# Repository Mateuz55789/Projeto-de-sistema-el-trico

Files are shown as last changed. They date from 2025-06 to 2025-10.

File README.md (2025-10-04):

# ⚡ Projeto de Sistema Elétrico Industrial

Este repositório apresenta o desenvolvimento completo de um sistema elétrico industrial de média/baixa tensão, realizado como trabalho final da disciplina de Projetos de Sistemas Elétricos do curso de Engenharia Elétrica no Centro Universitário Hermínio Ometto.  
O projeto foi desenvolvido para uma planta industrial de médio porte, simulada na cidade de Gramado/RS, atendendo aos requisitos técnicos da concessionária RGE (Grupo CPFL Energia) e seguindo as normas ABNT NBR 5410, NBR 14039, NBR 5356-11, GED-2855/2856, entre outras.

---

## 📌 Objetivos do Projeto

- Desenvolver uma solução elétrica completa e normatizada para uma planta industrial;  
- Atender com segurança e eficiência à demanda energética da instalação;  
- Garantir confiabilidade operacional, eficiência energética e conformidade normativa.

---

## 🔍 Conteúdo Técnico

O projeto abrange todas as etapas de planejamento elétrico, sendo essas:

### 🔌 Dimensionamento Elétrico

- Tabela de Cargas: potências ativas, reativas e aparentes de todos os equipamentos da planta;  
- Dimensionamento de Condutores e Disjuntores: seleção criteriosa com base em ampacidade, queda de tensão e seção mínima, conforme a NBR 5410;  
- Escolha de disjuntores.

### ⚙️ Partida de Motores

- Inversores de frequência CFW500 (WEG) para todos os motores das áreas produtivas;  
- Reatores de linha para mitigação de harmônicos e proteção dos inversores;  
- Proteções e disjuntores dedicados, conforme recomendações do fabricante.

### ⚡ Correção de Fator de Potência

- Dimensionamento e instalação de bancos de capacitores trifásicos (linha BCW - WEG);  
- Utilização de reatores de dessintonia (WEG DRW) e contatores CWBC para evitar ressonâncias;  
- Correção do fator de potência de 0,81 e 0,79 para 0,95, atendendo à resolução normativa da ANEEL.

### 🔄 Transformador e Subestação

- Transformador a seco de 1000 kVA (WEG) – ligação Dyn1, proteção IP-23;  
- Projeto de subestação abrigada, com entrada subterrânea e medição em média tensão;  
- Cálculo da margem de ampliação da carga (+35%) para o crescimento futuro da planta.

### ⚠️ Curto-Circuito

- Cálculos analíticos de corrente de curto-circuito trifásica e fase-terra;  
- Determinação da corrente de curto assimétrica e simulações com PSP-UFU;  
- Avaliação dos níveis de curto em todos os pontos críticos do sistema.

### 💡 Projeto Luminotécnico

- Simulação no Dialux Evo para ambiente de escritório industrial;  
- Definição de índice de reflexão, fator de depreciação, uniformidade e iluminância mínima;  
- Distribuição de 36 luminárias, garantindo 500 lux nas áreas de trabalho e 300 lux nos arredores, em conformidade com a NBR ISO/CIE 8995-1.

---

## 🛠️ Ferramentas Utilizadas

- Dialux Evo (simulação luminotécnica);  
- PSP-UFU (simulação de faltas e curtos);  
- AutoCAD (diagrama unifilar);
- Excel (cálculos).

---

## 👥 Integrantes do Grupo

- Emerson Falcão Albertini 
- Mateus Gomes Justino
- Bruno Henrique de Oliveira   
- Isaac Zulin Memari Espelho  

---

## 🏫 Instituição

Centro Universitário Hermínio Ometto – Araras/SP  
Curso: Engenharia Elétrica  
Período de entrega: Junho de 2025

---

## ⚠️ Restrições de Uso

Este projeto destina-se unicamente para fins didáticos e não deve ser utilizado em aplicações reais sem validação técnica profissional. Qualquer uso comercial, seja direto ou indireto, é estritamente proibido sem autorização expressa do autor. Para outras finalidades ou solicitações de uso que não se enquadrem nessas condições, por favor, entre em contato com o autor.

---

## ✉️ Contato

**Professor:** Daniel Augusto Pagi Ferreira  
**Email:** danielferreira@fho.edu.br

**Autor:** Mateus Gomes Justino  
**Email:** mateusjustino91@gmail.com  
**Linkedin:** www.linkedin.com/in/mateus-justino-ax01

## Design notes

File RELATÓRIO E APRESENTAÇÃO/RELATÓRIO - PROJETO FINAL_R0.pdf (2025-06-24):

CENTRO UNIVERSITÁRIO DA FUNDAÇÃO HERMÍNIO OMETTO

NÚCLEO DE ENGENHARIA

ENGENHARIA ELÉTRICA

Projetos de Sistemas Elétricos

P2

Nome completo | RA
Bruno Henrique de Oliveira | 109784
Emerson Falcão Albertini | 109667
Isaac Zulin Mamari Espelho Mateus Gomes Justino | 110490
| 109219

Araras

Junho 2025

## SUMÁRIO

### 1. INTRODUÇÃO

Este projeto tem como finalidade apresentar a proposta de implementação de um

sistema elétrico completo para uma indústria localizada na cidade de Gramado, no estado

do Rio Grande do Sul, sob concessão da empresa RGE – Rio Grande Energia. A RGE faz

parte do Grupo CPFL Energia, e por isso, adota as mesmas normas técnicas e padrões

exigidos pelo grupo, especialmente as normas GED-2855 (Fornecimento em Tensão

Primária – 15, 25 e 34,5 kV) e GED-2856 (Instalações de Subestação do Consumidor em

Média Tensão), aplicáveis ao fornecimento de energia em média tensão e à implantação

de subestações.

O trabalho foi desenvolvido em grupo, contemplando o dimensionamento,

especificação e planejamento da infraestrutura elétrica, com foco na segurança

operacional, eficiência energética e conformidade técnica. Para garantir a aderência às

exigências técnicas, foram aplicadas também as normas NBR 5356-11 (Transformadores

a seco – requisitos gerais) e NBR 14039 (Instalações elétricas de média tensão de 1 kV a

36,2 kV), que regulamentam os critérios construtivos e de instalação de equipamentos em

sistemas de média tensão.

Reconhecendo a importância de um ambiente industrial bem iluminado, o grupo

também desenvolveu um projeto luminotécnico completo, seguindo as diretrizes da

ABNT NBR ISO/CIE 8995-1, norma que estabelece os requisitos de iluminação para

ambientes de trabalho, garantindo conforto visual, segurança e desempenho adequado nas

áreas produtivas.

A demanda por soluções elétricas confiáveis e otimizadas é crescente,

especialmente em setores industriais com alto consumo de energia. Nesse contexto, o

grupo buscou atender às necessidades operacionais da planta, garantindo o fornecimento

adequado de energia para os equipamentos e processos, com o menor índice possível de

perdas, interrupções ou riscos elétricos.

O sistema foi projetado com base na NBR 5410, que regulamenta as instalações

elétricas de baixa tensão, e em outros requisitos técnicos aplicáveis. Foram considerados

critérios como o dimensionamento correto dos condutores e disjuntores, seleção de

inversores de frequência para motores, aplicação de dispositivos de proteção contra

sobrecorrente, curto-circuito e surtos, além da correção do fator de potência, visando

evitar penalidades tarifárias e melhorar o desempenho energético da instalação.

Este documento detalha todas as etapas do projeto, desde a análise de carga até a

escolha dos materiais e equipamentos, passando pelas soluções de proteção, controle e

distribuição de energia. A proposta final assegura não apenas o atendimento pleno às

exigências da operação industrial, mas também a redução de custos operacionais,

aumento da vida útil dos sistemas elétricos e conformidade com as normas técnicas

adotadas pelo Grupo CPFL.

### 2. DESENVOLVIMENTO

### 2.1. FATOR DE CORREÇÃO DE TEMPERATURA

Para determinar o fator de correção por temperatura, utilizamos como referência

a temperatura média anual registrada em Gramado no ano de 2024, conforme indicado

no Gráfico 1 e Tabela 1 Essa correção atende às exigências da norma NBR 5410, que

estabelece a necessidade de considerar fatores de correção para garantir o

dimensionamento adequado dos cabos elétricos em função das condições reais de

temperatura ambiente. O fator de correção obtido será aplicado no cálculo de todos os

Temperatura | Mínima (°C) | Máxima (°C)
Média | 13,10 | 23,25
Média Geral | 18,15

Gráfico 1 - Temperatura no ano de 2024 em Gramado/RS

Fonte: ABNT. NBR 5410:2004. Rio de Janeiro: ABNT, 2004. Tabela 40.

Tabela 1 – Média da temperatura em Gramado/RS

Figura 1 – Fatores de correção de temperatura

Fonte: Próprio autor

### 2.2. FATOR DE CORREÇÃO DE AGRUPAMENTO

Para este projeto, foi adotado o modelo de isolação EPR (Ethylene Propylene

Rubber) nos cabos de potência e controle especificados para os circuitos em análise. A

escolha desse tipo de isolação deve-se às suas excelentes características de resistência

térmica, estabilidade elétrica e durabilidade, garantindo maior confiabilidade e vida útil

da instalação elétrica. No processo de dimensionamento dos condutores, foram

considerados os fatores de agrupamento de cabos conforme estabelecido na norma ABNT

NBR 5410:2004, que regulamenta as instalações elétricas de baixa tensão. Esses fatores

de correção foram aplicados de acordo com as condições reais de instalação de cada

circuito, levando em conta aspectos como o número de circuitos agrupados, o tipo de

condutor, o método de instalação e a possibilidade de dissipação de calor. Tendo isso em

vista, foram adotados os seguintes fatores de agrupamento.

- Motores 1 a 4: fator de agrupamento adotado igual a 0,65;
- Motores 5 a 7: fator de agrupamento adotado igual a 0,70;
- Circuitos auxiliares: fator de agrupamento adotado igual a 0,80;
- Circuitos de aquecimento 1, 2 e 3: fator de agrupamento adotado igual a 0,80.

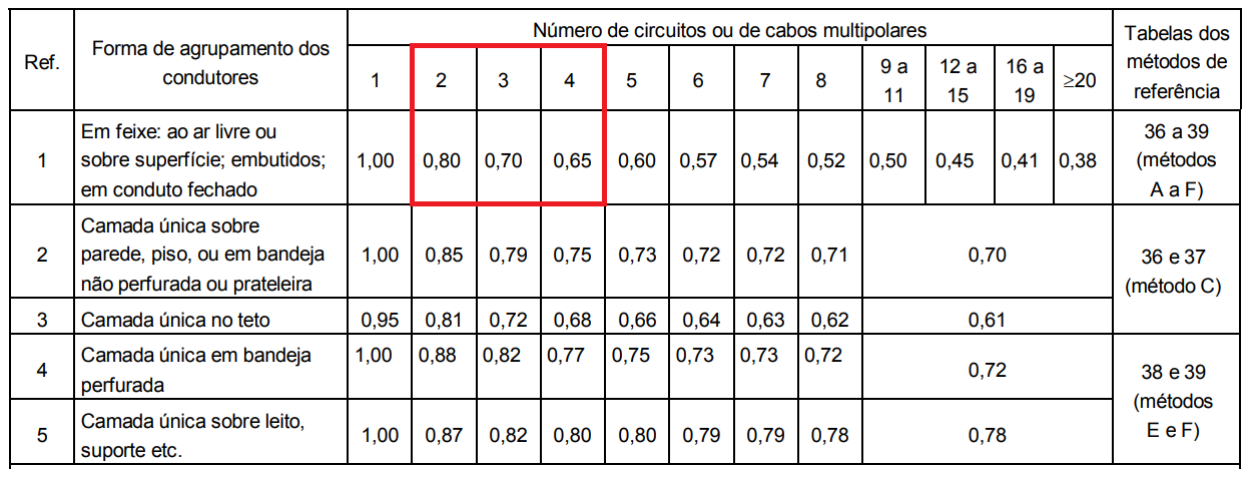
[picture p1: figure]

Foi considerado o método de instalação de referência B1, devido a

compatibilidade com as condições físicas reais referentes à infraestrutura de acomodação

dos cabos.

Figura 2 – Fatores de correção de agrupamento

Fonte: ABNT. NBR 5410:2004. Rio de Janeiro: ABNT, 2004. Tabela 42.

Fonte: ABNT. NBR 5410:2004. Rio de Janeiro: ABNT, 2004. Tabela 33.

Figura 3 – Métodos de instalação

### 2.3. MOTORES SELECIONADOS

Foram adotados motores da linha W22 iR3 Premium da WEG, uma das mais

reconhecidas fabricantes de máquinas elétricas do mundo. Essa linha de motores é

projetada para oferecer alta eficiência energética, robustez construtiva e confiabilidade

operacional, atendendo aos mais rigorosos padrões de desempenho e sustentabilidade.

Os motores W22 iR3 Premium são construídos com carcaça robusta em ferro

fundido, rolamentos de alta qualidade, pintura anticorrosiva e ventilação otimizada,

garantindo maior vida útil e redução de custos com manutenção. Além disso, apresentam

baixos níveis de ruído e vibração, contribuindo para ambientes industriais mais seguros e

confortáveis.

Esses motores são classificados como Nível de Eficiência IR3 (Premium

Efficiency), proporcionando redução de consumo de energia elétrica e alinhamento com

as normas de eficiência energética vigentes. Os modelos selecionados estão conforme a

Tabela 2 a seguir.

Motores

Potência
(HP)

Corrente Nominal
em 380V (A)

Corrente Nominal
em 440V (A)

Tensão de
| | | | Alimentação (V) | RPM
Motor 5 | 20 | 30,35 | 26,1 | 380 / 440 | 1775
Motor 3 e 7 | 30 | 44,14 | 38,1 | 380 / 440 | 1770
Motor 1 | 50 | 70,88 | 61,2 | 380 / 440 | 1775
Motor 6 | 75 | 101,9 | 88,0 | 380 / 440 | 1780
Motor 2 | 125 | 166,8 | 144,0 | 380 / 440 | 1785
Motor 4 | 150 | 202,65 | 175,0 | 380 / 440 | 1785

Conforme orientações presentes no próprio manual técnico da WEG, para

determinar a corrente nominal de operação de um motor trifásico em uma tensão diferente

da nominal de catálogo, deve-se aplicar um fator de correção. No caso de motores com

corrente nominal especificada para 440 V que operem em 380 V, a WEG recomenda

utilizar a relação In(380V) = In(440V) ∗ 1,158, garantindo assim um dimensionamento

adequado dos dispositivos de proteção, cabos e alimentação elétrica.

Para a elaboração deste trabalho, foram utilizados os valores de rendimento e

fator de potência conforme apresentados no catálogo técnico da WEG. Assim, foram

considerados os valores correspondentes a 100% de carga, conforme a tabela do

fabricante, garantindo coerência com as condições nominais de operação dos motores.

Tabela 2 – Características dos motores selecionados

Fonte: Próprio autor

### 2.4. TABELA DE CARGAS

Para dar início ao dimensionamento elétrico do projeto, foi elaborada a tabela de

cargas do sistema, reunindo todas as informações essenciais sobre cada equipamento ou

ponto de consumo. Nessa etapa, foram identificadas as cargas previstas, suas potências

nominais, tensões de alimentação, correntes calculadas, fator de potência e respectivas

localizações dentro da instalação.

A organização dessas informações em uma tabela facilita a análise técnica do

sistema como um todo, servindo de base para o cálculo dos condutores, a definição dos

disjuntores e o planejamento da distribuição elétrica. Essa etapa também contribui para

garantir que todos os elementos do sistema atendam aos critérios de segurança e

desempenho exigidos pela norma NBR 5410.

A seguir, apresenta-se a Tabela 3 de cargas completa, que norteou todas as

decisões de dimensionamento adotadas ao longo do projeto

Tabela 3 – Cargas

Áreas Carga

Potência
mecânic
a (HP)

Fator de
potência

Rendim
ento

Potênci
a ativa
(kW)

Potência
reativa
(kVAr)

Potência
aparente
(kVA)

1

Motor 1 | 50,00 | 0,84 | 0,954 | 37,00 | 20,08 | 46,17
Motor 2 | 125,00 | 0,86 | 0,954 | 92,00 | 45,93 | 112,13
Motor 3 | 30,00 | 0,81 | 0,936 | 22,00 | 12,90 | 29,02
Motor 4 | 150,00 | 0,86 | 0,958 | 110,00 | 56,13 | 133,51

2

Motor 5 | 20,00 | 0,81 | 0,930 | 15,00 | 8,80 | 19,91
Motor 6 | 75,00 | 0,86 | 0,954 | 55,00 | 28,07 | 67,04
Motor 7 | 30,00 | 0,81 | 0,936 | 22,00 | 12,90 | 29,02

3

Auxiliar | - | 0,92 | 1,000 | 75,00 | 29,39 | 81,52
Auxiliar | - | 0,92 | 1,000 | 75,00 | 29,39 | 81,52
Aquec. 1 | - | 1,00 | 1,000 | 30,00 | 0,00 | 30,00
Aquec. 2 | - | 1,00 | 1,000 | 25,00 | 0,00 | 25,00
Aquec. 3 | - | 1,00 | 1,000 | 40,00 | 0,00 | 40,00

Fonte: Próprio autor

### 2.5. CONDUTORES E O DISJUNTOR BT PARA CADA CARGA

Garantir a segurança e o bom desempenho do sistema elétrico exige um

dimensionamento adequado dos condutores e dispositivos de proteção. Nesta etapa do

projeto, adotamos como referência a norma NBR 5410, que estabelece os critérios

mínimos para instalações elétricas em baixa tensão.

Cada carga foi analisada individualmente, considerando características como a

potência, a corrente nominal, o regime de funcionamento e a distância até o painel de

distribuição. A partir desses dados, foram selecionados os cabos e disjuntores mais

apropriados, levando em conta fatores técnicos como a capacidade de condução de

corrente, a queda de tensão admissível, o método de instalação utilizado e os ajustes

necessários conforme a temperatura ambiente e o agrupamento de circuitos.

Além disso, optamos por utilizar exclusivamente disjuntores da marca WEG,

buscando padronização, facilidade de aquisição e confiabilidade nos ajustes. A escolha

se deu também pela qualidade reconhecida dos produtos da marca e pela praticidade na

instalação e regulagem.

Na Tabela 4 a seguir, apresentamos a relação completa dos condutores e

disjuntores definidos para cada carga do sistema, com base nos critérios técnicos adotados

ao longo do desenvolvimento do projeto:

Tabela 4 - Condutores Áreas

Fonte: Próprio autor

Área | Carga | Cabo mm² - Ampacidade

Cabo mm² -
queda de
tensão

Cabo mm² -
seção mínima

Cabo mm² -
escolhido

Corrente do
Disjuntor BT
(A)

Regulagem do
Disjuntor BT
(A

Modelo Disjuntores
WEG (Reguláveis)

1

Motor 1 | 25 | 2,5 | 16 | 25 | 80 | 80 | MPW80-3-U080
Motor 2 | 95 | 6 | 50 | 95 | 200 | 180 | DWB250N200-3DF
Motor 3 | 16 | 1,5 | 6 | 16 | 50 | 50 | MPW80-3-U050
Motor 4 | 120 | 10 | 70 | 120 | 250 | 210 | DWB250N-250-3DF

2

Motor 5 | 6 | 1 | 4 | 6 | 32 | 32 | MPW40-3-U032
Motor 6 | 35 | 4 | 25 | 35 | 125 | 105 | DWB160N-125-3DF
Motor 7 | 10 | 1,5 | 6 | 10 | 50 | 47 | MPW80-3-U050

3

Auxiliar | 50 | 6 | 35 | 50 | 125 | 125 | DWB160N125-3DF
Auxiliar | 50 | 6 | 35 | 50 | 125 | 125 | DWB160N125-3DF
Aquec. 1 | 10 | 2,5 | 6 | 10 | 50 | 48 | DWB160N50-3DF
Aquec. 2 | 10 | 2,5 | 6 | 10 | 40 | 40 | DWB160N40-3DF
Aquec. 3 | 16 | 4 | 10 | 16 | 63 | 63 | DWB160N63-3DF

Para a definição das bitolas dos cabos utilizados na instalação elétrica, foram

adotados três critérios distintos de dimensionamento, conforme as boas práticas da

engenharia e as normas técnicas aplicáveis:

Ampacidade: Verificou-se a corrente nominal dos circuitos com base na potência

instalada, utilizando a fórmula:

Ip =

Pn
√3 ⋅ V ⋅ cosφ ⋅ η

Onde:

- Ip = Corrente nominal do circuito (A)
- Pn = Potência ativa nominal da carga (W)
- V = Tensão entre fases (V)
- cosφ = Fator de potência (adimensional), representa a relação entre potência ativa

e aparente

- η = Rendimento da carga ou equipamento (adimensional, geralmente entre 0,8 e

1)

A bitola foi inicialmente determinada para garantir que o cabo suporte a corrente

exigida, considerando as condições de instalação e a temperatura ambiente.

Queda de Tensão: Avaliou-se a queda de tensão admissível nos circuitos,

conforme a fórmula:

S = √3 ⋅ ρ ⋅

1
e(%) ⋅ Vff²

⋅∑ (P ⋅ l)

Onde:

- S = Seção do condutor (mm²)
- ρ = Resistividade elétrica do material do condutor (Ω·mm²/m) - Cobre

## - e(%) = Queda de tensão admissível (em porcentagem, ex: 4% → 0,04)

- Vff² = Tensão entre fases (V) elevado ao quadrado
- ∑ (P ⋅ l) = Soma dos produtos entre potências de carga (W) e seus respectivos

comprimentos (m)

- P = Potência da carga (W)
- l = Comprimento do trecho do condutor até a carga (m)

Esse critério garante que a tensão na extremidade da carga esteja dentro dos limites

permitidos, evitando perdas excessivas e mau funcionamento dos equipamentos.

Seção Mínima Permitida: Considerou-se também a seção mínima exigida pelas

normas para fins de proteção mecânica e segurança da instalação.

Após a análise individual por cada método, foi adotada como definitiva a bitola

mais viável e segura, escolhida com base no valor mais restritivo entre os três,

assegurando a conformidade técnica, o desempenho eficiente e a segurança da instalação

elétrica.

De acordo com a NBR 5410, em sua seção 6.2.7.2.2, recomenda-se que a queda

de tensão entre o ponto de entrega e qualquer ponto de utilização não ultrapasse 4% da

tensão nominal em circuitos de força e iluminação. No entanto, com o objetivo de garantir

uma maior margem de segurança, minimizar perdas elétricas e possibilitar futuras

ampliações da carga, adotou-se para os cálculos uma queda de tensão máxima de 2%.

Essa decisão visa assegurar um melhor desempenho do sistema e aumentar sua

confiabilidade operacional ao longo do tempo.

### 2.6. CONDUTORES E O DISJUNTOR BT PARA CADA ÁREA

Além do dimensionamento individual por carga, também foi necessário definir os

condutores e disjuntores de baixa tensão para cada área do sistema, considerando o

agrupamento de cargas e a distribuição dos circuitos dentro da planta. Essa etapa teve

como objetivo garantir não apenas a proteção adequada, mas também a organização e

eficiência na distribuição elétrica.

A escolha dos condutores e disjuntores foi feita com base nas características

elétricas das áreas, levando em conta a potência total demandada, o tipo de instalação, a

distância em relação ao quadro de distribuição e os fatores de correção aplicáveis. Assim

como no item anterior, seguimos as diretrizes da norma NBR 5410 para assegurar

conformidade técnica e segurança.

Mantivemos a padronização dos disjuntores utilizando novamente os modelos da

marca WEG, escolhidos por sua qualidade, facilidade de regulagem e disponibilidade no

mercado. Essa uniformidade facilita a manutenção e o entendimento do sistema como um

todo.

Na sequência, apresentamos a Tabela 5 com as especificações dos cabos e

disjuntores definidos para cada área do projeto, com base nos critérios técnicos levantados

durante a etapa de dimensionamento:

Tabela 5 - Condutores Áreas QGF

Fonte: Próprio autor

Para os cálculos das bitolas dos condutores das áreas foram usados os mesmos

princípios e fórmulas do item 2.5.

### 2.7. CONDUTORES E O DISJUNTOR GERAL PARA O QGF

Além do dimensionamento individual por carga, também foi realizado o

dimensionamento do disjuntor geral do Quadro de Distribuição Final (QDF),

considerando a soma das correntes dos circuitos agrupados, de acordo com a potência

total instalada e os critérios normativos. A corrente nominal do disjuntor foi definida com

base nos cálculos de ampacidade, queda de tensão e seção mínima dos condutores,

conforme exigido pela ABNT NBR 5410:2004.

Com o objetivo de garantir segurança operacional e flexibilidade para futuras

ampliações, foi adotada uma margem de segurança adicional de 35% sobre a corrente

nominal calculada, assegurando uma capacidade extra de condução de corrente sem

necessidade de substituição imediata do disjuntor em caso de expansão da carga instalada.

Assim como nas demais partes do sistema, mantivemos a padronização da linha

de disjuntores da marca WEG, priorizando a uniformidade dos dispositivos, a facilidade

de aquisição, a confiabilidade e a praticidade de manutenção. Essa abordagem contribui

para a padronização técnica do sistema elétrico, facilitando diagnósticos e intervenções

futuras.

Na sequência, apresentamos a Tabela 6 com as especificações dos cabos e do

disjuntor definido para o QGF, com base nos critérios técnicos levantados durante a etapa

de dimensionamento:

Área | Ampacidade (mm²) | Queda de tensão (mm²) | Seção mínima (mm²) | Cabo escolhido (mm²) | Corrente Disjuntor (A) | Modelo Disjuntores
1 | 240 | 95 | 2x95.00 | 2x95.00 | 500 | DWB650S500-3DA
2 | 50 | 50 | 70 | 70 | 180 | DWB250N200-3DF
3 | 185 | 95 | 185 | 185 | 400 | DWB400N400-3DA

Tabela 6 - Condutores QGF

Fonte: Próprio autor

Para os cálculos das bitolas dos condutores das áreas foram usados os mesmos

princípios e fórmulas do item 2.5.

Área Cabo mm² - Ampacidade

Cabo mm²
- queda de
tensão

Cabo mm²
- seção
mínima

Cabo mm² -
escolhido

Corrente
do
Disjuntor
(A)

Modelo Disjuntor

QGF | 4x180 | 70 | 4x150 | 4x180 | 1600

DWA1600S-1600-
3ET

### 2.8. CHAVES DE PARTIDA

O grupo definiu que o sistema elétrico seria destinado a uma indústria alimentícia

de médio porte, o que condiz com os dados das cargas descritas no projeto base. A

instalação encontra-se dividida em três setores, compostos por motores elétricos, sistemas

de aquecimento e cargas auxiliares.

Considerando o tipo de indústria, o grupo optou por utilizar inversores de

frequência para a partida de todos os motores localizados nas áreas 1 e 2. Essa decisão foi

tomada com base nos equipamentos geralmente utilizados nesse segmento industrial

como esteiras, misturadores e bombas que exigem controle de velocidade, automação e

monitoramento contínuo.

Na área 3 estão localizados os sistemas de aquecimento e as cargas auxiliares.

Considerou-se que as cargas auxiliares correspondem a dois QDFLs (Quadros de

Distribuição de Força e Luz), responsáveis pela alimentação das lâmpadas e tomadas de

toda a fábrica. Por se tratarem de cargas de perfil resistivo, foi definido ao uso apenas de

disjuntores alimentadores para seu dimensionamento.

### 2.8.1. INVERSORES

Para o acionamento dos motores nas áreas 1 e 2, o grupo optou pela utilização da

linha de inversores de frequência CFW500 da WEG. Essa escolha se deu principalmente

por se tratar de um equipamento nacional, com boa disponibilidade no mercado. Além

disso, o modelo CFW500 apresenta bom desempenho no controle de velocidade, possui

recursos de proteção, comunicação com CLPs e compatibilidade com diversos tipos de

cargas.

Também foi definido que os inversores operariam no modo Heavy Duty (HD),

devido às características mais exigentes das aplicações, como partidas frequentes e

necessidade de torque elevado, comuns nesse tipo de indústria. No entanto, para o motor

4, optou-se pelo regime Normal Duty (ND), já que não há, na linha CFW500 da WEG,

um modelo que atenda à corrente requerida em HD para essa carga.

A Tabela 7 a seguir apresenta a relação dos inversores definidos para cada motor,

juntamente com suas respectivas correntes:

Tabela 7 - Inversores utilizados

Motor | Corrente do Motor | Modo de Operação | Corrente do Drive | Drive Escolhido
Motor 1 | 70.15 | HD | 73 | CFW500F88P0T4
Motor 2 | 170.37 | HD | 180 | CFW500G0211T4
Motor 3 | 44.09 | HD | 49 | CFW500E49P0T4
Motor 4 | 202.85 | ND | 211 | CFW500G0211T4
Motor 5 | 30.25 | HD | 31 | CFW500D31P0T4
Motor 6 | 101.85 | HD | 115 | CFW500G0142T4
Motor 7 | 44.09 | HD | 49 | CFW500E49P0T4
| | Fonte: Próprio autor

### 2.8.2. REATOR DE LINHA

Com o objetivo de proteger os inversores de frequência e melhorar a qualidade da

energia no sistema, o grupo adotou a utilização de reatores de linha (também chamados

de reatores de entrada) em todos os circuitos com inversores. Esses dispositivos são

instalados entre o disjuntor de proteção e o inversor, e têm como principais funções:

reduzir a distorção harmônica de corrente, minimizar picos de corrente de entrada e

proteger os componentes eletrônicos contra variações súbitas de tensão provenientes da

rede.

A utilização desses reatores é especialmente recomendada em instalações

industriais, onde há uma elevada concentração de cargas não lineares e motores de médio

e grande porte. Além de contribuírem para o atendimento a normas como a IEEE 519,

que estabelece limites para distorções harmônicas, os reatores ajudam a aumentar a vida

útil dos inversores e demais equipamentos sensíveis conectados ao sistema.

O grupo optou por não utilizar reatores de saída, pois as distâncias entre os

inversores e os motores são de apenas 5 metros. Esses reatores são indicados apenas em

casos de cabos longos, onde há risco de sobretensões por reflexo de onda (reflected wave).

Para o dimensionamento genérico dos reatores de linha, considera-se a corrente

nominal do inversor e a impedância desejada, conforme a equação:

XL =

100 × Inominal
Vlinℎa × 2 × %Z

Onde:

- XL é a reatância do indutor (Ω)

- Vlinha é a tensão entre fases da rede (380 V)
- %Z é a impedância desejada (neste projeto, 3%)
- Inominal é a corrente nominal do inversor

No entanto, conforme o manual do CFW500 da WEG (página 119), o fabricante

recomenda uma fórmula específica para determinar a reatância de linha com base na

queda de tensão desejada:

L =

1592 × ΔV × Ve
Is, nom × f

[µH]

Onde:

- ΔV - queda de tensão desejada (%)
- Ve - tensão de fase na entrada do inversor (V)
- Is,nom - corrente nominal de saída do inversor (A)
- f - frequência da rede (Hz)

Durante o desenvolvimento do projeto, foi constatada a ausência de informações

técnicas detalhadas sobre os reatores da linha WEG, como valores precisos de indutância

e corrente. Por esse motivo, o grupo optou por utilizar reatores do fabricante Rockwell,

que fornece todos os dados necessários para um dimensionamento seguro e adequado.

A Tabela 8. a seguir apresenta a relação dos reatores definidos para cada inversor,

contendo seus respectivos modelos e características elétricas.

Tabela 8 - Reatores utilizados

Drive | Corrente do Drive (A) | Indutância Necessária (mH) | Reator Escolhido | Dados do Reator
CFW500F88P0T4 | 73 | 0.2399 | 1321-3R80-B | 80A e 0.4mH
CFW500G0211T4 | 180 | 0.0973 | 1321-3R200-B | 200A e 0.11mH
CFW500E49P0T4 | 49 | 0.3574 | 1321-3R55-B | 55A e 0.5mH
CFW500G0211T4 | 211 | 0.0830 | 1321-3R200-B | 200A e 0.11mH
CFW500D31P0T4 | 31 | 0.5649 | 1321-3R35-B | 35A e 0.8mH
CFW500G0142T4 | 115 | 0.1523 | 1321-3R130-B | 130A e 0.2mH
CFW500E49P0T4 | 49 | 0.3574 | 1321-3R55-B | 55A e 0.5mH
| | Fonte: Próprio autor

### 2.8.3. PROTEÇÃO

Para garantir a proteção adequada dos inversores de frequência e das instalações,

foram especificados disjuntores termomagnéticos dedicados a cada uma das partidas com

inversores nas áreas 1 e 2. Esses dispositivos são responsáveis por proteger os circuitos

contra curtos-circuitos e sobrecorrentes, assegurando a segurança do sistema e a

integridade dos equipamentos.

O dimensionamento dos disjuntores deve considerar não apenas a corrente

nominal do inversor e o seu regime de operação (ND ou HD), mas também a corrente de

curto-circuito presumida no ponto de instalação. Isso garante que o disjuntor seja capaz

de interromper uma falha sem comprometer sua estrutura ou danificar a instalação. Além

disso, é essencial escolher a curva de disparo adequada (como curva C ou D),

considerando a inércia da carga e a velocidade de resposta necessária.

Uma forma genérica para estimar a corrente nominal mínima do disjuntor é:

Idisjuntor ≥ Iinversor × Fserviço

Onde:

- Iinversor é a corrente nominal do inversor;
- Fserviço o é um fator de segurança, geralmente entre 1,1 e 1,25 dependendo da

aplicação.

Além disso, a capacidade de interrupção do disjuntor deve ser superior à corrente

de curto-circuito disponível no ponto de instalação, garantindo sua atuação em situações

críticas.

Seguindo as orientações do fabricante WEG, o grupo utilizou a tabela de

Especificações de Fusíveis e Disjuntores presente no Anexo B, página 157 do Manual do

Usuário do Inversor CFW500. Essa tabela foi adotada conforme recomendado pela

própria WEG, que especifica os modelos adequados de disjuntores e fusíveis para cada

tipo de inversor, com base em testes e nas correntes reais de pico suportadas pelo

equipamento.

A Tabela 9 com os disjuntores especificados para cada inversor de frequência,

incluindo suas respectivas correntes nominais e características.

Tabela 9 - Disjuntores selecionados

Drive | Corrente do drive (A) | Disjuntor Recomendado | Corrente do Disjuntor | Cap. de Interr. de CC
CFW500F88P0T4 | 73 | MPW80-3-U080 | 65-80 A (ajustável) | 65kA
CFW500G0211T4 | 180 | DWB250N200-3DF | 200 A (ajustável) | 36kA
CFW500E49P0T4 | 49 | MPW80-3-U050 | 40-50 A (ajustável) | 65kA
CFW500G0211T4 | 211 | DWB250N-250-3DF | 250 A (ajustável) | 36kA
CFW500D31P0T4 | 31 | MPW40-3-U032 | 25-32 A (ajustável) | 50kA
CFW500G0142T4 | 115 | DWB160N-125-3DF | 125 A (ajustável) | 36kA
CFW500E49P0T4 | 49 | MPW80-3-U050 | 40-50 A (ajustável) | 65kA
| | Fonte: Próprio autor

### 2.8.4. DIAGRAMA DE LIGAÇÃO

A Figura 4 abaixo está apresentado o diagrama de ligação genérico de um sistema

de partida utilizando inversor de frequência, responsável pelas partidas dos motores

listados neste projeto.

Figura 4 - Esquema de ligação inversor de frequência

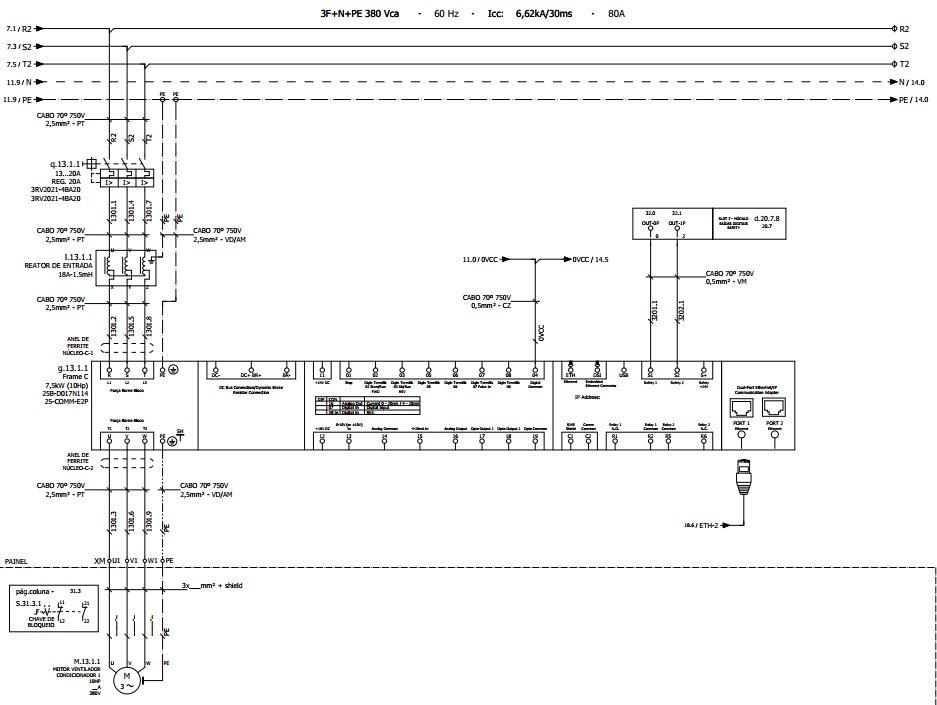
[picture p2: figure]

Fonte: Próprio autor

### 2.9. CORREÇÃO DE FATOR DE POTÊNCIA

A correção do fator de potência (FP) é essencial em instalações industriais para

reduzir o consumo de potência reativa, minimizar perdas elétricas, evitar penalidades

aplicadas pela concessionária. Essa correção é realizada por meio da instalação de bancos

de capacitores devidamente dimensionados de acordo com a demanda reativa do sistema.

### 2.9.1. METODOLOGIA DE CÁLCULO

A correção do fator de potência foi implementada nas Áreas 1 e 2 da planta

industrial em função dos baixos níveis de fator de potência medidos, os quais se

encontravam inferiores ao limite mínimo de 0,92, conforme exigido pela Resolução

Normativa nº 1000, de 07 de dezembro de 2021, da Agência Nacional de Energia Elétrica

(ANEEL).

Valores de fator de potência abaixo desse limite acarretam penalidades tarifárias,

conforme definido pela concessionária local, além de resultar em um sistema elétrico

menos eficiente, com maior circulação de corrente reativa, sobrecarga em

transformadores e cabos, e redução da vida útil de equipamentos elétricos.

A potência reativa necessária para os bancos de capacitores foi calculada com base

nas seguintes expressões:

- Cálculo dos fatores de potência e seus respectivos ângulos

Os cálculos de fator de potência e seus respectivos ângulos se deu pelos valores

da Tabela 10 e pelas seguintes formulas:

FP =

Potência Ativa
Potência Aparente

& Cos(θ) = FP

Tabela 10 - Potências de cada área

Área | Poência ativa total (kW) | Poência reativa total (kVAr) | Poência aparente total (KVA)
1 | 261,00 | 135,04 | 320,84
2 | 92,00 | 49,76 | 115,97
3 | 245,00 | 58,79 | 258,04
| | Fonte: Próprio autor

Através dos resultados da Tabela 11 notamos que somente as áreas 1 e 2 necessitam

de correção em seus fatores de potência.

Tabela 11 – Fator de potência de cada área calculado

Área | FP. total por área | Ângulo
1 | 0,813 | 35,56
2 | 0,793 | 37,50
3 | 0,949 | 18,30
| Fonte: Próprio autor
- Potência reativa total antes da correção e capacidade mínima do banco:

A potência reativa total de cada área se deu pela somatória das potencias reativas

de cada motor, conforme a Tabela 12 e Tabela 13 a seguir.

Tabela 12 - Potência reativa total área 1

Componente | Potência reativa (kVAr)
| | Potência necessária proveniente do banco de capacitores (kVAr)
Motor 1 | 20,08
Motor 2 | 45,93
Motor 3 | 12,90
Motor 4 | 56,13
Total | 135,04 | 49,25
| Fonte: Próprio autor

Tabela 13 - Potência reativa total área 2

Componente | Potência reativa (kVAr) | Potência necessária
| | proveniente do banco de capacitores (kVAr)
Motor 1 | 19,91
Motor 2 | 67,04
Motor 3 | 29,02
Total | 49,76 | 19,53
| Fonte: Próprio autor
- Potência reativa desejada após a correção: Qárea1 = Q − P ⋅ tan(arccos(FPnovo))

Qárea2 = Q − P ⋅ tan(arccos(FPnovo))

- Potência reativa necessária para o banco de capacitores:
Qc = Q − P ⋅ tan(arccos(FPantigo))

Com o valor de Qc, foi possível determinar a quantidade de potência reativa que

deve ser inserida no sistema por meio dos capacitores, a fim de elevar o fator de potência

ao valor desejado de FPnovo = 0,95 para ambas as áreas, atendendo aos requisitos da

concessionária e melhorando o desempenho elétrico da instalação.

### 2.9.2. BANCO DE CAPACITORES

Foram especificados bancos de capacitores da linha BCW da WEG, fixos de

correção do fator de potência. Esses capacitores trifásicos são dimensionados para

operação em redes com tensão nominal de até 380 V e frequência de 60 Hz, sendo ambos

os bancos compostos por uma unidade capacitiva UCWT HD, possuindo construção

robusta com filme de polipropileno metalizado e grau de proteção IP-32 o que assegura

uma proteção contra quedas verticais de gotas d’água com inclinação de 15 graus e

objetos sólidos com diâmetro maior que 2,5mm, o que garante:

- Elevada confiabilidade operacional,
- Alta resistência a sobrecargas,
- Autoproteção contra falhas dielétricas,

Na Tabela 14 temos os modelos adotados para cada área e na Figura 5 temos

um exemplo de banco de capacitores WEG BCW.

Tabela 14 - Modelos dos bancos de capacitores utilizados

Área | Banco de Capacitores | Potência Reativa do Banco (kVAr) | Unidade Capacitiva do Banco | Qtd.
1 | BCW50V40 T | 50 | UCWT50V40 U28 HD | 1
2 | BCW20V40 T | 20 | UCWT20V40 Q26 HD | 1
| | Fonte: Próprio autor

Figura 5 - Banco de capacitores WEG BCW

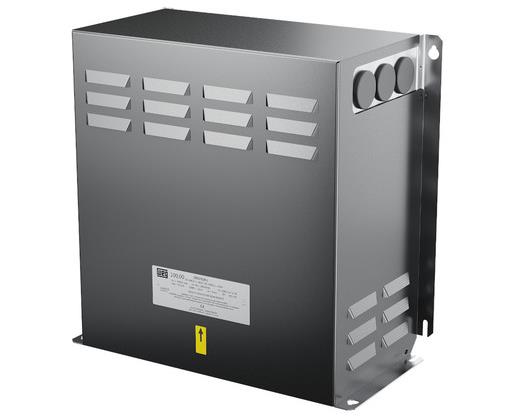
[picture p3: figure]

Fonte: WEG-capacitores-para-correção-do-fator-de-potencia

### 2.9.3. REATORES DE DESSINTONIA

Em ambientes com cargas não lineares, como inversores de frequência, utilizam-

se reatores de dessintonia conectados com os capacitores para evitar ressonâncias

harmônicas, proteger os equipamentos e garantir estabilidade no sistema.

Para proteger os capacitores contra harmônicos, foram adotados reatores de

dessintonia com frequência de dessintonia em 160,4 Hz, correspondendo a 14% de

dessintonia, conforme mostra a Tabela 15 e na Figura 6 temos um exemplo de um reator

de dessintonia.

Essa solução proporciona:

- Mitigação de distorções harmônicas no sistema,
- Aumento da vida útil dos capacitores,
- Manutenção da qualidade da energia elétrica,
- Melhoria do desempenho global do sistema de compensação reativa.

Tabela 15 - Modelos dos reatores de dessintonia utilizados

Área | Modelo | Tensão (V) | Potência Reativa
| | | (kVAr) | Corrente (A) | Indutância
| | | | | (mH)
1 | DRW14-1,22V40 | 380 | 51 | 77,7 A | 1,222
2 | DRW14-2,85V40 | 380 | 21,9 | 33,2 A | 2,852
| | | Fonte: Próprio autor

Figura 6 - Reator de dessintonia WEG DRW

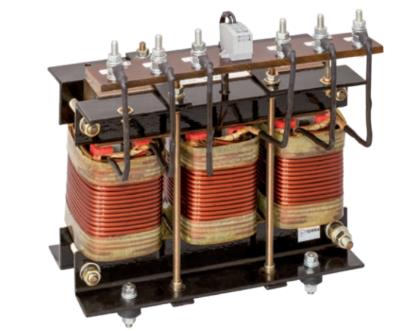
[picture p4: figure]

Fonte: WEG-capacitores-para-correção-do-fator-de-potencia

### 2.9.4. CONTATORES

O acionamento dos bancos de capacitores é feito por contatores da linha CWBC

da WEG, que incluem resistores de limitação de corrente (pré-carga) de inserção para

proteger os capacitores contra picos de corrente durante a manobra do contator, sendo a

Tabela 16 e Figura 7 os modelos selecionados.

Tabela 16 - Modelo dos contatores utilizados

Área | Modelo do Contator | Tensão Nominal de Isolação (V) | Corrente Nominal (A)
1 | CWBC65-21-30D23 | 690 | 65
2 | CWBC25-21-30C15 | 690 | 25
| | Fonte: Próprio autor

Esses contatores atendem à norma IEC 60947-4-1, garantindo operação segura

e confiável em ambientes industriais.

Figura 7 – Contator CWBC

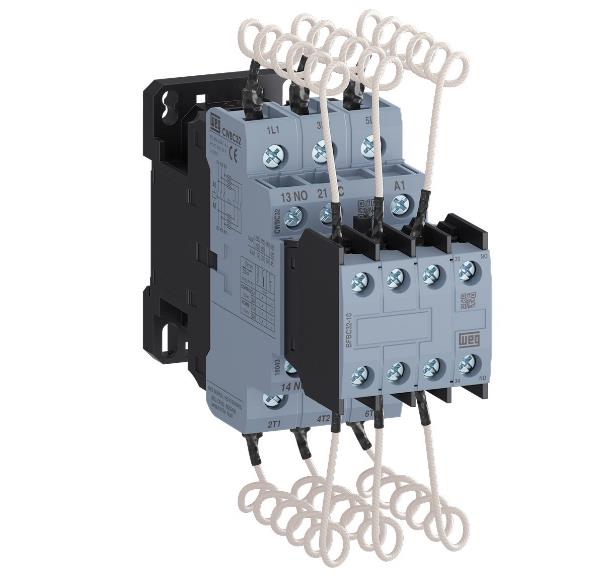
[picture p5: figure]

Fonte: Contatores-CWBC-WEG

### 2.9.5. DISJUNTORES

A proteção do sistema foi realizada com disjuntores termomagnéticos da linha

DWB da WEG, dimensionados com base nas correntes corrigidas após inserção dos

reatores e na seção dos cabos utilizados, na Tabela 17 e Figura 8 vemos os modelos

selecionados.

Tabela 17 - Modelos dos disjuntores de proteção

Área | Modelo do Disjuntor | Corrente Nominal (A) | Corrente de interrupção (KA) | Polos
1 | DWB160B125-3DX | 125 | 16 | 3
2 | DWB160B50-3DX | 50 | 16 | 3
| | Fonte: Próprio autor

Esses disjuntores protegem contra sobrecargas e curtos-circuitos, assegurando a

integridade do sistema e dos equipamentos.

Figura 8 – Disjuntor DWB

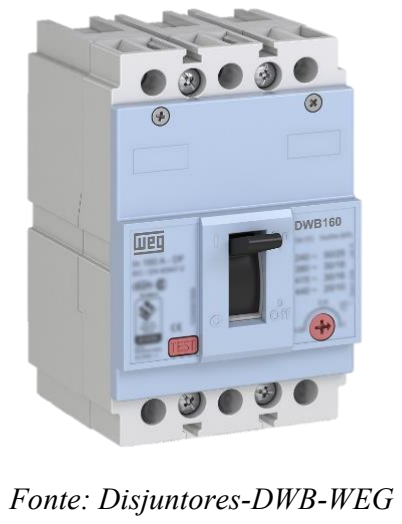
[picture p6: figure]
Fonte: Disjuntores-DWB-WEG

### 2.9.6. RESUMO DE COMPONENTES PARA A CORREÇÃO DO FP

A Tabela 18 apresenta um resumo dos componentes necessários em cada área

para a correção do fator de potência. Todos os componentes listados são da fabricante

WEG e integram o conjunto recomendado para essa finalidade, sendo indicada a

utilização conjunta dos modelos especificados.

Tabela 18 - Resumo de componentes por área

Item | Área 1 | Área 2
Capacitor | WEG BCW50V40 T | WEG BCW20V40 T
Reator de Dessintonia | WEG DRW14-1,22V40 | WEG DRW14-2,85V40
Contator | WEG CWBC65-21-30D23 | WEG CWBC25-21-30C15
Disjuntor | WEG DWB160B125-3DX | WEG DWB160B50-3DX
Fator de Potência Inicial (FP₁) | 0,81 | 0,79
Fator de Potência Corrigido (FP₂) | 0,95 | 0,95
| Fonte: Próprio autor

### 2.10. TRANSFORMADOR DE POTÊNCIA

Para especificarmos adequadamente o transformador de potência da instalação,

é necessário, primeiramente, calcular a potência aparente (kVA) de cada setor da planta

industrial. Esse valor é obtido a partir do levantamento individual das cargas de cada

máquina ou equipamento. Em seguida, realiza-se a somatória das potências aparentes de

todos os setores, resultando na potência aparente total da instalação, que servirá de base

para a escolha do transformador.
É importante destacar que, ao especificar o transformador, foi considerado um

acréscimo de 35% sobre a potência aparente total da instalação, com o objetivo de

acomodar futuras expansões da planta industrial, como a adição de novas máquinas ou

aumento da demanda nos setores existentes. Essa margem garante maior flexibilidade

operacional, evitando a necessidade de substituição do transformador em curto ou médio

prazo. A Tabela 19 apresenta a distribuição das potências aparentes por máquina e por

setor, enquanto a Tabela 20 consolida esses dados e demonstra a potência total que deverá

ser suprida pelo transformador.

Tabela 19 - Potências de cada setor

Área | Carga | Potência ativa (kW)

Potência
reativa (kVAr)

Potência aparente
(kVA)

1

Motor 1 | 37,00 | 20,08 | 46,17
Motor 2 | 92,00 | 45,93 | 112,13
Motor 3 | 22,00 | 12,90 | 29,02
Motor 4 | 110,00 | 56,13 | 133,51

2

Motor 5 | 15,00 | 8,80 | 19,91
Motor 6 | 55,00 | 28,07 | 67,04
Motor 7 | 22,00 | 12,90 | 29,02

3

| Auxiliar | 75,00 | 29,39 | 81,52
| Auxiliar | 75,00 | 29,39 | 81,52
| Aquecimento 1 | 30,00 | 0,00 | 30,00
| Aquecimento 2 | 25,00 | 0,00 | 25,00
| Aquecimento 3 | 40,00 | 0,00 | 40,00
| | Fonte: Próprio autor

Tabela 20 - Cálculo da potência mínima para o Trafo

Pot. Ativa Total (KW) | Pot. Aparente Total (kVA) | Pot. Reativa Total (KVAr) | Aumento De Carga (%) | Potência do trafo (KVA)
598,00 | 694,85 | 243,59 | 35,00 | 938,05
| | Fonte: Próprio autor

Com base no levantamento das cargas da planta industrial, foi especificado o

transformador de potência que será responsável por alimentar integralmente a fábrica.

Optou-se pelo modelo 14543301 da WEG, um transformador trifásico seco do tipo

abaixador, com potência nominal de 1000 kVA, conforme a norma NBR 5356-11. O

equipamento será instalado na subestação da unidade, em ambiente abrigado, adequado

às suas características construtivas, na Figura 9 temos o transformador selecionado.

O transformador possui enrolamento primário em triângulo (ligação Dyn1),

operando em 13,8 kV com comutação a vazio de -4x0,6 kV, e secundário em estrela, com

tensão de saída de 380 V. Seu grupo de ligação Dyn1 garante o isolamento adequado

entre os circuitos de alta e baixa tensão, atendendo aos requisitos de segurança e

confiabilidade.

Entre suas características técnicas, destaca-se a classe térmica F (155 °C), com

elevação de temperatura média nos enrolamentos de 100 °C e máxima no ponto mais

quente de 115 °C. O transformador apresenta rendimento elevado, atingindo até 98,56%

em plena carga com fator de potência unitário. Sua impedância base é de 6% e as perdas

totais são de 14,6 kW a 120 °C.

Trata-se de um equipamento com grau de proteção IP-23, condutores de

alumínio (tanto para alta quanto para baixa tensão) e refrigeração natural (AN). Conta

ainda com acessórios essenciais para monitoramento e operação segura, como sensor e

indicador de temperatura, sistema de comutação a vazio, olhais para movimentação,

rodas, base de apoio e conector de aterramento.

Figura 9 - Transformador 14543301 da WEG

Fonte: WEG-transformadores-a-seco

### 2.11. NÍVEIS DE CURTO-CIRCUITOS

O curto-circuito é uma falha elétrica caracterizada pela passagem de corrente

excessiva devido à ligação acidental entre condutores com diferença de potencial, como

fase-fase ou fase-terra. Essa condição pode gerar sérios danos ao sistema elétrico, como

superaquecimento de condutores, queima de equipamentos e até riscos à segurança dos

operadores. Por isso, a análise de curto-circuito é uma etapa fundamental no

desenvolvimento de qualquer projeto elétrico industrial, especialmente em instalações

com equipamentos sensíveis, como inversores de frequência.

Além de impactar diretamente na escolha dos cabos, o valor da corrente de curto-circuito influencia o dimensionamento e seletividade das proteções. É importante destacar

que, conforme a norma ABNT NBR IEC 60947-2, a capacidade de interrupção (Icc) dos

disjuntores deve ser superior à corrente de curto-circuito presumida no ponto de

instalação. Isso assegura que, em caso de falha, o dispositivo seja capaz de interromper a

corrente de forma segura e eficiente, sem comprometer a integridade da instalação.

Dessa forma, foram adotadas as seguintes expressões para o cálculo das correntes

de curto-circuito trifásica e fase-terra:

Ics =

Vbase
√3 × Zeq

Onde:

- Ics: Corrente de curto-circuito trifásica (A)
- Vbase: Tensão de linha no ponto de curto-circuito (V)
- Zeq: Impedância equivalente do sistema até o ponto de falta (Ω)

Icft =

Vfase
Z1 + Z2 + Z0 + 3Zf

Onde:

- Icft: Corrente de curto-circuito fase-terra (A)
- Vfase: Tensão fase-terra no ponto de curto (V)
- Z1, Z2, Z0: Impedâncias de sequência positiva, negativa e zero (Ω)
- Zf: Impedância de falta à terra (Ω) - considerada nula (falta franca)

### 2.11.1. DADOS BASE

Para o estudo de curto-circuito do projeto em questão, foram utilizados os

seguintes dados base:

- Tensão base MT: 13,8 kV
- Tensão base BT: 380 V
- Potência base: 100 MVA

Para impedâncias de suprimento, foram considerado os seguintes valores:

- Sequência positiva e negativa (Z₁ e Z₂):
- Rpu = 0,02
- Xpu = 0,5
- Sequência zero (Z0):
- Rpu = 0,04
- Xpu = 0,8

### 2.11.2. IMPEDÂNCIA DO TRANSFORMADOR

Para o cálculo de curto-circuito no secundário do transformador, foram utilizados

os dados do datasheet do equipamento, considerando a potência nominal, as perdas no

cobre e a impedância percentual informada pelo fabricante. Esses parâmetros serviram de

base para a determinação das impedâncias de sequência positiva, negativa e zero.

Segue abaixo os dados extraídos do datasheet:

- Potência nominal: 1000 kVA
- Tensões nominais: 13,8 kV / 0,38 kV
- Impedância percentual (Z%): 6,0%
- Perdas no cobre em carga: 11,7 Kw

### 2.11.3. IMPEDÃNCIA DOS CONDUTORES

Devido à ausência de informações específicas sobre as impedâncias dos

condutores no datasheet dos cabos utilizados, os valores adotados neste projeto foram

extraídos da Figura 10 que mostra uma tabela disponibilizada na atividade “Ma1 - Curto-

Circuito”, apresentada em aula. Essa tabela está em conformidade com as normas técnicas aplicáveis, garantindo que os parâmetros elétricos considerados reflitam adequadamente

as condições reais de operação do sistema.

Figura 10 - Tabela de valores médios de impedância dos condutores

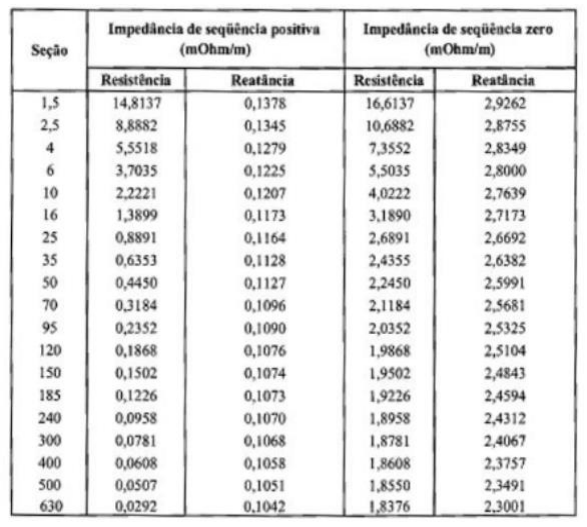
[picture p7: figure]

Fonte: Ma1: curto-circuito em instalação elétrica industrial

### 2.11.4. CORRENTE DE CURTO-CIRCUITO ASSIMÉTRICA

Para o cálculo da corrente de curto-circuito assimétrica (Ica), foram utilizadas as

seguintes fórmulas:
Ica = Fassimetria × Ics

Ica = Ics ×

√1 + 2e
−2τ
t

t = 4,16ms (1/4 ciclo)

τ =

X
2πfR

Essas equações permitem calcular com precisão a corrente de curto-circuito

assimétrica nas barras do sistema, considerando os efeitos da componente contínua (DC)

e o tempo de decaimento exponencial dessa componente ao longo do tempo.

Os fatores de assimetria utilizados neste projeto foram obtidos conforme a Figura

11 a partir da tabela apresentada na "Ma1 - Curto-Circuito" conforme imagem abaixo:

Figura 11 - Tabela de fatores de assimetria para t = 1/4 ciclo

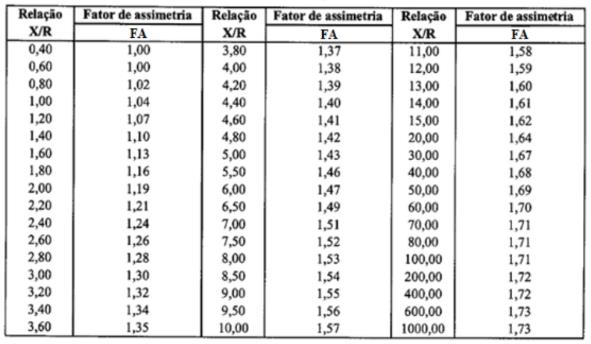
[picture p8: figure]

Fonte: Ma1: curto-circuito em instalação elétrica industrial

### 2.11.5. TABELA DE RESULTADOS

A seguir, na Tabela 21 são apresentados os resultados obtidos para as correntes

de curto-circuito nas barras do sistema, determinados por meio de cálculos analíticos:

Tabela 21 - Resumo dos resultados dos cálculos de curto-circuito

| Ics (A) | Icft (A) | Fator de
| | | assimetria | Ica (A)

Fornecimento de
Energia | 8360.7093 | 6965.9528 | 1.6626 | 13900.3611

Transformador -
lado BT | 23393.3324 | 23040.2170 | 1.4540 | 34014.3752
QGF | 22614.1373 | 22532.8650 | 1.4231 | 32181.1683
CCM1 | 18386.3684 | 8708.2246 | 1.2155 | 22348.3320
CCM2 | 11711.2390 | 4366.3327 | 1.0441 | 12227.8560
CCM3 | 15751.9670 | 5132.0955 | 1.2201 | 19218.2686

Fonte: Próprio autor

### 2.11.6. SIMULAÇÃO PSP-UFU

Para a comprovação dos cálculos de corrente de curto-circuito, foi realizada uma

simulação no software PSP-UFU. Abaixo, da Figura 12 até a Figura 24 apresentam-se

os prints da simulação juntamente com uma Tabela 22 contendo os resultados obtidos:

Figura 12 - Simulação via PSP-UFU

Fonte: Próprio autor

Figura 13 – Falta trifásica geração | Figura 14 – Falta monofásica geração
Figura 15 – Falta trifásica sec. do Trafo | Figura 16 – Falta monofásica sec. do Trafo

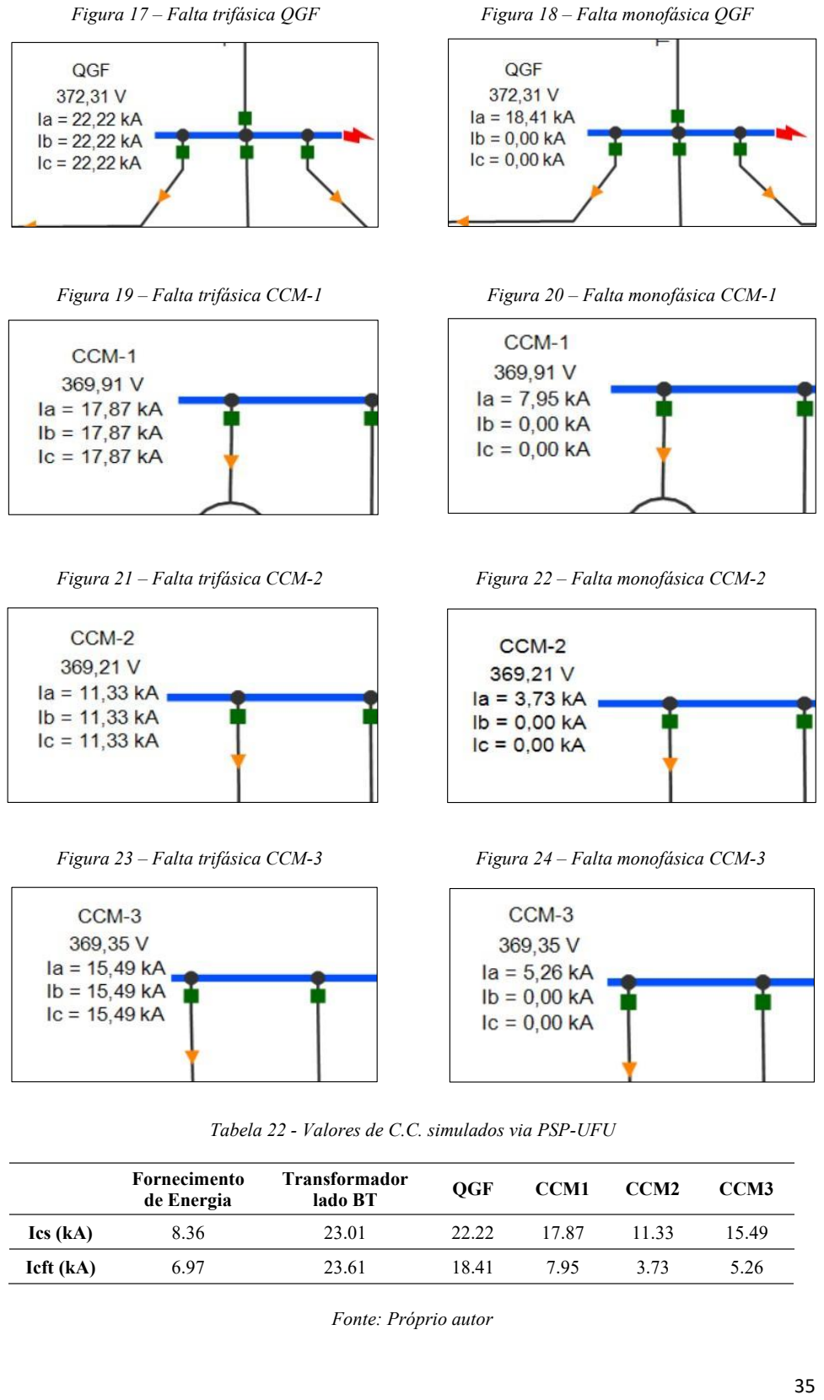
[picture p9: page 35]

Figura 17 – Falta trifásica QGF | Figura 18 – Falta monofásica QGF
Figura 19 – Falta trifásica CCM-1 | Figura 20 – Falta monofásica CCM-1
Figura 21 – Falta trifásica CCM-2 | Figura 22 – Falta monofásica CCM-2
Figura 23 – Falta trifásica CCM-3 | Figura 24 – Falta monofásica CCM-3

Tabela 22 - Valores de C.C. simulados via PSP-UFU

Fornecimento
de Energia

Transformador
| | lado BT | QGF | CCM1 | CCM2 | CCM3
Ics (kA) | 8.36 | 23.01 | 22.22 | 17.87 | 11.33 | 15.49
Icft (kA) | 6.97 | 23.61 | 18.41 | 7.95 | 3.73 | 5.26

Fonte: Próprio autor

### 2.12. DIAGRAMA UNIFILAR

Figura 25 – Diagrama Unifilar

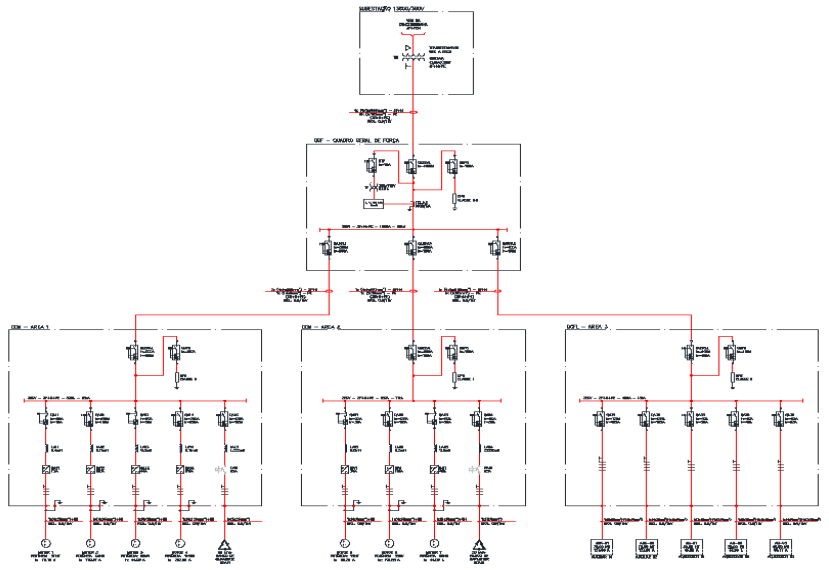
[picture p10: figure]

Fonte: Próprio autor

### 2.13. SUBESTAÇÃO ABRIGADA

O transformador adotado no projeto da subestação da empresa é do tipo seco,

trifásico, com potência nominal de 1000 kVA, tensão primária de 13,8 kV e secundária

de 380 V, fornecido pela WEG, sob o código 14543301. Suas características elétricas e

construtivas, bem como a concepção geral da instalação, foram analisadas sobre a tutela

da NBR 5356-11 (ABNT, 2015), que estabelece requisitos gerais para transformadores

de potência secos; da NBR 14039 (ABNT, 2021), que trata de instalações elétricas de

média tensão; e das normas CPFL GED-2855 (Volume 1) e GED-2856 (Volume 2), que

regulamentam o fornecimento de energia em tensão primária de 15 kV, 25 kV e 34,5 kV

nas áreas de concessão da CPFL Energia.

O equipamento opera com frequência de 60 Hz, possui grupo de ligação Dyn1 e

classe térmica F, com elevação de temperatura de até 115 °C no ponto mais quente. Seu

grau de proteção é IP-23, e apresenta impedância de 6%, rendimento superior a 98% em

plena carga e nível de ruído de 64 dB, atendendo aos requisitos de eficiência e segurança

operacional. Para garantir uma refrigeração eficaz do transformador, foi previsto um

sistema de ventilação forçada, composto por um ventilador instalado na parte inferior da

sala do transformador, para insuflação de ar frio, e um exaustor na parte superior,

responsável pela extração do ar quente acumulado.

A subestação foi projetada como cabine abrigada em alvenaria conforme a

Figura 26 e Figura 27 em conformidade com o item 3.13.1 da norma GED-2855,

proporcionando segurança, durabilidade, controle de acesso e ventilação adequada

aspectos fundamentais especialmente em ambientes industriais do setor alimentício. O

transformador a seco foi escolhido devido à sua compatibilidade com ambientes de alta

exigência sanitária, já que elimina riscos ambientais como vazamentos de óleo e reduz a

necessidade de manutenção.

A entrada de energia foi especificada como subterrânea, conforme a Figura 28,

e está em conformidade itens 6.3.6.2 e 3.10 (b) da GED-2855. Foram seguidas as

exigências da Tabela 4 da GED-2856 para uso de cabos isolados em XLPE ou EPR, classe

15 kV, lançados em dutos rígidos de PVC ou aço galvanizado com profundidade mínima

de 0,60 m. Também foram previstas caixas de passagem com dimensões mínimas de 800

x 800 x 1000 mm e condutor de aterramento dimensionado conforme seção dos cabos de

fase. A blindagem dos cabos nas muflas e terminações foi conectada ao sistema de

aterramento do consumidor, conforme indicado na norma.

A medição de energia foi posicionada em média tensão, em conformidade com

a Tabela 2 da GED-2856 e item 6.8 da GED-2855. Esta solução é obrigatória para

transformadores com potência superior a 308 kVA, como é o caso da presente instalação,

oferecendo maior precisão na medição, redução de perdas elétricas e melhor

compatibilidade com o sistema da concessionária.

A subestação foi dimensionada para atender uma planta industrial de alimentos

de médio a grande porte, localizada em zona industrial, com carga superior a 900 kVA.

A configuração adotada transformador a seco de 1000 kVA em cabine de alvenaria, com

entrada subterrânea e medição em média tensão é totalmente compatível com as

exigências técnicas, operacionais e normativas da CPFL, assegurando segurança,

confiabilidade e conformidade legal.

Figura 26 - Subestação cabine em alvenaria com medição em média tensão

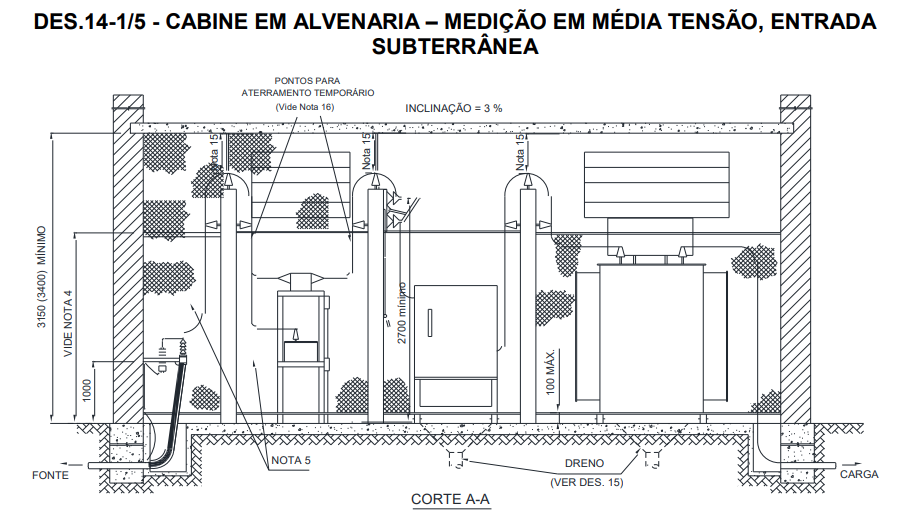
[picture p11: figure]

Fonte: GED-2855

Figura 27 - Subestação cabine em alvenaria com medição em média tensão - Corte A-A

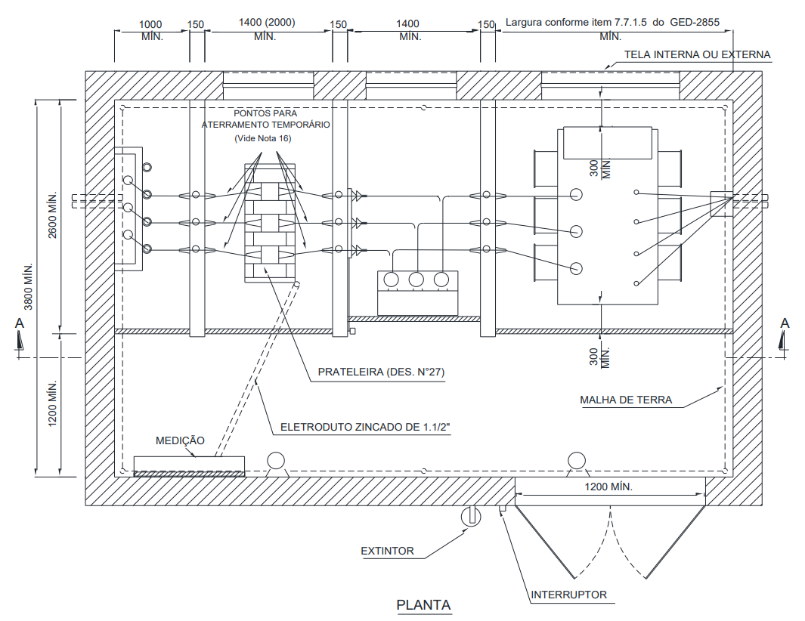
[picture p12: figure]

Fonte: GED-2855

Figura 28 - Ponto de conexão subterrâneo

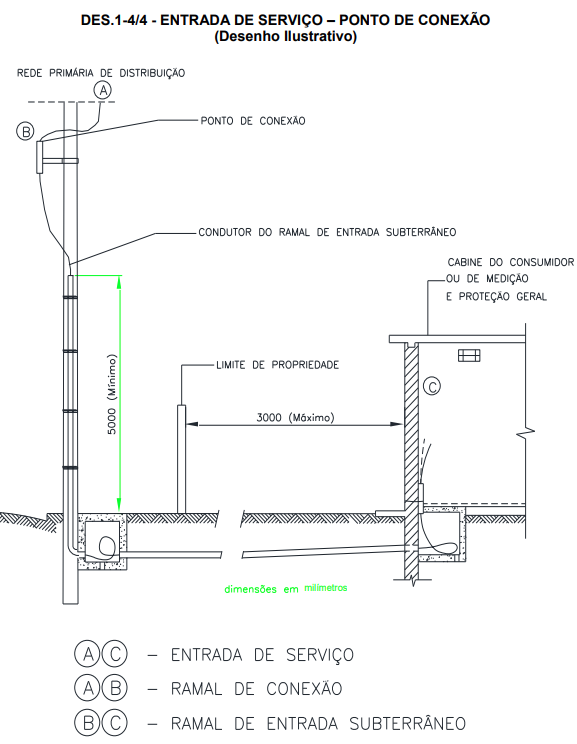
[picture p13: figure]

Fonte: GED-2855

### 2.14. LUMINOTÉCNICO

Neste projeto, foi realizada uma simulação detalhada no software Dialux,

incluindo o layout completo do ambiente, mobiliário, texturas, cores e taxas de reflexão

das superfícies. Essa abordagem oferece uma previsão mais precisa do comportamento

da luz no espaço real, permitindo identificar sombreamentos, variações de iluminância e

garantir conformidade com os requisitos normativos de conforto visual.

Foi considerado os seguintes dados para o dimensionamento:

- Local: escritório comum
- Dimensões: 20 x 15 metros
- Pé direito (PD): 3,5 metros
- Altura de Trabalho (H1): 0,8 metros
- Altura Lâmpada Teto (H2): 0,9 metros
- Teto: superfície branca
- Paredes: Brancas
- Pisos: escuros

Com base nos dados passados e a informação que a área se tratava de um

escritório comum, adotamos a pior situação possível que é 500 Lux de iluminância local,

segundo a Figura 29 a seguir:

Figura 29 – Nível de iluminância mantida

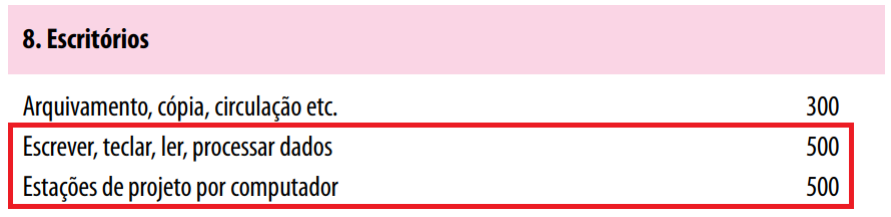
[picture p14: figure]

Fonte: (CREDER, Hélio. Instalações elétricas. 16. ed, TABELA 13.4)

Para determinar o índice de reflexão que é a capacidade de uma superfície refletir

a luz incidente, sendo expresso em forma percentual (%), esse índice é fundamental para

o projeto luminotécnico, pois influencia diretamente na quantidade de luz refletida pelas

superfícies internas de um ambiente como teto, paredes e piso consequentemente

influenciado na eficiência da iluminação.

Seguindo a parametrização estipulada pela norma, conforme a Figura 30, o índice

escolhido foi 751, onde foi adotado 7 para paredes brancas, 5 para teto de superfície clara

e 1 para pisos escuros

Figura 30 - Índice de reflexão típica

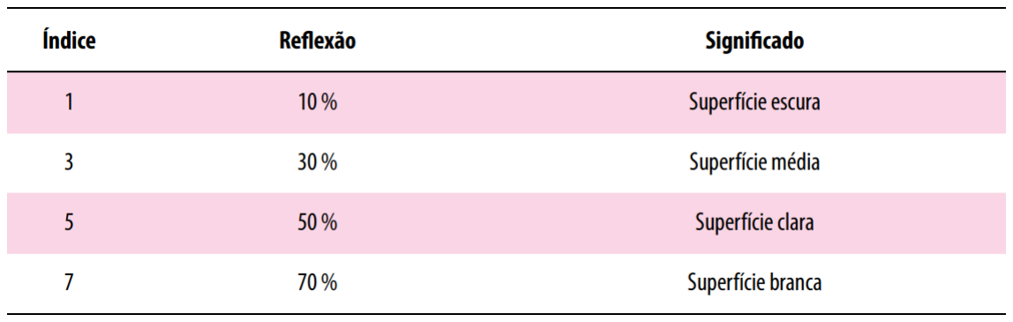
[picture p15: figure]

Fonte: (CREDER, Hélio. Instalações elétricas. 16. ed, TABELA 13.7)

O fator de depreciação é aplicado no cálculo luminotécnico para garantir que,

mesmo com a degradação ao longo do tempo, o nível de iluminância continue adequado para a atividade exercida no ambiente. É uma forma de planejar uma iluminação

duradoura e eficiente.

Adotamos o fator de 0,67 conforme demonstra a Figura 31, levando em

consideração que o ambiente se trata de um escritório.

Figura 31 - Fator de Depreciação

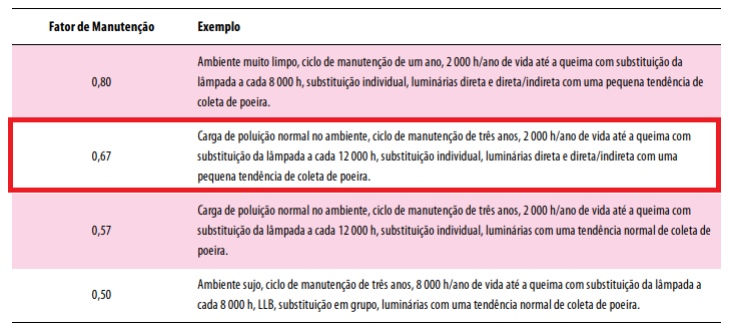
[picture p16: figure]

Fonte: (CREDER, Hélio. Instalações elétricas. 16. ed, TABELA 13.9)

Foi utilizado o modelo de luminária descrita na Figura 32, que apresentou

desempenho satisfatório nos cálculos luminotécnicos realizados pelo grupo, atendendo

aos níveis de iluminância estabelecidos. Trata-se de um equipamento de marca

reconhecida internacionalmente.

A luminária possui uma curva fotométrica favorável conforme a Figura 33, com

distribuição de luz adequada para ambientes industriais e comerciais, permitindo uma boa

uniformidade na iluminação. Embora seja originalmente projetada para instalação linear

ao teto, o modelo também permite instalação por meio de suportes do tipo pêndulo,

ampliando sua flexibilidade de aplicação conforme as características arquitetônicas do

ambiente.

Figura 32 - Lâmpada 3F Filippi 6937 | Figura 33 - Curva fotométrica da luminária 3F Filippi

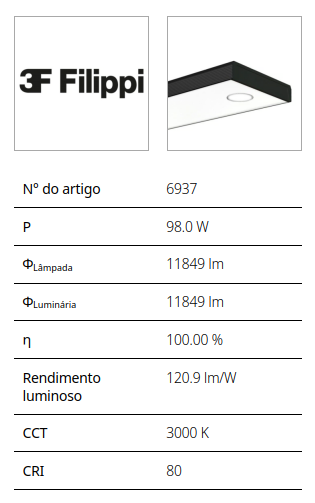
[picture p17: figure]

Fonte: DIAlux evo, 2025.

Fonte: DIAlux evo, 2025

O grupo propôs um layout arquitetônico de móveis conforme a Figura 34 para um

dimensionamento luminotécnico mais profissional e para melhor compreensão dos

aspectos de incidência e reflexão de luz no ambiente.

A partir do layout arquitetônico proposto, foi possível definir com precisão as

superfícies de trabalho e as áreas destinadas às tarefas visuais. Conforme ilustrado nas

Figura 35 e Figura 36, essas áreas foram estrategicamente posicionadas sobre as mesas,

que representam os principais pontos de execução das atividades laborais. Por se tratar de

um ambiente de escritório, as tarefas previstas envolvem, predominantemente, atividades

como leitura, escrita, digitação e processamento de dados. Dessa forma, a delimitação das

áreas de tarefa visual considerou a real utilização do espaço, garantindo que a iluminação

projetada atenda adequadamente às exigências visuais dessas funções específicas.

Embora o layout apresentado inclua uma área de sofás, armários e bancadas

integrada ao ambiente do escritório, essas regiões não foram consideradas no cálculo de

iluminância. Isso porque o grupo optou por focar exclusivamente nas reais áreas de

trabalho, ou seja, nas superfícies onde efetivamente ocorrem atividades visuais

específicas, como leitura, escrita e uso de computador. Dessa forma, as áreas adjacentes,

foram deliberadamente desconsideradas na definição das superfícies de cálculo, uma vez

que não representam zonas de execução direta de tarefas visuais conforme os critérios

adotados para o projeto.

Figura 34 - Layout arquitetônico proposto

Fonte: DIAlux evo, 2025.

Os planos de trabalho foram definidos considerando a disposição das mesas

presentes no escritório, de forma a representar com fidelidade as condições reais de uso

do ambiente. Para a análise luminotécnica, adotaram-se dois parâmetros principais: a

superfície de cálculo e a área de tarefa visual. Ambos foram aplicados em todos os tipos

de mesas existentes no projeto, garantindo que a avaliação da iluminância ocorresse tanto

em termos gerais quanto específicos, assegurando o conforto visual e a eficiência da

iluminação em cada estação de trabalho.

Figura 36 - Plano de trabalho e áreas de tarefa visual para mesas coletivas

Figura 35 - Plano de trabalho e áreas de tarefa visual para mesas individuais

Fonte: DIAlux evo, 2025.

Fonte: DIAlux evo, 2025.

Considerando que foi adotado um nível de iluminância de 500 lux sobre o plano

de trabalho, conforme recomendado para ambientes de escritório, a norma vigente

estabelece que as áreas adjacentes a esse plano, ou seja, os arredores imediatos devem

apresentar, no mínimo, 300 lux de iluminância conforme a Figura 37 a seguir.

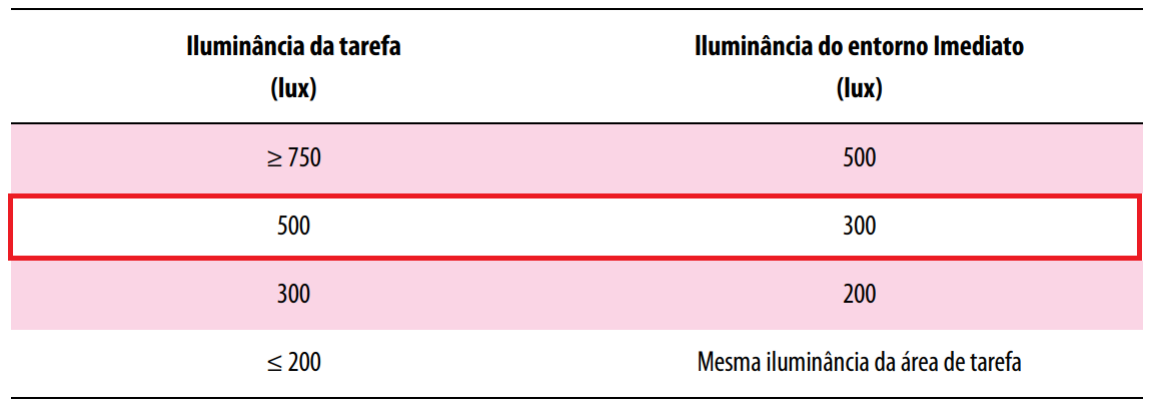
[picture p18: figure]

Os arredores da área de tarefa visual correspondem à zona que circunda

diretamente a superfície onde se realiza a atividade principal, sendo demarcada em 0,5m

no entorno, conforme demonstrado nas Figura 38 e Figura 39 a seguir.

Figura 37 - Iluminâncias por tarefas

Fonte: (CREDER, Hélio. Instalações elétricas. 16. ed, TABELA 13.5)

Figura 39 - Arredores de mesas de trabalho coletivas

Figura 38 - Arredores mesas de trabalho individuais

Fonte: DIAlux evo. 2025.

Fonte: DIAlux evo. 2025.

O software DIAlux nos permite realizar vários parâmetros de cálculos diferentes,

mas o grupo optou pelo área de tarefa visual sendo um cálculo mais completo, agora

iremos explicar suas diferenças e as características que veremos nos cálculos de saída do

DIAlux.

- Superfície de Cálculo: é uma área definida virtualmente no ambiente para

realizar medições de iluminância (em lux). Ela pode abranger mesas, bancadas,

pisos ou qualquer plano horizontal relevante ao uso do espaço.
- Área de Tarefa Visual: é a região específica dentro da superfície de cálculo onde

se realiza a atividade visual principal, como leitura, escrita, operação de máquinas

ou uso de computador. Essa área exige maior precisão nos parâmetros de

iluminação, como iluminância média, uniformidade e controle de ofuscamento,

pois influencia diretamente o conforto e o desempenho do usuário.

A seguir, serão explicados o tipo de potência luminosa utilizado na

parametrização dos cálculos luminotécnicos, com foco na forma como o fluxo luminoso

foi distribuído para atender aos critérios normativos de iluminância e conforto visual

- Potência luminosa perpendicular: refere-se à componente do fluxo luminoso

emitido pelas luminárias que incide diretamente de cima para baixo sobre a

superfície de trabalho, formando um ângulo de 90° com o plano da tarefa visual.

A seguir será apresentada a explicação de cada uma das colunas exibidas na

Figura 40, extraída do relatório gerado pelo software DIALux, com o objetivo de

esclarecer o significado técnico de cada parâmetro apresentado.

Figura 40 - Cálculos de saída do Dialux

- Enominal (Iluminância Nominal): é o valor de iluminância médio calculado para a

superfície ou área de tarefa visual, de acordo com a norma adotada ABNT NBR

ISO/CIE 8995-1. Representa o ponto de referência que o projeto deve atingir ou

superar.

- Emin (Iluminância Mínima): é o menor valor de iluminância registrado na

superfície de cálculo durante a simulação

- Emax (Iluminância Máxima): é o maior valor de iluminância registrado na

superfície de cálculo.

- U0 (Uniformidade): é um parâmetro que indica a quão homogênea é a distribuição

da luz sobre uma determinada superfície. Ela é calculada como a razão entre a

iluminância mínima e a iluminância média no plano de trabalho:

U =

Emin
Emed

Lembrando que a norma ABNT NBR ISO/CIE 8995-1 estabelece que a

uniformidade para áreas de tarefa visual seja U0 ≥ 0.7 e para entornos imediatos

(arredores) ele estabelece que U0 ≥ 0.6, conforme a Figura 41 ilustra.

Fonte: DIAlux evo, 2025.

Figura 41 - Entorno imediato

Fonte: ABNT NBR ISO/CIE 8995-1:2013, FIGURA 1A.

Seguindo a parametrização de distâncias estipulada por norma, onde a distância

entre a luminária e a parede deve ser metade da distância entre as luminárias, conforme a

Figura 42 a seguir.

A Figura 43 demonstra a distribuição proposta pelo grupo, sendo um sistema de

6 colunas e 6 linhas, totalizando 36 luminárias

Figura 42 - Distribuição típica de luminárias

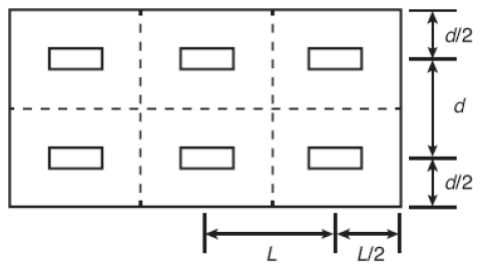
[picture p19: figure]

Figura 43 - Distribuição proposta pelo grupo

Fonte: (CREDER, Hélio. Instalações elétricas. 16. ed, FIGURA 13.22)

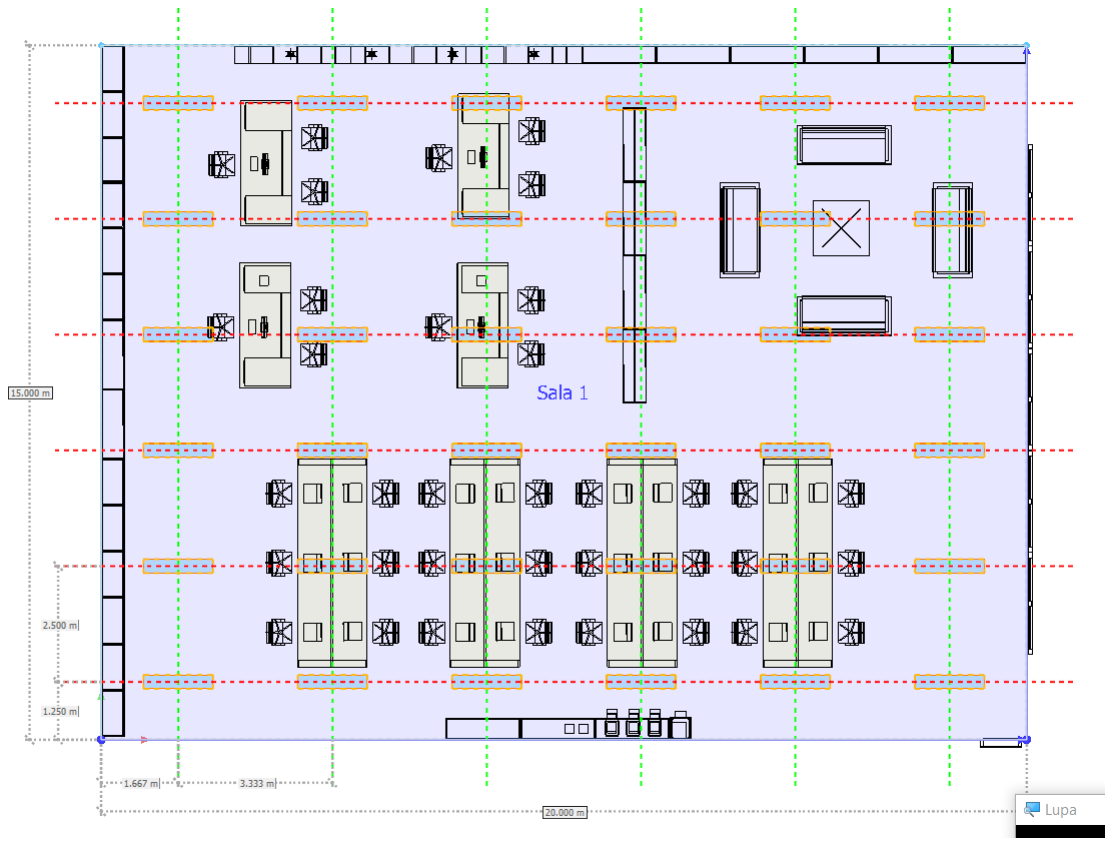
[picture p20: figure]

Fonte: DIAlux evo. 2025.

Nas Figura 44 e Figura 45 a seguir mostraremos os resultados obtidos através

da simulação no DIAlux.

Figura 44 - Resultados simulação - Áreas de Tarefa Visual – Parte 1

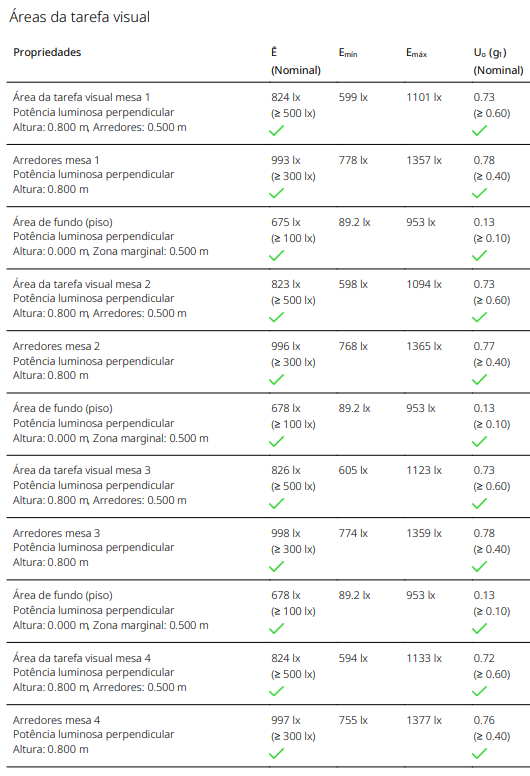
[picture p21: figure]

Fonte: DIAlux evo. 2025.

Figura 45 - Resultados simulação - Áreas de Tarefa Visual – Parte 2

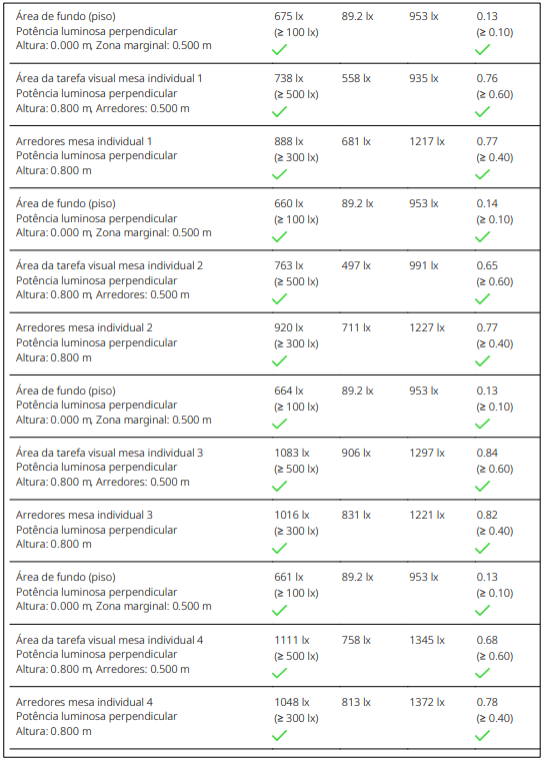
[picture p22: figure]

Fonte: DIAlux evo. 2025.

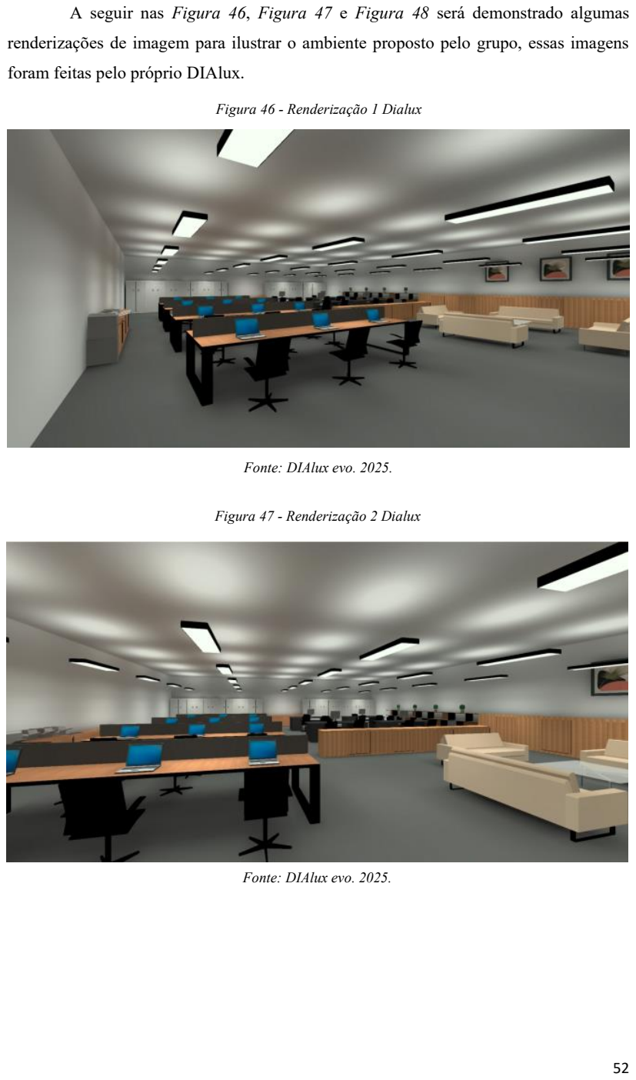
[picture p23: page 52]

A seguir nas Figura 46, Figura 47 e Figura 48 será demonstrado algumas

renderizações de imagem para ilustrar o ambiente proposto pelo grupo, essas imagens

foram feitas pelo próprio DIAlux.

Figura 46 - Renderização 1 Dialux

Fonte: DIAlux evo. 2025.

Figura 47 - Renderização 2 Dialux

Fonte: DIAlux evo. 2025.

Figura 48 - Renderização 3 Dialux

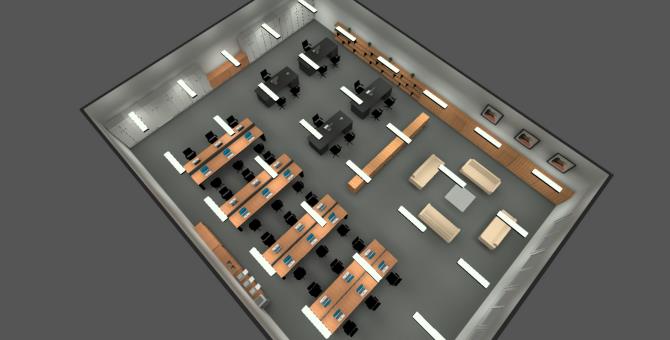
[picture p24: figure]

Fonte: DIAlux evo. 2025.

### 3. RESULTADOS E DISCUSSÕES

A execução deste projeto resultou em uma proposta técnica completa,

contemplando todas as etapas necessárias para garantir o funcionamento seguro e

eficiente da instalação industrial. Os principais resultados obtidos podem ser destacados

nos tópicos a seguir.

### 3.1. SELEÇÃO DE COMPONENTES

O grupo realizou a seleção de todos os componentes utilizados no projeto de

forma criteriosa e fundamentada, garantindo que os motores, disjuntores, contatores,

reatores e transformadores fossem especificados de acordo com as recomendações

técnicas presentes nos catálogos oficiais de cada fabricante. Para assegurar maior

padronização, qualidade e confiabilidade do sistema, optou-se, na maioria dos casos, pela

marca WEG, reconhecida por sua robustez e ampla aceitação no mercado nacional. Essa

decisão visa facilitar a manutenção, reposição de peças e garantir o desempenho adequado

dos equipamentos, atendendo às exigências de segurança e eficiência estabelecidas para

o projeto.

### 3.2. DIMENSIONAMENTO DE CARGA TOTAL

Com base no levantamento dos equipamentos e processos industriais, a carga

instalada foi devidamente quantificada, considerando os fatores de demanda e

simultaneidade específicos para o perfil da indústria alimentícia. O cálculo de demanda

permitiu dimensionar corretamente o ponto de alimentação principal e a seção dos

condutores, resultando em uma instalação capaz de atender às exigências de consumo

sem sobrecarregar o sistema.

### 3.3. SELEÇÃO DE DISJUNTORES E PROTEÇÕES

Foram especificados disjuntores termomagnéticos e dispositivos de proteção

adequados aos níveis de corrente nominal e de curto-circuito estimados. A seleção foi

feita conforme as curvas características de atuação, garantindo proteção eficaz contra

sobrecargas e curtos-circuitos, com tempo de resposta adequado à segurança dos

equipamentos e dos operadores.

### 3.4. INVERSORES DE FREQUÊNCIA E PARTIDA DE MOTORES

Para todos os motores, foram especificados o método de partida via inversores de

frequência, visando a aplicação do tipo de indústria escolhido, controle de velocidade e

redução de picos de corrente. Essa escolha contribui para o aumento da vida útil dos

motores e para o controle mais eficiente dos processos produtivos.

### 3.5. CORREÇÃO DE FATOR DE POTÊNCIA

A análise inicial indicou fator de potência abaixo do mínimo exigido pelas

concessionárias (0,92). Com a instalação de bancos de capacitores devidamente

dimensionados, foi possível corrigir o fator de potência das áreas 1 e 2 para valores

próximos a 0,95, reduzindo perdas reativas e evitando penalidades tarifárias.

### 3.6. TRANSFORMADOR DE POTÊNCIA

A escolha do transformador seco trifásico de 1000 kVA, IP-23, 13,8/0,38 kV foi

fundamentada em sua eficiência, segurança operacional e compatibilidade com o

ambiente industrial alimentício. O modelo selecionado oferece alto rendimento (98,4%

em plena carga), baixo nível de ruído (64 dB) e não utiliza óleo isolante, o que elimina

riscos de contaminação.

Além disso, o grau de proteção IP-23 e a instalação em cabine abrigada garantem

robustez e confiabilidade ao sistema. A refrigeração natural (AN) e os acessórios

integrados, como sensor de temperatura e comutador de tensão, tornam este equipamento

adequado tanto do ponto de vista técnico quanto normativo, em conformidade com as

exigências da CPFL e da NBR 5356-11.

### 3.7. CALCULOS DE CURTO-CIRCUITO

Com base nas características elétricas dos componentes da instalação, foram

realizados os cálculos das correntes de curto-circuito trifásico e fase-terra em todos os

barramentos do sistema. Os resultados obtidos permitiram verificar a capacidade de

interrupção dos dispositivos de proteção especificados, assegurando que os disjuntores e

barramentos selecionados suportam as correntes de falta previstas sem risco de danos

térmicos ou dinâmicos. Esse estudo foi essencial para garantir a segurança das instalações

e a integridade dos equipamentos em condições de falha, além de ser uma exigência das

normas técnicas.

### 3.8. SUBESTAÇÃO ABRIGADA E CONEXÃO SUBTERRÂNEA

A análise técnica da carga instalada, do perfil da empresa e das normas da

concessionária CPFL confirmou a viabilidade e a adequação da implantação de uma

subestação do tipo cabine abrigada em alvenaria, a escolha da cabine em alvenaria

proporciona maior proteção física aos equipamentos, segurança operacional e

atendimento às exigências sanitárias da indústria alimentícia.

A conexão subterrânea foi selecionada com base nas diretrizes da CPFL (GED-

2855 e GED-2856), que recomendam esse tipo de ramal para unidades consumidoras de

grande porte em áreas industriais, garantindo maior segurança, confiabilidade no

fornecimento e compatibilidade com a infraestrutura local.

### 3.9. PROJETO LUMINOTÉCNICO

O projeto luminotécnico foi desenvolvido com base na ABNT NBR ISO/CIE

8995-1, que estabelece os critérios para níveis adequados de iluminância em ambientes

de trabalho. As soluções adotadas asseguram conforto visual, segurança operacional e

eficiência energética nas áreas internas e externas da planta industrial. A distribuição

adequada dos pontos de luz, aliada à escolha de luminárias eficientes, garante a

conformidade com os parâmetros normativos e contribui para a produtividade e bem-estar

no ambiente de trabalho.

### 3.10. EFICIÊNCIA ENERGÉTICA E CONFORMIDADE COM

NORMAS

Todas as soluções propostas neste projeto foram desenvolvidas com base em um

conjunto robusto de normas técnicas, destacando-se a ABNT NBR 5410, NBR 14039,

NBR 5356-11, ABNT NBR ISO/CIE 8995-1, bem como as normas específicas da

concessionária, representada pelas diretrizes do Grupo CPFL, como a GED-2855 e GED-

2856. A aplicação rigorosa dessas normas garantiu que cada etapa do projeto atendesse

aos requisitos de segurança, desempenho e legalidade vigentes.

Os materiais e dispositivos utilizados apresentam certificações técnicas e alta

eficiência energética, evidenciando o compromisso do grupo com soluções sustentáveis

e de qualidade. A análise dos resultados comprova que o sistema projetado é capaz de

suprir, de forma confiável, as demandas operacionais da planta industrial, ao mesmo tempo em que mitiga riscos como sobrecargas, quedas de tensão e consumo excessivo de

energia reativa.

A postura técnica adotada demonstra o papel estratégico do engenheiro

eletricista na antecipação de falhas e na elaboração de soluções que equilibram eficiência,

custo e segurança. O investimento em tecnologias como inversores de frequência,

correção do fator de potência e um sistema luminotécnico eficiente proporciona ganhos

operacionais significativos, reduzindo o consumo de energia, prolongando a vida útil dos

equipamentos e gerando retorno econômico a médio prazo.

### 4. CONCLUSÃO

Com o desenvolvimento deste projeto de sistemas elétricos para uma indústria

alimentícia de médio porte, localizada na cidade de Gramado, o grupo teve a oportunidade

de aplicar de forma prática os conhecimentos adquiridos ao longo do curso de Engenharia

Elétrica. Foi uma experiência que nos permitiu entender conteúdos essenciais, com foco

na eficiência energética, segurança operacional e conformidade com as normas técnicas

vigentes.

Ao realizar o dimensionamento cuidadoso de condutores, disjuntores,

dispositivos de proteção, inversores de frequência e propor a correção do fator de

potência, conseguimos elaborar uma solução robusta e tecnicamente adequada, em

conformidade com todas as normas aplicáveis.

O trabalho também evidenciou a importância do planejamento detalhado das

instalações, não apenas para garantir o funcionamento contínuo dos sistemas, mas para

minimizar perdas, evitar falhas e otimizar custos operacionais com energia. Isso reforça

a responsabilidade técnica e estratégica do engenheiro eletricista em ambientes

industriais.

O grupo reconhece o valor deste tipo de trabalho acadêmico em nossas

trajetórias. Entendemos que experiências como essa são fundamentais para nossa

formação como futuros engenheiros eletricistas, pois estimulam a análise crítica, a

tomada de decisões técnicas, o trabalho em equipe e o compromisso com a excelência

profissional e acadêmica. Com base nos resultados obtidos concluímos que os objetivos

propostos foram plenamente atingidos, resultando em um sistema elétrico eficiente,

seguro e adequado às necessidades da planta industrial em questão.

### 5. REFERÊNCIAS BIBLIOGRÁFICAS

ASSOCIAÇÃO BRASILEIRA DE NORMAS TÉCNICAS. NBR 6023:2018 –

Informação e documentação – Referências – Elaboração. Rio de Janeiro: ABNT, 2018.

ASSOCIAÇÃO BRASILEIRA DE NORMAS TÉCNICAS. NBR 6027:2012 –

Sumário – Apresentação. Rio de Janeiro: ABNT, 2012.

ASSOCIAÇÃO BRASILEIRA DE NORMAS TÉCNICAS. NBR 14724:2023 –

Informação e documentação – Trabalhos acadêmicos – Apresentação. Rio de Janeiro:

ABNT, 2023.

ABNT – Associação Brasileira De Normas Técnicas. NBR 5410: Instalações Elétricas

de Baixa Tensão. Rio de Janeiro: ABNT, 2004. 209 p.

ANEEL – Agência Nacional de Energia Elétrica. Resolução Normativa ANEEL nº

1000. Brasília, ANEEL, 2021. Disponível em: https://www.in.gov.br/en/web/dou/-

/resolucao-normativa-aneel-n-1.000-de-7-de-dezembro-de-2021-368359651. Acesso

em: maio 2025.

ASSOCIAÇÃO BRASILEIRA DE NORMAS TÉCNICAS. NBR 14039:2021 –

Instalações elétricas de média tensão de 1,0 kV a 36,2 kV. Rio de Janeiro, 2021.

ASSOCIAÇÃO BRASILEIRA DE NORMAS TÉCNICAS. NBR 5356-11 –

Transformadores de potência secos – Parte 11: Requisitos gerais. Rio de Janeiro, 2015.

CPFL ENERGIA. GED-2855 – Fornecimento em Tensão Primária – 15, 25 e 34,5

kV – Volume 1. Campinas: CPFL Energia, 2020.

CPFL ENERGIA. GED-2856 – Requisitos para Instalações de Subestação do

Consumidor em Média Tensão – Volume 2. Campinas: CPFL Energia, 2020.

CREDER, Hélio. Instalações elétricas. 15. ed. Rio de Janeiro, RJ: Livros Técnicos e

Científicos, 2015

INSTITUTE OF ELECTRICAL AND ELECTRONICS ENGINEERS. IEEE Std

519-2014: IEEE recommended practice and requirements for harmonic control in electric

power systems. New York: IEEE, 2014

INTERNATIONAL ELECTROTECHNICAL COMMISSION. IEC 60947-4-1: low-

voltage switchgear and controlgear – part 4-1: contactors and motor-starters –

electromechanical contactors and motor-starters. Geneva: IEC, 2020.

MINISTÉRIO DO TRABALHO E EMPREGO. NR 10: Segurança em Instalações e

Serviços em Eletricidade. Brasília: Ministério do Trabalho e Emprego, 2019.

MINISTÉRIO DO TRABALHO E EMPREGO. NR 12: Segurança no Trabalho em

Máquinas e Equipamentos. Brasília: Ministério do Trabalho e Emprego, 2019.

WEG. Manual do Usuário – Inversor de Frequência CFW500. Versão 4.0x. Jaraguá do

Sul: WEG Automação, 2022. Disponível em: https://www.weg.net. Acesso em: maio

2025. Página 119.

WEG. Manual do Usuário – Inversor de Frequência CFW500. Versão 4.0x. Jaraguá do

Sul: WEG Automação, 2022. Disponível em: https://www.weg.net. Acesso em: maio

2025. Anexo B – Tabela de Especificações de Fusíveis e Disjuntores, página 157.

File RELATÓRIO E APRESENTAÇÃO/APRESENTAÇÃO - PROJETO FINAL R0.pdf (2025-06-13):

# PROJETO DE


# INSTALAÇÕES ELÉTRICAS

PROF. DR. DANIEL AUGUSTO PAGI FERREIRA

GRUPO:

BRUNO H. DE OLIVEIRA - R.A:109784

EMERSON F. ALBERTINI - R.A:109667

ISAAC Z. M. ESPELHO - R.A: 110490

MATEUS G. JUSTINO - R.A: 109219

# ÍNDICE

1. INTRODUÇÃO
2. TABELA DE CARGAS
3. DISJUNTORES E CONDUTORES PARA CADA CARGA
4. DISJUNTORES E CONDUTORES PARA CADA ÁREA
5. DISJUNTOR GERAL
6. MÉTODO DE PARTIDA
7. CORREÇÃO DE FATOR DE POTÊNCIA
8. TRANSFORMADOR DE POTÊNCIA
9. NÍVEIS DE CURTO CIRCUITO
10. DIAGRAMA UNIFILAR
11. SUBESTAÇÃO ABRIGADA
12. LUMINOTÉCNICO
13. CONCLUSÃO
14. AGRADECIMENTOS

2

# INTRODUÇÃO

Este projeto tem como finalidade apresentar a proposta de implementação de um sistema elétrico completo para uma indústria localizada na cidade de Gramado, no estado do Rio Grande do Sul, sob concessão da empresa RGE – Rio Grande Energia. A RGE faz parte do Grupo CPFL Energia.

3


NOTA: Todas as imagens, tabelas e gráficos não referenciadas suas devidas fontes são de autoria e confecção do grupo.

NOTA: Como a concessionária RGE pertence ao grupo CPFL Energia, adota as mesmas normas técnicas da CPFL. Portanto, todas as normas aplicáveis a este trabalho são as da CPFL Energia.

Fonte: site https://www.rge-rs.com.br/ | Fonte: site https://gramado.atende.net/

# INTRODUÇÃO

Minima (°C); Máxima (°C)

Como este projeto situa-se na cidade de Gramado/RS foi adotado um fator de correção de temperatura conforme a
temperatura média registrada no ano de 2024.

Temperatura em Gramado/RS - 2024

Fonte: ABNT. NBR 5410:2004. Rio de Janeiro: ABNT, 2004.
Tabela 40.

NOTA: Dados retirados do site climatempo
https://www.climatempo.com.br/climatologia/7
80/gramado-rs

Temperatura | Mínima (°C) | Máxima (°C)
Média | 13,10 | 23,25
Média Geral | 18,15

# TABELA DE CARGAS

5

Carga | Potência Mecânica (CV) | Potência Fator de | Ângulo | Rendimento | Potência Ativa (kw) | Potência Reativa (kVAr) | Potência Aparente (kVA)
Motor 1 | 50,00 | 0,84 | 32,86 | 0,954 | 37,00 | 20,08 | 46,17
Motor 2 | 125,00 | 0,86 | 30,68 | 0,954 | 92,00 | 45,93 | 112,13
Motor 3 | 30,00 | 0,81 | 35,90 | 0,936 | 22,00 | 12,90 | 29,02
Motor 4 | 150,00 | 0,86 | 30,68 | 0,958 | 110,00 | 56,13 | 133,51
Motor 5 | 20,00 | 0,81 | 35,90 | 0,930 | 15,00 | 8,80 | 19,91
Motor 6 | 75,00 | 0,86 | 30,68 | 0,954 | 55,00 | 28,07 | 67,04
Motor 7 | 30,00 | 0,81 | 35,90 | 0,936 | 22,00 | 12,90 | 29,02
Auxiliar | - | 0,92 | 23,07 | 1,000 | 75,00 | 29,39 | 81,52
Auxiliar | - | 0,92 | 23,07 | 1,000 | 75,00 | 29,39 | 81,52
Aquecimento 1 | - | 1,00 | 0,00 | 1,000 | 30,00 | 0,00 | 30,00
Aquecimento 2 | - | 1,00 | 0,00 | 1,000 | 25,00 | 0,00 | 25,00
Aquecimento 3 | - | 1,00 | 0,00 | 1,000 | 40,00 | 0,00 | 40,00

Nessa etapa, foram identificadas as cargas previstas, suas potências nominais, tensões de alimentação, correntes estimadas, fator de potência e respectivas localizações dentro da instalação.

# DISJUNTORES E CONDUTORES PARA CADA CARGA

6

Para o dimensionamento dos condutores e dispositivos de proteção, adotamos como referência a norma NBR 5410, que estabelece os critérios mínimos para instalações elétricas em baixa tensão.

Para a definição das bitolas dos cabos utilizados na instalação elétrica, foram adotados três critérios distintos de dimensionamento, conforme as boas práticas da engenharia e as normas técnicas aplicáveis:

- Ampacidade;
- Queda de Tensão;
- Seção Mínima;

NOTA: Todos os cálculos foram feitos considerando método de instalação B1 e cabos EPR/XLPE -ABNT NBR 5410:2004;

# DISJUNTORES E CONDUTORES PARA CADA CARGA

7

## AMPACIDADE

Verificou-se a corrente nominal dos circuitos com base na potência instalada, utilizando a fórmula: Ip=Pn√3⋅V⋅cosφ⋅n

Onde:

- Ip = Corrente nominal do circuito (A)
- Pn = Potência ativa nominal da carga (W)
- V = Tensão entre fases (V)
- cosφ = Fator de potência (adimensional), representa a relação entre potência ativa e aparente
- n = Rendimento da carga ou equipamento (adimensional, geralmente entre 0,8 e

# AMPACIDADE - RESULTADOS OBTIDOS

8

Carga | FCT 20° | FCA 4 circuitos (pior caso) | I Projeto (in 380) (A) < | IZC- Capac. I cabo corrigida (a) > | IZ - Cap. I cabo (a) | Bitola - mm²
Motor 1 | 1,08 | 0,65 | 70,15 | 82,13 | 117,00 | 25,00
Motor 2 | 1,08 | 0,65 | 170,37 | 188,84 | 269,00 | 95,00
Motor 3 | 1,08 | 0,65 | 44,09 | 61,78 | 88,00 | 16,00
Motor 4 | 1,08 | 0,65 | 202,85 | 219,02 | 312,00 | 120,00
Motor 5 | 1,08 | 0,70 | 30,25 | 36,29 | 48,00 | 6,00
Motor 6 | 1,08 | 0,70 | 101,85 | 108,86 | 144,00 | 35,00
Motor 7 | 1,08 | 0,70 | 44,09 | 49,90 | 66,00 | 10,00
Auxiliar | 1,08 | 0,80 | 123,86 | 151,20 | 175,00 | 50,00
Auxiliar | 1,08 | 0,80 | 123,86 | 151,20 | 175,00 | 50,00
Aquecimento 1 | 1,08 | 0,70 | 45,58 | 49,90 | 66,00 | 10,00
Aquecimento 2 | 1,08 | 0,70 | 37,98 | 49,90 | 66,00 | 10,00
Aquecimento 3 | 1,08 | 0,70 | 60,77 | 66,53 | 88,00 | 16,00

# DISJUNTORES E CONDUTORES PARA CADA CARGA

9

## QUEDA DE TENSÃO

Avaliou-se a queda de tensão admissível nos circuitos, conforme a fórmula:

Onde:

- S = Seção do condutor (mm²)
- p = Resistividade elétrica do material do condutor (Ω·mm²/m) - Cobre
- e% = Queda de tensão admissível (em porcentagem, ex: 4% → 0,04)
- Vff² = Tensão entre fases (V) elevado ao quadrado
- ∑(P ⋅l)= Soma dos produtos entre potências de carga (W) e seus respectivos comprimentos (m)
- P = Potência da carga (W)
- l = Comprimento do trecho do condutor até a carga (m)

# QUEDA DE TENSÃO - RESULTADOS OBTIDOS

1
0
Carga | Raiz 3 | p | e(%) | Tensão Fase-Fase 380v | comprimento circ. (L) | Fórmula seção queda tensão | Bitola - mm²
Motor 1 | 1,73 | 0,02 | 0,02 | 144400,00 | 5,00 | 2,28 | 2,50
Motor 2 | 1,73 | 0,02 | 0,02 | 144400,00 | 5,00 | 5,53 | 6,00
Motor 3 | 1,73 | 0,02 | 0,02 | 144400,00 | 5,00 | 1,40 | 1,50
Motor 4 | 1,73 | 0,02 | 0,02 | 144400,00 | 5,00 | 6,61 | 10,00
Motor 5 | 1,73 | 0,02 | 0,02 | 144400,00 | 5,00 | 0,96 | 1,00
Motor 6 | 1,73 | 0,02 | 0,02 | 144400,00 | 5,00 | 3,31 | 4,00
Motor 7 | 1,73 | 0,02 | 0,02 | 144400,00 | 5,00 | 1,40 | 1,50
Auxiliar | 1,73 | 0,02 | 0,02 | 144400,00 | 5,00 | 4,21 | 6,00
Auxiliar | 1,73 | 0,02 | 0,02 | 144400,00 | 5,00 | 4,21 | 6,00
Aquecimento 1 | 1,73 | 0,02 | 0,02 | 144400,00 | 5,00 | 1,55 | 2,50
Aquecimento 2 | 1,73 | 0,02 | 0,02 | 144400,00 | 5,00 | 1,29 | 2,50
Aquecimento 3 | 1,73 | 0,02 | 0,02 | 144400,00 | 5,00 | 2,07 | 4,00

# DISJUNTORES E CONDUTORES PARA CADA CARGA

1
1

## SEÇÃO MÍNIMA

Considerou-se também a seção mínima exigida pelas normas para fins de proteção mecânica e segurança da

instalação, baseando-se nas correntes nominais dos motores, tomando como referência a norma ABNT NBR

5410:2004 - Tabela 37; para escolha dos condutores.

# SEÇÃO MÍNIMA- RESULTADOS OBTIDOS

1
2
Carga | I Projeto (A) (In 380) | Bitola - mm²
Motor 1 | 70,15 | 16,00
Motor 2 | 170,37 | 50,00
Motor 3 | 44,09 | 6,00
Motor 4 | 202,85 | 70,00
Motor 5 | 30,25 | 4,00
Motor 6 | 101,85 | 25,00
Motor 7 | 44,09 | 6,00
Auxiliar | 123,86 | 35,00
Auxiliar | 123,86 | 35,00
Aquecimento 1 | 45,58 | 6,00
Aquecimento 2 | 37,98 | 6,00
Aquecimento 3 | 60,77 | 10,00

# DISJUNTORES E CONDUTORES PARA CADA CARGA

1
3

## RESULTADOS OBTIDOS

Área | Carga | Cabo mm² -Ampacidade | Cabo mm² - queda de tensão | Cabo mm² - seção mínima | Cabo mm² -escolhido | Corrente do Disjuntor BT (A) | Regulagem do Disjuntor BT (A | Modelo Disjuntores WEG (Reguláveis)
1 | Motor 1 | 25 | 2,5 | 16 | 25 | 80 | 80 | MPW80-3-U080
| Motor 2 | 95 | 6 | 50 | 95 | 200 | 180 | DWB250N200-3DF
| Motor 3 | 16 | 1,5 | 6 | 16 | 50 | 50 | MPW80-3-U050
| Motor 4 | 120 | 10 | 70 | 120 | 250 | 210 | DWB250N-250-3DF
2 | Motor 5 | 6 | 1 | 4 | 6 | 32 | 32 | MPW40-3-U032
| Motor 6 | 35 | 4 | 25 | 35 | 125 | 105 | DWB160N-125-3DF
| Motor 7 | 10 | 1,5 | 6 | 10 | 50 | 47 | MPW80-3-U050
3 | Iluminação 1 | 50 | 6 | 35 | 50 | 125 | 125 | DWB160N125-3DF
| Iluminação 2 | 50 | 6 | 35 | 50 | 125 | 125 | DWB160N125-3DF
| Aquec. 1 | 10 | 2,5 | 6 | 10 | 50 | 48 | DWB160N50-3DF
| Aquec. 2 | 10 | 2,5 | 6 | 10 | 40 | 40 | DWB160N40-3DF
| Aquec. 3 | 16 | 4 | 10 | 16 | 63 | 63 | DWB160N63-3DF

# DISJUNTORES E CONDUTORES PARA CADA ÁREA

1
4

Além do dimensionamento individual por carga, também foi necessário definir os condutores e disjuntores de baixa tensão para cada área do sistema, considerando o agrupamento de cargas e a distribuição dos circuitos dentro da planta.

Assim como no item anterior, seguimos as diretrizes da norma NBR 5410 para assegurar conformidade técnica e segurança.

Para a definição das bitolas dos cabos utilizados na instalação elétrica, foram adotados três critérios distintos de dimensionamento, conforme as boas práticas da engenharia e as normas técnicas aplicáveis:

- Ampacidade;
- Queda de Tensão;
- Seção Mínima;

NOTA: Todos os cálculos foram feitos considerando método de instalação B1 e cabos EPR/XLPE -ABNT NBR 5410:2004;

# DISJUNTORES E CONDUTORES PARA CADA ÁREA

1
5

## AMPACIDADE

Verificou-se a corrente nominal dos circuitos com base na potência instalada, utilizando a fórmula: Ip=Pn√3⋅V⋅cosφ⋅n

Onde:

- | Ip | = Corrente nominal do circuito (A)
- Pn = Potência ativa nominal da carga (W)
- V = Tensão entre fases (V)
- cosφ = Fator de potência (adimensional), representa a relação entre potência ativa e aparente
- n = Rendimento da carga ou equipamento (adimensional, geralmente entre 0,8 e

NOTA: Foi realizada a soma das correntes de cada carga individual, a fim de se calcular a carga total de cada área.

# AMPACIDADE - RESULTADOS OBTIDOS

1
6
Área | Carga | FCA (1 circuito) | IP - i projeto (a) < | IZC- capac. I cabo corrigida (a) > | IZ - Cap. I cabo (a) | Bitola (mm²) | Fator de Demanda
1 | Motor 1 | 1,00 | 487,46 | 519,48 | 481,00 | 240,00 | 1,00

Motor 2

Motor 3

Motor 4

2

Motor 5

Motor 6 | 1,00 | 176,19 | 189,00 | 175,00 | 50,00 | 1,00

Motor 7

3

Auxiliar

1,00 | 392,06 | 440,64 | 408,00 | 185,00 | 1,00

Auxiliar

Aquecimento 1

Aquecimento 2

Aquecimento 3

# DISJUNTORES E CONDUTORES PARA CADA ÁREA

1
7

## QUEDA DE TENSÃO

Avaliou-se a queda de tensão admissível nos circuitos, conforme a fórmula:

Onde:

- S = Seção do condutor (mm²)
- p = Resistividade elétrica do material do condutor (Ω·mm²/m) - Cobre
- e% = Queda de tensão admissível (em porcentagem, ex: 4% → 0,04)
- Vff² = Tensão entre fases (V) elevado ao quadrado
- ∑(P ⋅l)= Soma dos produtos entre potências de carga (W) e seus respectivos comprimentos (m)
- P = Potência da carga (W)
- l = Comprimento do trecho do condutor até a carga (m)

# QUEDA DE TENSÃO - RESULTADOS OBTIDOS

1
8
Área | Carga | Raiz de 3 | p | e(%) | Tensão Fase-Fase 380V | Comprimento Circ. (L) | Fórmula Seção Queda Tensão | Bitola – (mm²)
1 | Motor 1 | 1,73 | 0,02 | 0,02 | 144400 | 25 | 80,32 | 95

Motor 2

Motor 3

Motor 4

2

Motor 5

Motor 6 | 1,73 | 0,02 | 0,02 | 144400 | 35 | 41,11 | 50

Motor 7

3

Auxiliar

1,73 | 0,02 | 0,02 | 144400 | 30 | 82,61 | 95

Auxiliar

Aquecimento 1

Aquecimento 2

Aquecimento 3

# DISJUNTORES E CONDUTORES PARA CADA ÁREA

1
9

## SEÇÃO MÍNIMA

Considerou-se também a seção mínima exigida pelas normas para fins de proteção mecânica e segurança da

instalação, baseando-se nas correntes nominais dos motores, tomando como referência a norma ABNT NBR

5410:2004 - Tabela 37; para escolha dos condutores.

# SEÇÃO MÍNIMA - RESULTADOS OBTIDOS

2
0
ÁREA | CARGA | IP - I PROJETO (A) < | SEÇÃO MÍNIMA
1 | Motor 1 | 487,46 | 2x95.00

Motor 2

Motor 3

Motor 4

2

Motor 5

Motor 6 | 176,19 | 70,00

Motor 7

3

Auxiliar

392,06 | 185,00

Auxiliar

Aquecimento 1

Aquecimento 2

Aquecimento 3

# DISJUNTORES E CONDUTORES PARA CADA ÁREA

2
1

## RESULTADOS OBTIDOS

Área | Cabo mm² -Ampacidade | Cabo mm² -queda de tensão | Cabo mm² -seção mínima | Cabo mm² -escolhido | Corrente do Disjuntor (A) | Modelo Disjuntores
1 | 240 | 95 | 2x95.00 | 2x95.00 | 500 | DWB650S500-3DA
2 | 50 | 50 | 70 | 70 | 180 | DWB250N200-3DF
3 | 185 | 95 | 185 | 185 | 400 | DWB400N400-3DA

# CONDUTORES E DISJUNTOR GERAL - QGF

2
2

## RESULTADOS OBTIDOS

Setor | Cabo mm² -Ampacidade | Cabo mm² -queda de tensão | Cabo mm² -seção mínima | Cabo mm² -escolhido | Corrente do Disjuntor (A) | Modelo Disjuntor
QGF | 4x180 | 70 | 4x150 | 4x180 | 1600 | DWA1600S-1600-3ET

NOTA: Todos os cálculos foram feitos considerando método de instalação B1 e cabos EPR/XLPE -ABNT NBR 5410:2004;

2
3

Para o desenvolvimento do projeto, considerou-se que a instalação elétrica seria destinada a uma indústria alimentícia de médio porte, cenário coerente com o perfil das cargas definidas no projeto base.

Divisão da instalação:

- Área 1 e 2: Motores trifásicos destinados a esteiras, bombas e misturadores, que exigem controle de velocidade, robustez e integração com sistemas de automação;
- Área 3: Sistemas de aquecimento e cargas auxiliares, como iluminação e tomadas gerais da fábrica.

Critério de escolha das chaves de partida:

- Inversores de frequência (Setores 1 e 2):

Aplicados em motores com necessidade de controle de velocidade, automação e partidas suaves.

- Disjuntores alimentadores (Setor 3):

Utilizados nos aquecedores e cargas resistivas (iluminação e tomadas), que não requerem controle dinâmico

de partida.

# MÉTODO DE PARTIDA

2
4

Inversores de Frequência:
- Modelo escolhido: Linha CFW500 da WEG, devido à sua ampla aplicação industrial, fácil integração com CLPs e boa disponibilidade no mercado nacional.


Fonte: site WEG

Modo de operação:

- Heavy Duty (HD): Usado na maioria dos motores, adequado para partidas frequentes e alto torque;
- Normal Duty (ND): Utilizado no Motor 4, por limitação de corrente no modo HD para esse modelo específico.
Motor | Corrente do Motor | Modo de Operação | Corrente do Inversor | Inversor Escolhido
Motor 1 | 70.15 | HD | 73 | CFW500F88P0T4
Motor 2 | 170.37 | HD | 180 | CFW500G0211T4
Motor 3 | 44.09 | HD | 49 | CFW500E49P0T4
Motor 4 | 202.85 | ND | 211 | CFW500G0211T4
Motor 5 | 30.25 | HD | 31 | CFW500D31P0T4
Motor 6 | 101.85 | HD | 115 | CFW500G0142T4
Motor 7 | 44.09 | HD | 49 | CFW500E49P0T4

# MÉTODO DE PARTIDA

# MÉTODO DE PARTIDA

2
5

Fonte: site rockwell
automation

Reatores de linha

Finalidade:

- Proteger os inversores contra surtos e picos de corrente;
- Reduzir distorções harmônicas e melhorar a qualidade da

energia;

- Prolongar a vida útil dos equipamentos.

Aplicação:

- Utilizados em todos os circuitos com inversores;
- Instalados entre o disjuntor e o inversor.

2
6

Fonte: site rockwell
automation
Inversor | Corrente do Drive (A) | Indutância Necessária (mH) | Reator Escolhido | Dados do Reator
CFW500F88P0T4 | 73 | 0.2399 | 1321-3R80-B | 80A e 0.4mH
CFW500G0211T4 | 180 | 0.0973 | 1321-3R200-B | 200A e 0.11mH
CFW500E49P0T4 | 49 | 0.3574 | 1321-3R55-B | 55A e 0.5mH
CFW500G0211T4 | 211 | 0.0830 | 1321-3R200-B | 200A e 0.11mH
CFW500D31P0T4 | 31 | 0.5649 | 1321-3R35-B | 35A e 0.8mH
CFW500G0142T4 | 115 | 0.1523 | 1321-3R130-B | 130A e 0.2mH
CFW500E49P0T4 | 49 | 0.3574 | 1321-3R55-B | 55A e 0.5mH

# MÉTODO DE PARTIDA

Dimensionamento:
Utilizou-se a fórmula recomendada no Manual do CFW500 da WEG (pág. 119):

L =

1592 × ΔV × Ve
Is. nom × f

Onde:
- ΔV: queda de tensão (%);
- Ve: tensão de entrada por fase (V);
- Is,nom: corrente nominal do inversor (A);
- f: frequência da rede (Hz).

Nota: Os valores de indutância foram comparados com modelos comerciais. Os reatores da Rockwell foram escolhidos por fornecerem especificações técnicas completas.

# MÉTODO DE PARTIDA

2
7


Fonte: site WEG

Fonte: site WEG

Proteção com Disjuntores

Objetivo:

Proteger os inversores e cabos contra curtos-circuitos e sobrecorrentes.

Critérios de Seleção:
- Corrente nominal do inversor (modo HD ou ND);
- Corrente de curto-circuito no ponto de instalação;
- Recomendações do fabricante.

Dimensionamento:
Idisjuntor = Iinversor × F. deserviço

Referência Técnica:

Modelos selecionados com base no Manual do CFW500 – Anexo B, pág. 157

(WEG), que recomenda disjuntores específicos por inversor.

# MÉTODO DE PARTIDA

2
8

Disjuntores escolhidos:

Fonte: site WEG

Fonte: site WEG

Inversor | Corrente do inversor (A) | Disjuntor escolhido | Corrente do Disjuntor | Cap. de Interr. de CC
CFW500F88P0T4 | 73 | MPW80-3-U080 | 65-80 A (ajustável) | 65kA
CFW500G0211T4 | 180 | DWB250N200-3DF | 200 A (ajustável) | 36kA
CFW500E49P0T4 | 49 | MPW80-3-U050 | 40-50 A (ajustável) | 65kA
CFW500G0211T4 | 211 | DWB250N-250-3DF | 250 A (ajustável) | 36kA
CFW500D31P0T4 | 31 | MPW40-3-U032 | 25-32 A (ajustável) | 50kA
CFW500G0142T4 | 115 | DWB160N-125-3DF | 125 A (ajustável) | 36kA
CFW500E49P0T4 | 49 | MPW80-3-U050 | 40-50 A (ajustável) | 65kA

# MÉTODO DE PARTIDA

2
9

Diagrama de ligação inversor de frequência

Fonte: site WEG

# CORREÇÃO DE FATOR DE POTÊNCIA

A correção do fator de potência foi implementada nas Áreas 1 e 2 da planta industrial em função dos baixos níveis de fator de potência medidos, os quais se encontravam inferiores ao limite mínimo de 0,92, conforme exigido pela Resolução Normativa nº 1000, de 07 de dezembro de 2021, da Agência Nacional de Energia Elétrica (ANEEL).

3
0
Área | FP Total Por Área | Ângulo
1 | 0,813 | 35,56
2 | 0,793 | 37,50
3 | 0,949 | 18,30
Área | Potência Ativa Total (Kw) | Potência Reativa Total (KVAr)
1 | 261,00 | 135,04
2 | 92,00 | 49,76
3 | 245,00 | 58,79

# CORREÇÃO DE FATOR DE POTÊNCIA

3
1

Com o valor de Qc, foi possível determinar a quantidade de potência reativa que deve ser inserida no sistema por meio dos capacitores, a fim de elevar o fator de potência ao valor desejado de FPnovo = 0,95 para ambas as áreas, atendendo aos requisitos da concessionária e melhorando o desempenho elétrico da instalação.

Área | FP Antigo | Ângulo Antigo | FP Novo (desejado) | Ângulo Novo (desejado) | Potência Ativa Total (kW) | Potência Reativa Total (kVAr) | Potência Necessária do Banco (kVAr)
1 | 0,81 | 35,56 | 0,95 | 18,19 | 261 | 135,036 | 49,25
2 | 0,79 | 37,5 | 0,95 | 18,19 | 92 | 49,764 | 19,53

Qc = Q - ( P*(Tan(arcos(FPnovo)))

# CORREÇÃO DE FATOR DE POTÊNCIA

3
2

Foram especificados bancos de capacitores da linha BCW da WEG, fixos de correção do fator de potência. Esses capacitores trifásicos são dimensionados para operação em redes com tensão nominal de até 440 V e frequência de 60 Hz, possuindo construção robusta com filme de polipropileno metalizado, o que assegura:
- Elevada confiabilidade operacional,
- Alta resistência a sobrecargas,
- Autoproteção contra falhas dielétricas,
- Conformidade com as normas IEC 60831-1 e IEC 60831-2.
Área | Banco de capacitores | Potência reativa do banco (kvar) | Unidade capacitiva do banco | Qtd.
1 | BCW50V40 T | 50 | UCWT50V40 U28 HD | 1
2 | BCW20V40 T | 20 | UCWT20V40 Q26 HD | 1

## BANCO DE CAPACITORES

Fonte: site WEG

# CORREÇÃO DE FATOR DE POTÊNCIA

3
3

Em ambientes com cargas não lineares, como inversores de frequência, utilizam-se reatores de dessintonia conectados com os bancos de capacitores para evitar ressonâncias harmônicas, proteger os equipamentos e garantir estabilidade no sistema.
Para proteger os capacitores contra harmônicos, foram adotados reatores de dessintonia com frequência de dessintonia em 160,4 Hz, correspondendo a 14% de dessintonia.
Essa solução proporciona:
- Mitigação de distorções harmônicas no sistema,
- Aumento da vida útil dos capacitores,
- Manutenção da qualidade da energia elétrica,


- Melhoria do desempenho global do sistema de compensação reativa.
Área | Modelo | Tensão (V) | Potência Reativa (kVAr) | Corrente (A)
1 | DRW14-1,22V40 | 380 | 51 | 77,7 A
2 | DRW14-2,85V40 | 380 | 21,9 | 33,2 A

## REATOR DE DESSINTONIA

Fonte: site WEG

# CORREÇÃO DE FATOR DE POTÊNCIA

3
4

O acionamento dos bancos de capacitores é feito por contatores da linha CWBC da WEG, que incluem resistores de limitação de corrente de inserção para proteger os capacitores contra picos de corrente durante a energização.

Área | Modelo do Contator | Tensão Nominal de Isolação (V) | Corrente Nominal (A)
1 | CWBC65-21-30D23 | 690 | 65
2 | CWBC25-21-30C15 | 690 | 25

## CONTATORES

Fonte: site WEG

NOTA: Este componente faz parte do conjunto e é recomendado no próprio catálogo da WEG para uso com o banco de capacitores. Ao selecionar um banco de capacitores no catálogo, a WEG já indica os disjuntores e contatores compatíveis, e o grupo optou por seguir essas recomendações.

# CORREÇÃO DE FATOR DE POTÊNCIA

3
5

A proteção do sistema foi realizada com disjuntores termomagnéticos da linha DWB da WEG, dimensionados com base nas correntes corrigidas após inserção dos reatores e na seção dos cabos utilizados.

Área | Modelo do Disjuntor | Corrente Nominal (A) | Corrente de interrupção (KA) | Polos
1 | DWB160B125-3DX | 125 | 16 | 3
2 | DWB160B50-3DX | 50 | 16 | 3

## DISJUNTORES

NOTA: Este componente faz parte do conjunto e é recomendado no próprio

catálogo da WEG para uso com o banco de capacitores. Ao selecionar um banco de capacitores no catálogo, a WEG já indica os disjuntores e contatores compatíveis, e o grupo optou por seguir essas recomendações.

# TRANSFORMADOR DE POTÊNCIA

- Para especificarmos adequadamente o transformador de potência da instalação, é necessário, primeiramente, calcular a potência aparente (kVA) de cada setor da planta industrial.
- É importante destacar que, ao especificar o transformador, foi considerado um acréscimo de 35% sobre a potência aparente total da instalação, com o objetivo de acomodar futuras expansões da planta industrial.
- Na tabela a seguir podemos ver a distribuição das potências aparentes por máquina e por setor:

3
6

# TRANSFORMADOR DE POTÊNCIA

3
7
Área | Carga | Potência ativa (kW) | Potência reativa (kVAr) | Potência aparente (kVA)
1 | Motor 1 | 37,00 | 20,08 | 46,17
| Motor 2 | 92,00 | 45,93 | 112,13
| Motor 3 | 22,00 | 12,90 | 29,02
| Motor 4 | 110,00 | 56,13 | 133,51
2 | Motor 5 | 15,00 | 8,80 | 19,91
| Motor 6 | 55,00 | 28,07 | 67,04
| Motor 7 | 22,00 | 12,90 | 29,02
3 | Auxiliar | 75,00 | 29,39 | 81,52
| Auxiliar | 75,00 | 29,39 | 81,52
| Aquecimento 1 | 30,00 | 0,00 | 30,00
| Aquecimento 2 | 25,00 | 0,00 | 25,00
| Aquecimento 3 | 40,00 | 0,00 | 40,00

# TRANSFORMADOR DE POTÊNCIA

3
8

Já a tabela abaixo demonstra a potência total que deverá ser suprida pelo transformador:

Pot. Ativa Total (KW) | Pot. Aparente Total (kVA) | Pot. Reativa Total (KVAr) | Aumento de Carga (%) | Potência Necessária do trafo (KVA)
598,00 | 694,85 | 243,59 | 35,00 | 938,05

Equipamento escolhido: Transformador Trifásico Seco 14543301 da fabricante WEG, do tipo abaixador, com potência nominal de 1000kVA - conforme a norma NBR 5356-11;

Especificações:
- Primário: 13,8kV , enrolamento em Triângulo;
- Secundário: 380V , enrolamento em Estrela;
- Rendimento com FP Unitário: aprox. 98%
- Impedância Base: 6%;
- Perdas Totais: 14,6 kW a 120ºC;
- Grau de Proteção: IP-23;
- Monitor de temperatura dos enrolamentos (PT100)

# TRANSFORMADOR DE POTÊNCIA


FOTOS:

3
9

Fonte: Manual de instalação de transformadores a seco WEG

# NÍVEIS DE CURTO-CIRCUITO

- O Curto-Circuito ocorre quando há uma ligação acidental entre condutores com diferença de potencial, gerando uma corrente excessiva.
- Consequências do curto-circuito:
- Superaquecimento;
- Queima de equipamentos;
- Riscos de incêndio e à segurança dos operadores.
- Essa análise também influencia:
- Escolha e coordenação das proteções;
- Dimensionamento de barramentos e condutores.
- A norma ABNT NBR IEC 60947-2 exige que a capacidade de interrupção dos disjuntores (Icc) seja superior à corrente de curto-circuito presumida no ponto de instalação, garantindo o desligamento seguro do circuito.
4
0

# NÍVEIS DE CURTO -CIRCUITO

41

Foram consideradas os seguintes tipos de faltas • Curto-circuito trifásico; • Curto-circuito fase-terra.

Fórmulas utilizadas
Curto

-Circuito Trifásico:

Ics

=

Vbase 3 × Zeq

- Ics
: Corrente trifásica de curto

-circuito (A);
- Vbase
: Tensão de linha (V);
- Zeq
: Impedância equivalente até o ponto de falta (Ω).

Curto

-Circuito Fase
-Terra:
Icft

=

Vfase
Z1

+ Z2

+ Z0

+ 3Zf

- Icft
: Corrente de curto fase

-terra (A);
- Z1, Z2, Z0: Impedâncias de sequência positiva, negativa e zero (Ω); • Zf: Impedância de falta à terra (considerada nula).

# NÍVEIS DE CURTO-CIRCUITO


Dados base:

- Tensão base (MT): 13,8 Kv;
- Tensão base (BT): 380 V;
- Potência base: 100 MVA.

Impedâncias de suprimento (pu):

- Sequência positiva (Z₁):
R = 0,02 | X = 0,50
- Sequência negativa (Z₂):
R = 0,02 | X = 0,50
- Sequência zero (Z₀):
R = 0,04 | X = 0,80

4
2

# NÍVEIS DE CURTO-CIRCUITO

4
3

Impedância dos condutores
- Os dados de impedância dos condutores não estavam acessíveis no catálogo do fabricante. Para garantir consistência técnica, foram utilizados valores médios extraídos da tabela da atividade “Ma1 – Curto-Circuito”, conforme mostrado na imagem abaixo.


Fonte: Ma1: curto-circuito em instalação elétrica industrial


# NÍVEIS DE CURTO-CIRCUITO

4
4

Corrente de Curto-Circuito Assimétrica
- Em um curto-circuito, além da componente alternada (AC), existe uma componente contínua (DC) transitória que causa a assimetria da corrente nos primeiros ciclos;
- Essa condição é mais severa nos instantes iniciais da falta e deve ser considerada no dimensionamento das proteções.

Método 1 (tabela):
Ica = Fassimetria × Ics

Método 2 (Cálculo do fator de assimetria):

Ica = Ics × 1 + 2e

−2τ/t

Onde:
- Ica: Corrente de curto-circuito assimétrica (A);
- Ics: Corrente de curto-circuito simétrica (A);
- τ: Constante de tempo = X
2πfR;
- t: Tempo considerado (1/4 ciclo = 4,16 ms).

# NÍVEIS DE CURTO-CIRCUITO


4
5

Fatores de assimetria

Os fatores de assimetria foram obtidos da tabela da atividade “Ma1 – Curto-Circuito”, para t = 1/4 ciclo.

Fonte: Ma1: curto-circuito em instalação elétrica industrial

# NÍVEIS DE CURTO-CIRCUITO

4
6

Resultados obtidos:

A seguir, são apresentados os resultados obtidos para as correntes de curto-circuito nas barras do sistema, determinados por meio

de cálculos analíticos:

Local | Ics (A) | Icft (A) | Fator de assimetria | Ica (A)
Fornecimento de Energia | 8360.7093 | 6965.9528 | 1.6626 | 13900.3611
Transformador - lado BT | 23393.3324 | 23040.2170 | 1.4540 | 34014.3752
QGF | 22614.1373 | 22532.8650 | 1.4231 | 32181.1683
CCM1 | 18386.3684 | 8708.2246 | 1.2155 | 22348.3320
CCM2 | 11711.2390 | 4366.3327 | 1.0441 | 12227.8560
CCM3 | 15751.9670 | 5132.0955 | 1.2201 | 19218.2686


Planilha de cálculo de curto-circuito

# NÍVEIS DE CURTO-CIRCUITO


4
7

Simulação PSP-UFU:

Para a comprovação dos cálculos, foi realizada uma simulação no software PSP-UFU:

Simulação no PSP-UFU

# NÍVEIS DE CURTO-CIRCUITO

4
8

Simulação PSP-UFU:

Simulação no PSP-UFU

Falta trifásica geração | Falta trifásica sec. do trafo | Falta monofásica sec. do trafo

Falta trifásica QGF

Falta monofásica geração

Falta monofásica QGF | Falta trifásica CCM-1 | Falta monofásica CCM-1

# NÍVEIS DE CURTO-CIRCUITO

4
9

Simulação PSP-UFU:

Simulação no PSP-UFU

Falta trifásica CCM-2 | Falta monofásica CCM-2 | Falta trifásica CCM-3 | Falta monofásica CCM-3

Resultados obtidos:


| Fornecimento de Energia | Transformador lado BT | QGF | CCM-1 | CCM-2 | CCM-3
Ics (kA) | 8.36 | 23.01 | 22.22 | 17.87 | 11.33 | 15.49
Icft (kA) | 6.97 | 23.61 | 18.41 | 7.95 | 3.73 | 5.26

# UNIFILAR

## UNIFILAR.PDF (https://drive.google.com/drive/folders/16CMfxbv489ctTwxZcgn8KCuGW3tdL9AT)

5
0

# SUBESTAÇÃO ABRIGADA

5
1

A subestação será executada em cabine abrigada de alvenaria, conforme requisitos das normas GED-2855 e GED-2856, garantindo segurança, durabilidade e ventilação adequada, especialmente para ambientes industriais do setor alimentício.O transformador seco IP-23, com rendimento superior a 98%, requer ventilação forçada. Por isso, estão previstos um ventilador para insuflação de ar frio na parte inferior da sala e um exaustor na parte superior para remoção do ar quente.

Fonte: Norma GED 2856

# SUBESTAÇÃO ABRIGADA


5
2

Fonte: Norma GED 2856
Fonte: Norma GED 2856

# LUMINOTÉCNICO

- Local: escritório comum
- Dimensões: 20 x 15 metros
- Pé direito (PD): 3,5 metros
- Altura de Trabalho (H1): 0,8 metros
- Altura Lâmpada Teto (H2): 0,9 metros

5
3
- Teto: superfície branca
- Paredes: Brancas
- Pisos: escuros

O projeto luminotécnico a seguir se deu pela utilização dos seguintes parâmetros, é o cálculo feito através do software DIAlux EVO.

Fonte: DIAlux EVO

# LUMINOTÉCNICO

5
4

Com base nos dos passados e a informação que a área se tratava de um escritório comum, adotamos a pior situação possível que é 500 Lux de iluminância local, segundo a figura a seguir:


Fonte: CREDER, Hélio. Instalações elétricas. 16. ed. Rio de Janeiro: LTC, 2016. Tabela 13.4.

# LUMINOTÉCNICO

5
5

Agora iremos determinar o índice de reflexão que é a capacidade de uma superfície refletir a luz incidente, sendo expresso em forma percentual (%), Seguindo a parametrização estipulada pela norma, conforme a seguir, o índice escolhido foi 751, onde foi adotado 7 para paredes brancas, 5 para teto de superfície clara e 1 para pisos escuros

Fonte: CREDER, Hélio. Instalações elétricas. 16. ed. Rio de Janeiro: LTC, 2016. Tabela 13.7.

# LUMINOTÉCNICO

5
6

Agora iremos selecionar o fator de depreciação que é aplicado no cálculo luminotécnico para garantir que, mesmo com a degradação ao longo do tempo, o nível de iluminância continue adequado para a atividade exercida no ambiente. É uma forma de planejar uma iluminação duradoura e eficiente.

Fonte: CREDER, Hélio. Instalações elétricas. 16. ed. Rio de Janeiro: LTC, 2016. Tabela 13.9.

# LUMINOTÉCNICO


5
7

Foram utilizados o modelo da lâmpada a seguir, o modelo em questão demonstrou um bom desempenho nos cálculos feitos pelo grupo e a marca em questão possui renome internacional.

Fonte: DIAlux EVO

# LUMINOTÉCNICO

5
8

O grupo propôs um layout arquitetônico de móveis conforme a figura a seguir, para um dimensionamento luminotécnico mais profissional e para melhor compreensão.

NOTA: A área dos sofás, armários e bancadas foram desconsideradas dos cálculos, servindo apenas para teor ilustrativo.

# LUMINOTÉCNICO

5
9

A partir do layout arquitetônico proposto, foi possível definir as áreas destinadas às tarefas visuais. Conforme ilustrado nas imagens a seguir, essas áreas foram estrategicamente posicionadas sobre as mesas, que representam os principais pontos de execução das atividades laborais

# LUMINOTÉCNICO

6
0

Considerando que foi adotado um nível de iluminância de 500 lux sobre o plano de trabalho, conforme recomendado para ambientes de escritório que exigem tarefas visuais de complexidade média, a norma vigente estabelece que as áreas adjacentes a esse plano ou seja, os arredores imediatos devem apresentar, no mínimo, 300 lux de iluminância.


Fonte: CREDER, Hélio. Instalações elétricas. 16. ed. Rio de Janeiro: LTC, 2016. Tabela 13.5.

# LUMINOTÉCNICO

6
1

Os arredores da área de tarefa visual correspondem à zona que circunda diretamente a superfície onde se realiza a atividade principal, pela norma ABNT NBR ISO/CIE 8995-1 é estipulada em 0,5 metros.
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

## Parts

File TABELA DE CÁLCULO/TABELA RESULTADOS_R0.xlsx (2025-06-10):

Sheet: 1 - Dados iniciais de cargas
 |  |  |  |  |  |  |  |  |  | CARGAS (MOTORES E ILUMINAÇÃO) |  |  |  |  |  |  |  |  |  |  |  |  |  |  | ÁREAS |  |  |  |  |  |  |  |  |  |  |  |  |  |  |  |  | DISJUNTOR GERAL QDF
Setor | Carga | Potência mecânica (cv) | Fator de potência (cos fi) | Ângulo | Sen FI | Rendimento | Potência ativa (kW) | Potência reativa (kVAr) | Potência aparente (kVA) | FCT 20° | FCA 4 Circuitos (Pior Caso) | I PROJETO (In 380) (A) < | IZC- CAPAC. I CABO CORRIGIDA (A) | IZ - CAPC. I CABO (A) < | Bitola - mm² | MOTORES | RAIZ DE 3 | p | e(%) | Tensão Fase-Fase 380v | comprimento circ. (L) | Fórmula SEÇÃO QUEDA TENSÃO | BITOLA - mm² | SEÇÃO MÍNIMA | FCT 20° | FCA (1 circuito) | IP - I PROJETO (A) < | IN - DISJ (A) | IZC- CAPAC. I CABO CORRIGIDA (A) < | IZ - CAPC. I CABO (A) | Bitola - mm² | Fator de Demanda | ÁREA | RAIZ DE 3 | p | e(%) | Tensão Fase-Fase 380v | comprimento circ. (L) | Fórmula SEÇÃO QUEDA TENSÃO | BITOLA mm² | SEÇÃO MÍNIMA | FCT 20° | FCA (1 circuito) | IP - I PROJETO (A) < | IP - I PROJETO COM 35% DE PREVISÃO PARA CARGAS FUTURAS | IN - DISJ (A) | IZC- CAPAC. I CABO CORRIGIDA (A) < | IZ - CAPC. I CABO (A) | Bitola - mm² | Fator de Demanda | RAIZ DE 3 | p | e(%) | Tensão Fase-Fase 380v | comprimento circ. (L) | Fórmula SEÇÃO QUEDA TENSÃO
1 | Motor 1 | 50.00 | 0.84 | 32.86 | 0.54 | 0.954 | 37.00 | 20.08 | 46.17 | 1.08 | 0.65 | 70.15 | 82.13 | 117.00 | 25.00 | MOTOR 1 | 1.73 | 0.02 | 0.02 | 144400.00 | 5.00 | 2.28 | 2.50 | 16.00 | 1.08 | 1.00 | 487.46 | reg 500 | 519.48 | 481.00 | 240.00 | 1.00 | 1.00 | 1.73 | 0.02 | 0.02 | 144400.00 | 25.00 | 80.32 | 95.00 | 2x95.00 | 1.08 | 1.00 | 1055.71 | 1425.21 | DWA1600S-1600-3ET REG 1100 | 1762.56 | 1632.00 | 4X180mm² | 1.00 | 1.73 | 0.02 | 0.02 | 144400.00 | 10.00 | 65.09
 | Motor 2 | 125.00 | 0.86 | 30.68 | 0.51 | 0.954 | 92.00 | 45.93 | 112.13 | 1.08 | 0.65 | 170.37 | 188.84 | 269.00 | 95.00 | MOTOR 2 | 1.73 | 0.02 | 0.02 | 144400.00 | 5.00 | 5.53 | 6.00 | 50.00
 | Motor 3 | 30.00 | 0.81 | 35.90 | 0.59 | 0.936 | 22.00 | 12.90 | 29.02 | 1.08 | 0.65 | 44.09 | 61.78 | 88.00 | 16.00 | MOTOR 3 | 1.73 | 0.02 | 0.02 | 144400.00 | 5.00 | 1.40 | 1.50 | 6.00
 | Motor 4 | 150.00 | 0.86 | 30.68 | 0.51 | 0.958 | 110.00 | 56.13 | 133.51 | 1.08 | 0.65 | 202.85 | 219.02 | 312.00 | 120.00 | MOTOR 4 | 1.73 | 0.02 | 0.02 | 144400.00 | 5.00 | 6.61 | 10.00 | 70.00
2 | Motor 5 | 20.00 | 0.81 | 35.90 | 0.59 | 0.930 | 15.00 | 8.80 | 19.91 | 1.08 | 0.70 | 30.25 | 36.29 | 48.00 | 6.00 | MOTOR 5 | 1.73 | 0.02 | 0.02 | 144400.00 | 5.00 | 0.96 | 1.00 | 4.00 | 1.08 | 1.00 | 176.19 | reg 180 | 189.00 | 175.00 | 50.00 | 1.00 | 2.00 | 1.73 | 0.02 | 0.02 | 144400.00 | 35.00 | 41.11 | 50.00 | 70.00
 | Motor 6 | 75.00 | 0.86 | 30.68 | 0.51 | 0.954 | 55.00 | 28.07 | 67.04 | 1.08 | 0.70 | 101.85 | 108.86 | 144.00 | 35.00 | MOTOR 6 | 1.73 | 0.02 | 0.02 | 144400.00 | 5.00 | 3.31 | 4.00 | 25.00
 | Motor 7 | 30.00 | 0.81 | 35.90 | 0.59 | 0.936 | 22.00 | 12.90 | 29.02 | 1.08 | 0.70 | 44.09 | 49.90 | 66.00 | 10.00 | MOTOR 7 | 1.73 | 0.02 | 0.02 | 144400.00 | 5.00 | 1.40 | 1.50 | 6.00
3 | Auxiliar | - | 0.92 | 23.07 | 0.39 | 1.000 | 75.00 | 29.39 | 81.52 | 1.08 | 0.80 | 123.86 | 151.20 | 175.00 | 50.00 | Auxiliar | 1.73 | 0.02 | 0.02 | 144400.00 | 5.00 | 4.21 | 6.00 | 35.00 | 1.08 | 1.00 | 392.06 | reg 400 | 440.64 | 408.00 | 185.00 | 1.00 | 3.00 | 1.73 | 0.02 | 0.02 | 144400.00 | 30.00 | 82.61 | 95.00 | 185.00
 | Auxiliar | - | 0.92 | 23.07 | 0.39 | 1.000 | 75.00 | 29.39 | 81.52 | 1.08 | 0.80 | 123.86 | 151.20 | 175.00 | 50.00 | Auxiliar | 1.73 | 0.02 | 0.02 | 144400.00 | 5.00 | 4.21 | 6.00 | 35.00
 | Aquecimento 1 | - | 1.00 | 0.00 | 0.00 | 1.000 | 30.00 | 0.00 | 30.00 | 1.08 | 0.70 | 45.58 | 49.90 | 66.00 | 10.00 | Aquecimento 1 | 1.73 | 0.02 | 0.02 | 144400.00 | 5.00 | 1.55 | 2.50 | 6.00
 | Aquecimento 2 | - | 1.00 | 0.00 | 0.00 | 1.000 | 25.00 | 0.00 | 25.00 | 1.08 | 0.70 | 37.98 | 49.90 | 66.00 | 10.00 | Aquecimento 2 | 1.73 | 0.02 | 0.02 | 144400.00 | 5.00 | 1.29 | 2.50 | 6.00
 | Aquecimento 3 | - | 1.00 | 0.00 | 0.00 | 1.000 | 40.00 | 0.00 | 40.00 | 1.08 | 0.70 | 60.77 | 66.53 | 88.00 | 16.00 | Aquecimento 3 | 1.73 | 0.02 | 0.02 | 144400.00 | 5.00 | 2.07 | 4.00 | 10.00
SETOR | POTÊNCIA ATIVA TOTAL (Kw) | POTÊNCIA REATIVA TOTAL (KVAr) | POTÊNCIA APARENTE TOTAL (KVA) | CORRENTE 440V TOTAL (A) | CORRENTE 380V TOTAL (A) | FP TOTAL POR SETOR | ÂNGULO
1 | 261.00 | 135.04 | 320.84 | #REF! | 487.46 | 0.813 | 35.56
2 | 92.00 | 49.76 | 115.97 | #REF! | 176.19 | 0.793 | 37.50
3 | 245.00 | 58.79 | 258.04 |  |  | 0.949 | 18.30
CAPACITORES
SETOR | FP ANTIGO FP1 | ÂNGULO ANTIGO | FP NOVO (DESEJADO) FP2 | ÂNGULO NOVO (DESEJADO) | POTÊNCIA ATIVA TOTAL (Kw) | POTÊNCIA REATIVA TOTAL (KVAr) | MÉTODO 1 |  | MODELO DE REFERÊNCIA | CABOS CAPACITOR
 |  |  |  |  |  |  | POTÊNCIA NECESSÁRIA DO BANCO (KVAr) |  | WEG BCWP OU BCW AMBOS FIXOS | VER LISTA DE MATERIAIS | REATOR DE DISSINTONIA | POTÊNCIA REATIVA (KVAr) | CORRENTE (A) | CORRENTE CORRIGIDA (A) | CABO ESCOLHIDO
1 | 0.81 | 35.56 | 0.95 | 18.19 | 261.00 | 135.036 | 49.25 |  | BCWP50V40D-V25 T = 50KVAr | BCW50V40 T | DRW14-1,22V40 | 50.00 | 75.97 | 102.56 | 25mm²
2 | 0.79 | 37.50 | 0.95 | 18.19 | 92.00 | 49.764 | 19.53 |  | BCWP20V40D-V25 T = 20KVAr | BCW20V40 T | DRW14-2,85V40 | 20.00 | 30.39 | 41.02 | 6mm²
 |  |  |  |  |  |  | Qc = Q - ( P*(Tan(arcos(𝐹𝑃1)))
TRANSFORMADOR
POTÊNCIA ATIVA TOTAL (KW) | POTÊNCIA APARENTE TOTAL (kVA) | POTÊNCIA REATIVA TOTAL (KVAr) | PREVISÃO DE AUMENTO DE CARGA (%) | POTÊNCIA NECESSÁRIA DO TRAFO (KVA) | REFERÊNCIA
598.00 | 694.85 | 243.59 | 35.00 | 938.05 | TRAFO WEG 1000 KVA (14543301) A SECO - 13,8/0,38 KV - 60HZ - IP-23 - ABRIGADO | não pode ficar fora

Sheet: 2 - Dados condutores áreas
Setor | Carga | Potência mecânica (cv) | Potência aparente (kVA) | Cabo mm² - Ampacidade | Cabo mm² - queda de tensão | Cabo mm² - seção mínima | Cabo mm² - escolhido | Disjuntor BT (A) | Modelo Disjuntores WEG (Reguláveis)
1 | Motor 1 | 50 | 46.17 | 25 | 2.5 | 16 | 25 | 80 | DISJUNTOR-MOTOR AZ 65-80 A
 | Motor 2 | 125 | 112.13 | 95 | 6.0 | 50 | 95 | 180 | DISJUNTOR CAIXA MOLDADA 200A 3 polos 30kA -Térmico ajustável e magnético fixo
 | Motor 3 | 30 | 29.02 | 16 | 1.5 | 6 | 16 | 50 | DISJUNTOR MOTOR AZ 40-50 A
 | Motor 4 | 150 | 133.51 | 120 | 10.0 | 70 | 120 | 210 | DISJUNTOR CAIXA MOLDADA 250A 3 polos 30kA -Térmico ajustável e magnético fixo
2 | Motor 5 | 20 | 19.91 | 6 | 1.0 | 4 | 6 | 32 | DISJUNTOR MOTOR AZ 25-32 A
 | Motor 6 | 75 | 67.04 | 35 | 4.0 | 25 | 35 | 105 | DISJUNTOR CAIXA MOLDADA 125A 3 polos 30kA -Térmico ajustável e magnético fixo
 | Motor 7 | 30 | 29.02 | 10 | 1.5 | 6 | 10 | 47 | DISJUNTOR MOTOR AZ 40-50 A
3 | Iluminação 1 | - | 81.52 | 50 | 6.0 | 35 | 50 | 125 | DISJUNTOR CAIXA MOLDADA 125A 3 polos 30kA -Térmico ajustável e magnético fixo
 | Iluminação 2 | - | 81.52 | 50 | 6.0 | 35 | 50 | 125 | DISJUNTOR CAIXA MOLDADA 125A 3 polos 30kA -Térmico ajustável e magnético fixo
 | Aquecimento 1 | - | 30.00 | 10 | 2.5 | 6 | 10 | 48 | DISJUNTOR CAIXA MOLDADA 50A 3 polos 30kA -Térmico ajustável e magnético fixo
 | Aquecimento 2 | - | 25.00 | 10 | 2.5 | 6 | 10 | 40 | DISJUNTOR CAIXA MOLDADA 40A 3 polos 30kA -Térmico ajustável e magnético fixo
 | Aquecimento 3 | - | 40.00 | 16 | 4.0 | 10 | 16 | 63 | DISJUNTOR CAIXA MOLDADA 63A 3 polos 30kA -Térmico ajustável e magnético fixo

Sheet: 3 - Dados condutores QGF-áreas
Setor | Potência ativa (kW) | Potência reativa (kVAr) | Potência aparente (kVA) | Cabo mm² - Ampacidade | Cabo mm² - queda de tensão | Cabo mm² - seção mínima | Cabo mm² - escolhido | Disjuntor BT (A) | Modelo Disjuntores WEG (Reguláveis)
1 | 261.00 | 135.04 | 320.84 | 240 | 95 | 2x95.00 | 2x95.00 | 500 | DISJUNTOR CAIXA MOLDADA 500A 3 polos 50kA - Térmico e magnético ajustável
2 | 92.00 | 49.76 | 115.97 | 50 | 50 | 70 | 70 | 230 | DISJUNTOR CAIXA MOLDADA 200A 3 polos 36kA -Térmico ajustável e magnético fixo
3 | 245.00 | 58.79 | 258.04 | 185 | 95 | 185 | 185 | 400 | DISJUNTOR CAIXA MOLDADA 400A 3 polos 36kA - Térmico e magnético ajustável

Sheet: 4 - Dados de curto-circuito
Setor | Corrente de curto-circuito
 | trifásico (Ics) - kA | monofásico franco (Icft) - kA | Fator de assimetria | Corrente de curto assimétrica (Ica) - kA
Ponto de entrega
Secundário do transformador
QGF
Barramento área 1
Barramento área 2
Barramento área 3

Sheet: 5 - Lista de materiais
TAG | CÓDIGO | DESCRIÇÃO | FABRICANTE
SUBESTAÇÃO
T01 | 14543301 | TRANSFORMADOR A SECO 1000kVA 13,8kV/380V 3F+N+PE | WEG
QGF - QUADRO GERAL DE FORÇA
QGERAL | DWA1600S-1600-3ET | DISJUNTOR CAIXA MOLDADA TRIPOLAR 1600A 50kA disparador eletrônico LSI | WEG
QDPS | DWB160N160-3DF | DISJUNTOR CAIXA MOLDADA 160A 3 polos 36kA -Térmico ajustável e magnético fixo | WEG
QTP | DWB160N16-3DX | DISJUNTOR CAIXA MOLDADA 16A 3 polos 36kA -Térmico e magnético fixos | WEG
TP | 380/115V 100VA | TRANSFORMADOR DE POTÊNCIAL 380/115V 100VA | SIEMENS
TC | 1600/5A | TRANSFORMADOR DE CORRENTE 1600/5A | SIEMENS
MEDIÇÃO | METSEPM5560 | MULTIMEDIDOR DE GRANDEZAS ELÉTRICAS | SCHNEIDER
DPS | 941315 | DISPOSITIVO DE PROTEÇÃO CONTRA SURTOS CLASSE I+II | DEHN
QAREA1 | DWB650S500-3DA | DISJUNTOR CAIXA MOLDADA 500A 3 polos 50kA - Térmico e magnético ajustável | WEG
QAREA2 | DWB250N200-3DF | DISJUNTOR CAIXA MOLDADA 200A 3 polos 36kA -Térmico ajustável e magnético fixo | WEG
QAREA3 | DWB400N400-3DA | DISJUNTOR CAIXA MOLDADA 400A 3 polos 36kA - Térmico e magnético ajustável | WEG
CCM AREA 1 - CENTRAL DE COMANDO DE MOTORES
QGERAL | DWB650S500-3DA | DISJUNTOR CAIXA MOLDADA 500A 3 polos 50kA - Térmico e magnético ajustável | WEG
QDPS | DWB160N160-3DF | DISJUNTOR CAIXA MOLDADA 160A 3 polos 36kA -Térmico ajustável e magnético fixo | WEG
DPS | 952405 | DISPOSITIVO DE PROTEÇÃO CONTRA SURTOS CLASSE II | DEHN
QA11 | MPW80-3-U080 | DISJUNTOR-MOTOR AZ 65-80 A | WEG
QA12 | DWB250N200-3DF | DISJUNTOR CAIXA MOLDADA 200A 3 polos 36kA -Térmico ajustável e magnético fixo | WEG
QA13 | MPW80-3-U050 | DISJUNTOR MOTOR AZ 40-50 A | WEG
QA14 | DWB250N-250-3DF | DISJUNTOR CAIXA MOLDADA 250A 3 polos 36kA -Térmico ajustável e magnético fixo | WEG
GA11 | CFW500F88P0T4 | INVERSOR DE FREQUÊNCIA 380-440V TRIFÁSICO 50CV HD:73A | WEG
GA12 | CFW500G0211T4 | INVERSOR DE FREQUÊNCIA 380-440V TRIFÁSICO 150CV HD:180A | WEG
GA13 | CFW500E49P0T4 | INVERSOR DE FREQUÊNCIA 380-440V TRIFÁSICO 30CV HD:49A | WEG
GA14 | CFW500G0211T4 | INVERSOR DE FREQUÊNCIA 380-440V TRIFÁSICO 150CV HD:180A | WEG
LA11 | 1321-3R80-B | REATOR DE ENTRADA 80A 0.4mH | ROCKWELL
LA12 | 1321-3R200-B | REATOR DE ENTRADA 200A 0.11mH | ROCKWELL
LA13 | 1321-3R55-B | REATOR DE ENTRADA 55A 0.5mH | ROCKWELL
LA14 | 1321-3R200-B | REATOR DE ENTRADA 200A 0.11mH | ROCKWELL
QA15 | DWB160B125-3DX | DISJUNTOR CAIXA MOLDADA 125A 3 polos 36kA -Térmico e magnético fixo | WEG
KA11 | CWBC65-21-30D23 | CONTATOR 65A (AC-6b - T = 55°C) 77A 220V 50/60Hz | WEG
LA15 | DRW14-1,22V40 | REATOR DE DESSINTONIA 1,222mH 77,5A | WEG
BCA11 | BCW50V40 T | BANCO DE CAPACITOR TRIFÁSICO FIXO 50kVAr 380V 60Hz | WEG
CCM AREA 2 - CENTRAL DE COMANDO DE MOTORES
QGERAL | DWB250N200-3DF | DISJUNTOR CAIXA MOLDADA 200A 3 polos 36kA -Térmico ajustável e magnético fixo | WEG
QDPS | DWB160N160-3DF | DISJUNTOR CAIXA MOLDADA 160A 3 polos 36kA -Térmico ajustável e magnético fixo | WEG
DPS | 952405 | DISPOSITIVO DE PROTEÇÃO CONTRA SURTOS CLASSE II | DEHN
QA21 | MPW40-3-U032 | DISJUNTOR MOTOR AZ 25-32 A | WEG
QA22 | DWB160N-125-3DF | DISJUNTOR CAIXA MOLDADA 125A 3 polos 36kA -Térmico ajustável e magnético fixo | WEG
QA23 | MPW80-3-U050 | DISJUNTOR MOTOR AZ 40-50 A | WEG
GA21 | CFW500D31P0T4 | INVERSOR DE FREQUÊNCIA 380-440V TRIFÁSICO 20CV HD:31A | WEG
GA22 | CFW500G0142T4 | INVERSOR DE FREQUÊNCIA 380-440V TRIFÁSICO 75CV HD:115A | WEG
GA23 | CFW500E49P0T4 | INVERSOR DE FREQUÊNCIA 380-440V TRIFÁSICO 30CV HD:49A | WEG
LA21 | 1321-3R35-B | REATOR DE ENTRADA 35A 0.8mH | WEG
LA22 | 1321-3R130-B | REATOR DE ENTRADA 130A 0.2mH | WEG
LA23 | 1321-3R55-B | REATOR DE ENTRADA 55A 0.5mH | WEG
QA24 | DWB160B50-3DX | DISJUNTOR CAIXA MOLDADA 50A 3 polos 36kA -Térmico e magnético fixo | WEG
KA21 | CWBC25-21-30C15 | CONTATOR 25 A (AC-6b - T = 55°C) 28A 220V DC | WEG
LA24 | DRW14-2,85V40 | REATOR DE DESSINTONIA 2,852mH 33,2A | WEG
BCA21 | BCW20V40 T | BANCO DE CAPACITOR TRIFÁSICO FIXO 20kVAr 380V 60Hz | WEG
QGFL AREA 3 - QUADRO GERAL DE FORÇA E LUZ
QGERAL | DWB400N400-3DA | DISJUNTOR CAIXA MOLDADA 400A 3 polos 36kA - Térmico e magnético ajustável | WEG
QDPS | DWB160N160-3DF | DISJUNTOR CAIXA MOLDADA 160A 3 polos 36kA -Térmico ajustável e magnético fixo | WEG
DPS | 952405 | DISPOSITIVO DE PROTEÇÃO CONTRA SURTOS CLASSE II | DEHN
QA31 | DWB160N125-3DF | DISJUNTOR CAIXA MOLDADA 125A 3 polos 36kA -Térmico ajustável e magnético fixo | WEG
QA32 | DWB160N125-3DF | DISJUNTOR CAIXA MOLDADA 125A 3 polos 36kA -Térmico ajustável e magnético fixo | WEG
QA33 | DWB160N50-3DF | DISJUNTOR CAIXA MOLDADA 50A 3 polos 36kA -Térmico ajustável e magnético fixo | WEG
QA34 | DWB160N40-3DF | DISJUNTOR CAIXA MOLDADA 40A 3 polos 36kA -Térmico ajustável e magnético fixo | WEG
QA35 | DWB160N63-3DF | DISJUNTOR CAIXA MOLDADA 63A 3 polos 36kA -Térmico ajustável e magnético fixo | WEG
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

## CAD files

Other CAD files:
DIAGRAMAS/DIAGRAMA UNIFILAR_R0.dwg

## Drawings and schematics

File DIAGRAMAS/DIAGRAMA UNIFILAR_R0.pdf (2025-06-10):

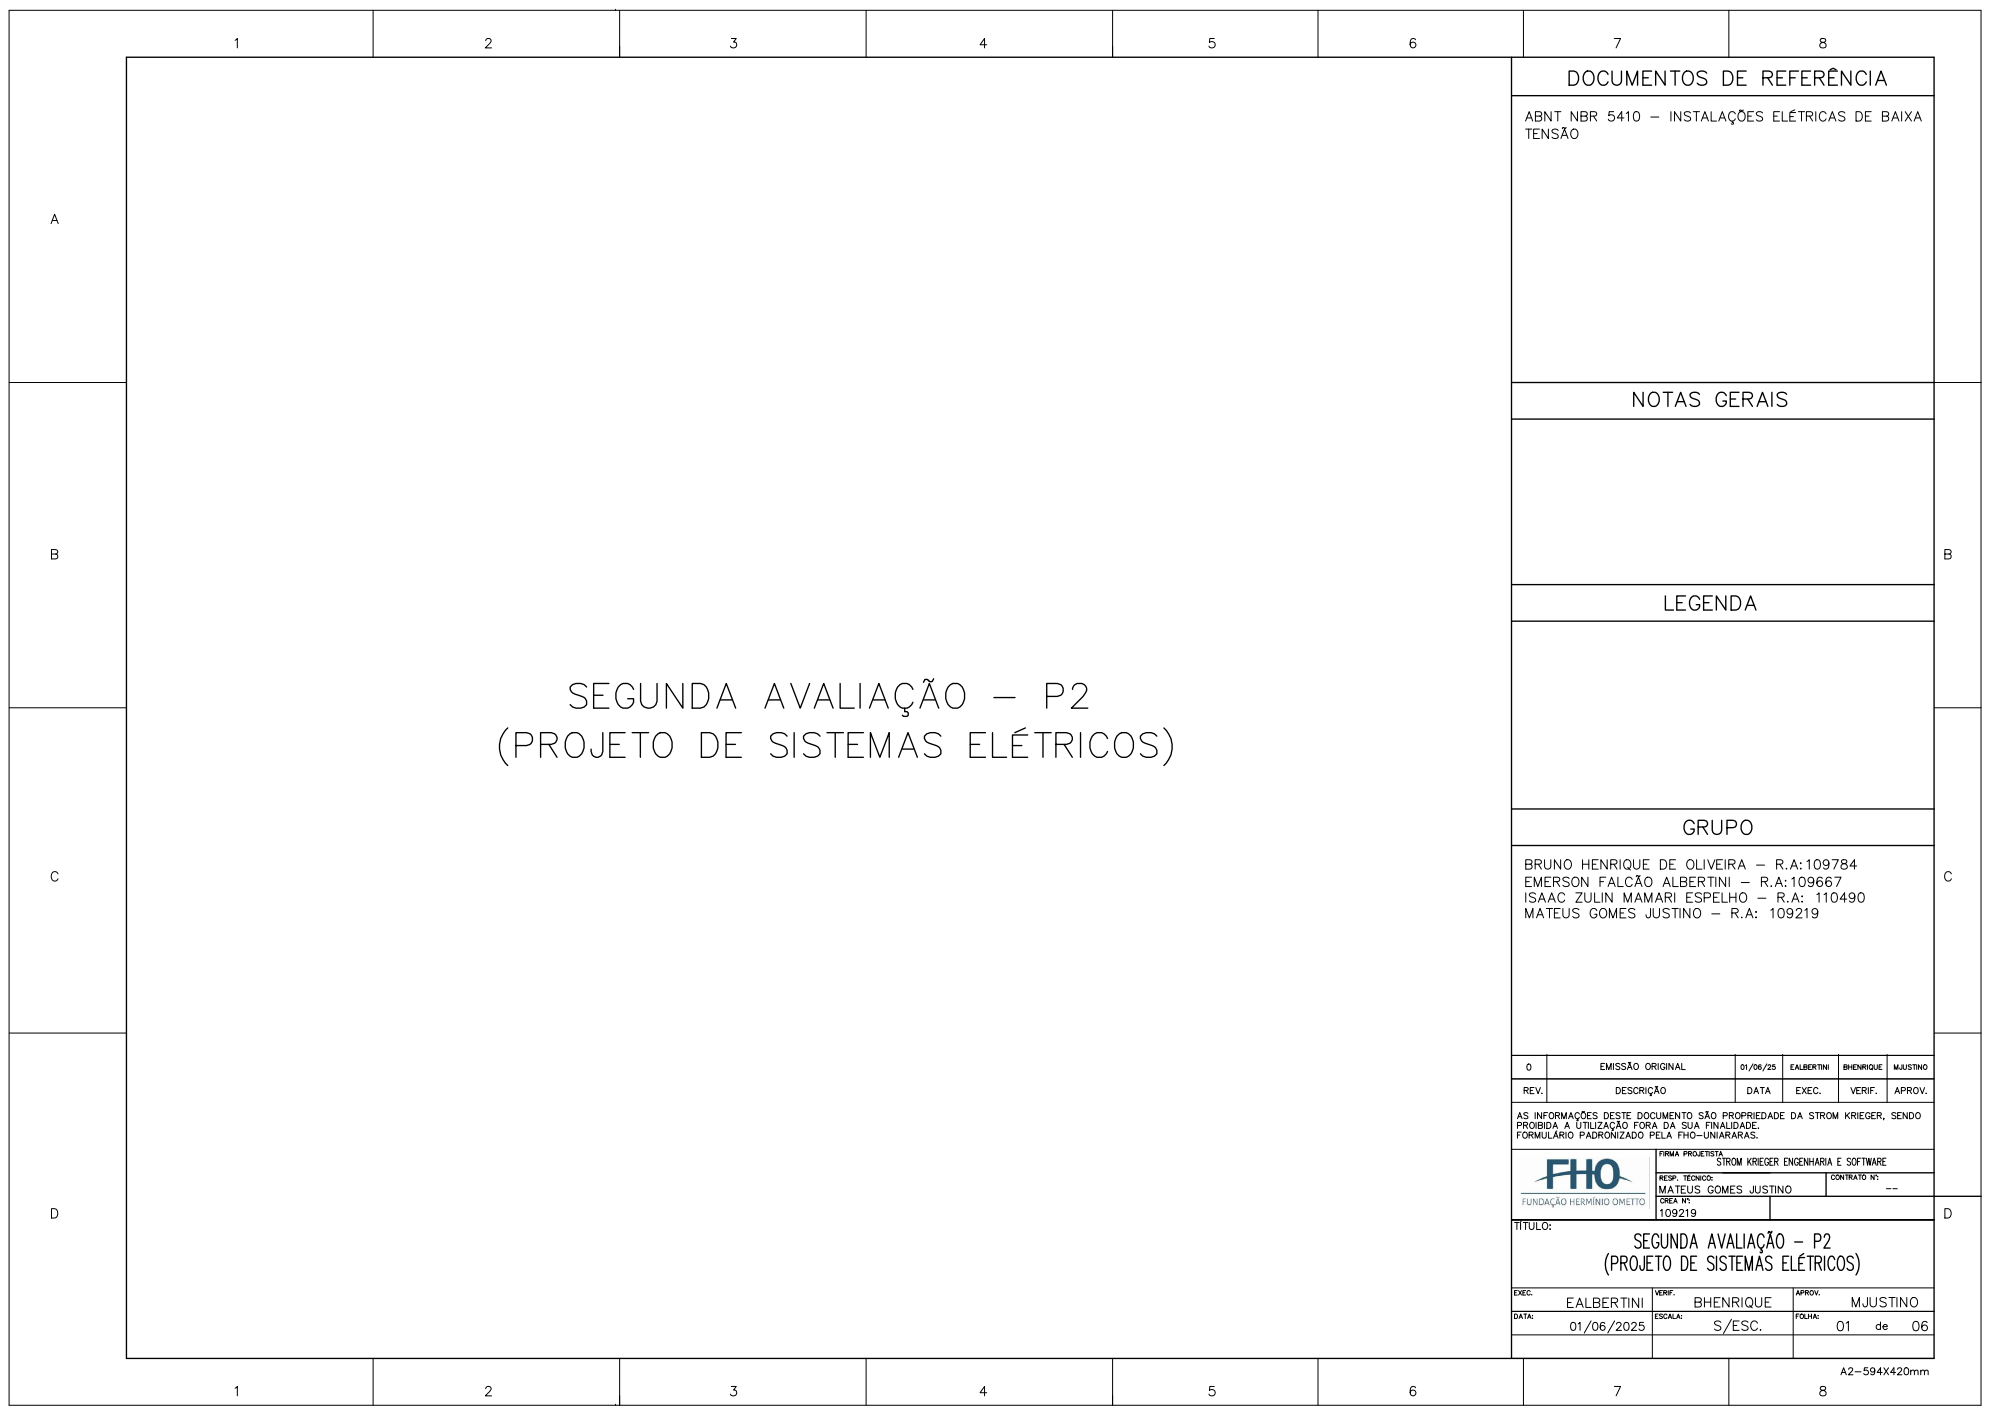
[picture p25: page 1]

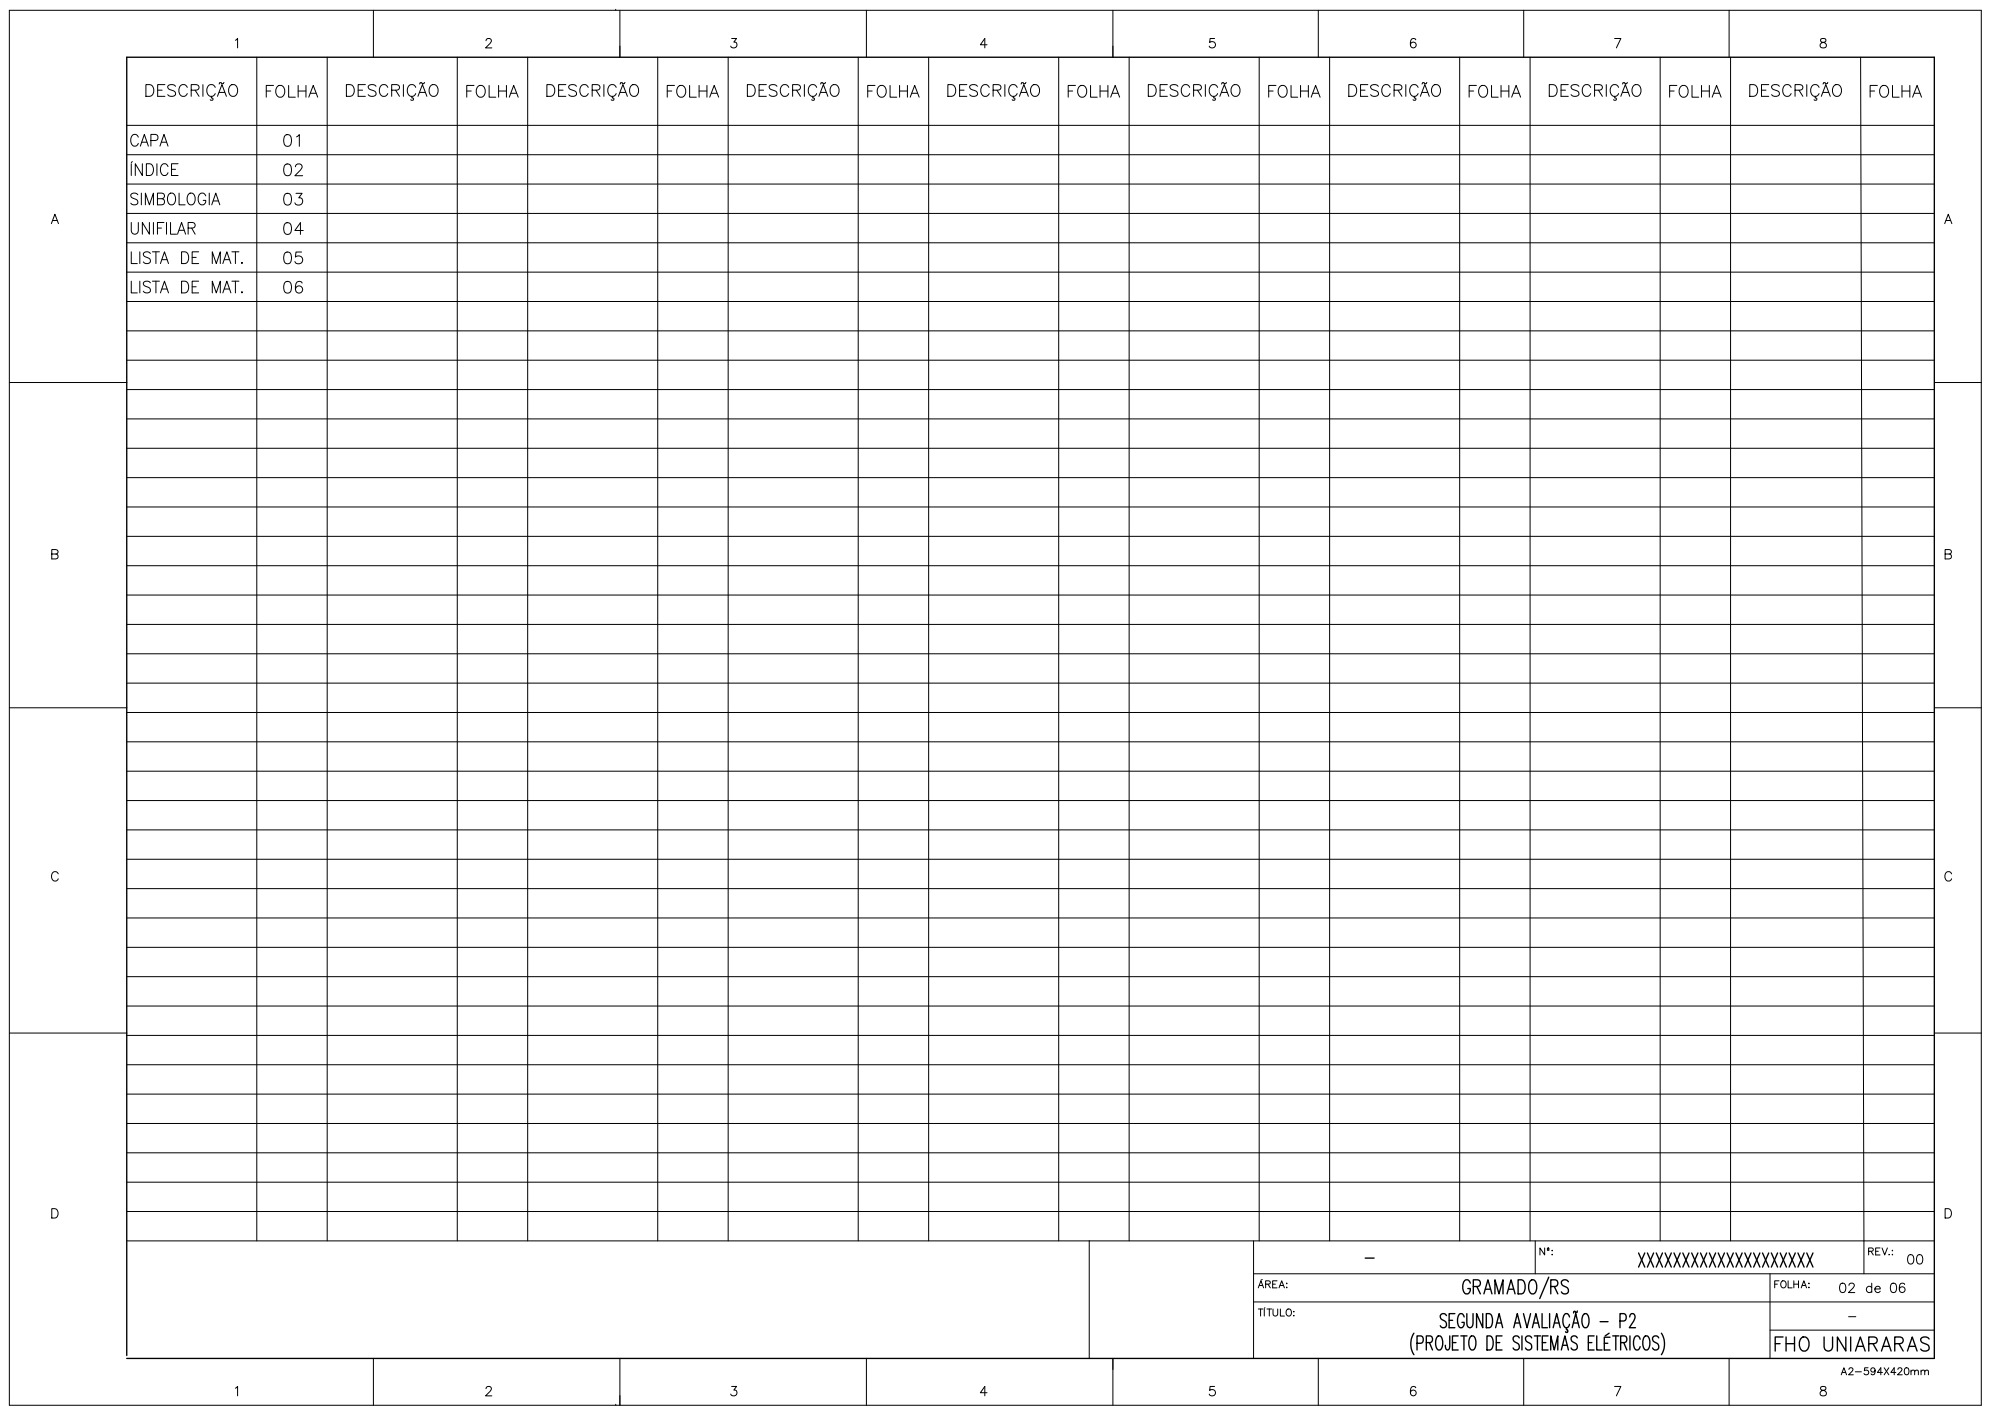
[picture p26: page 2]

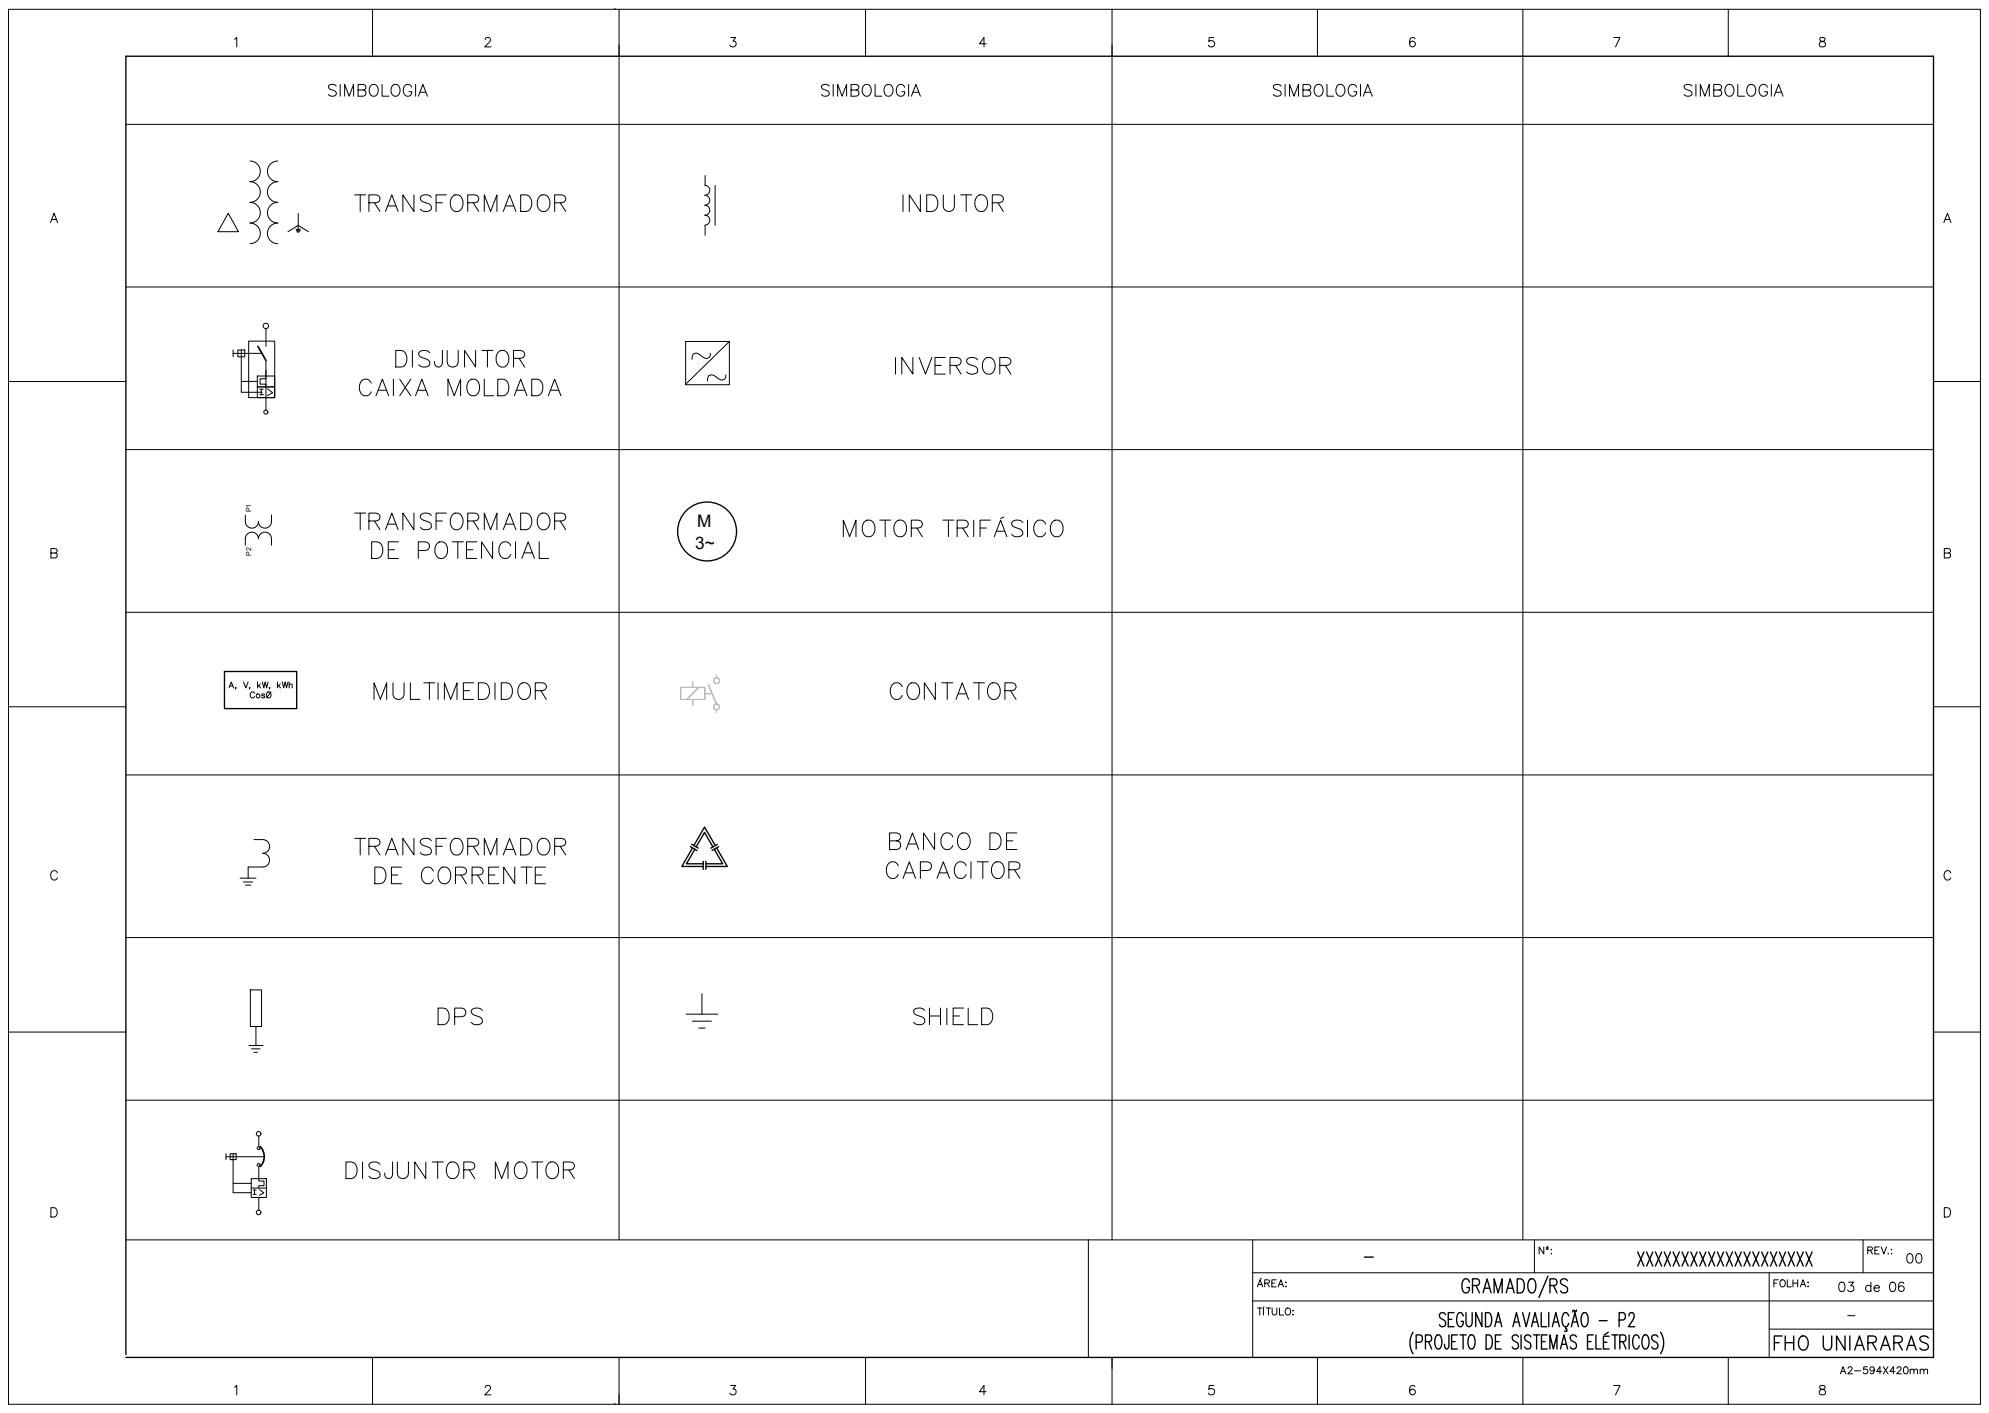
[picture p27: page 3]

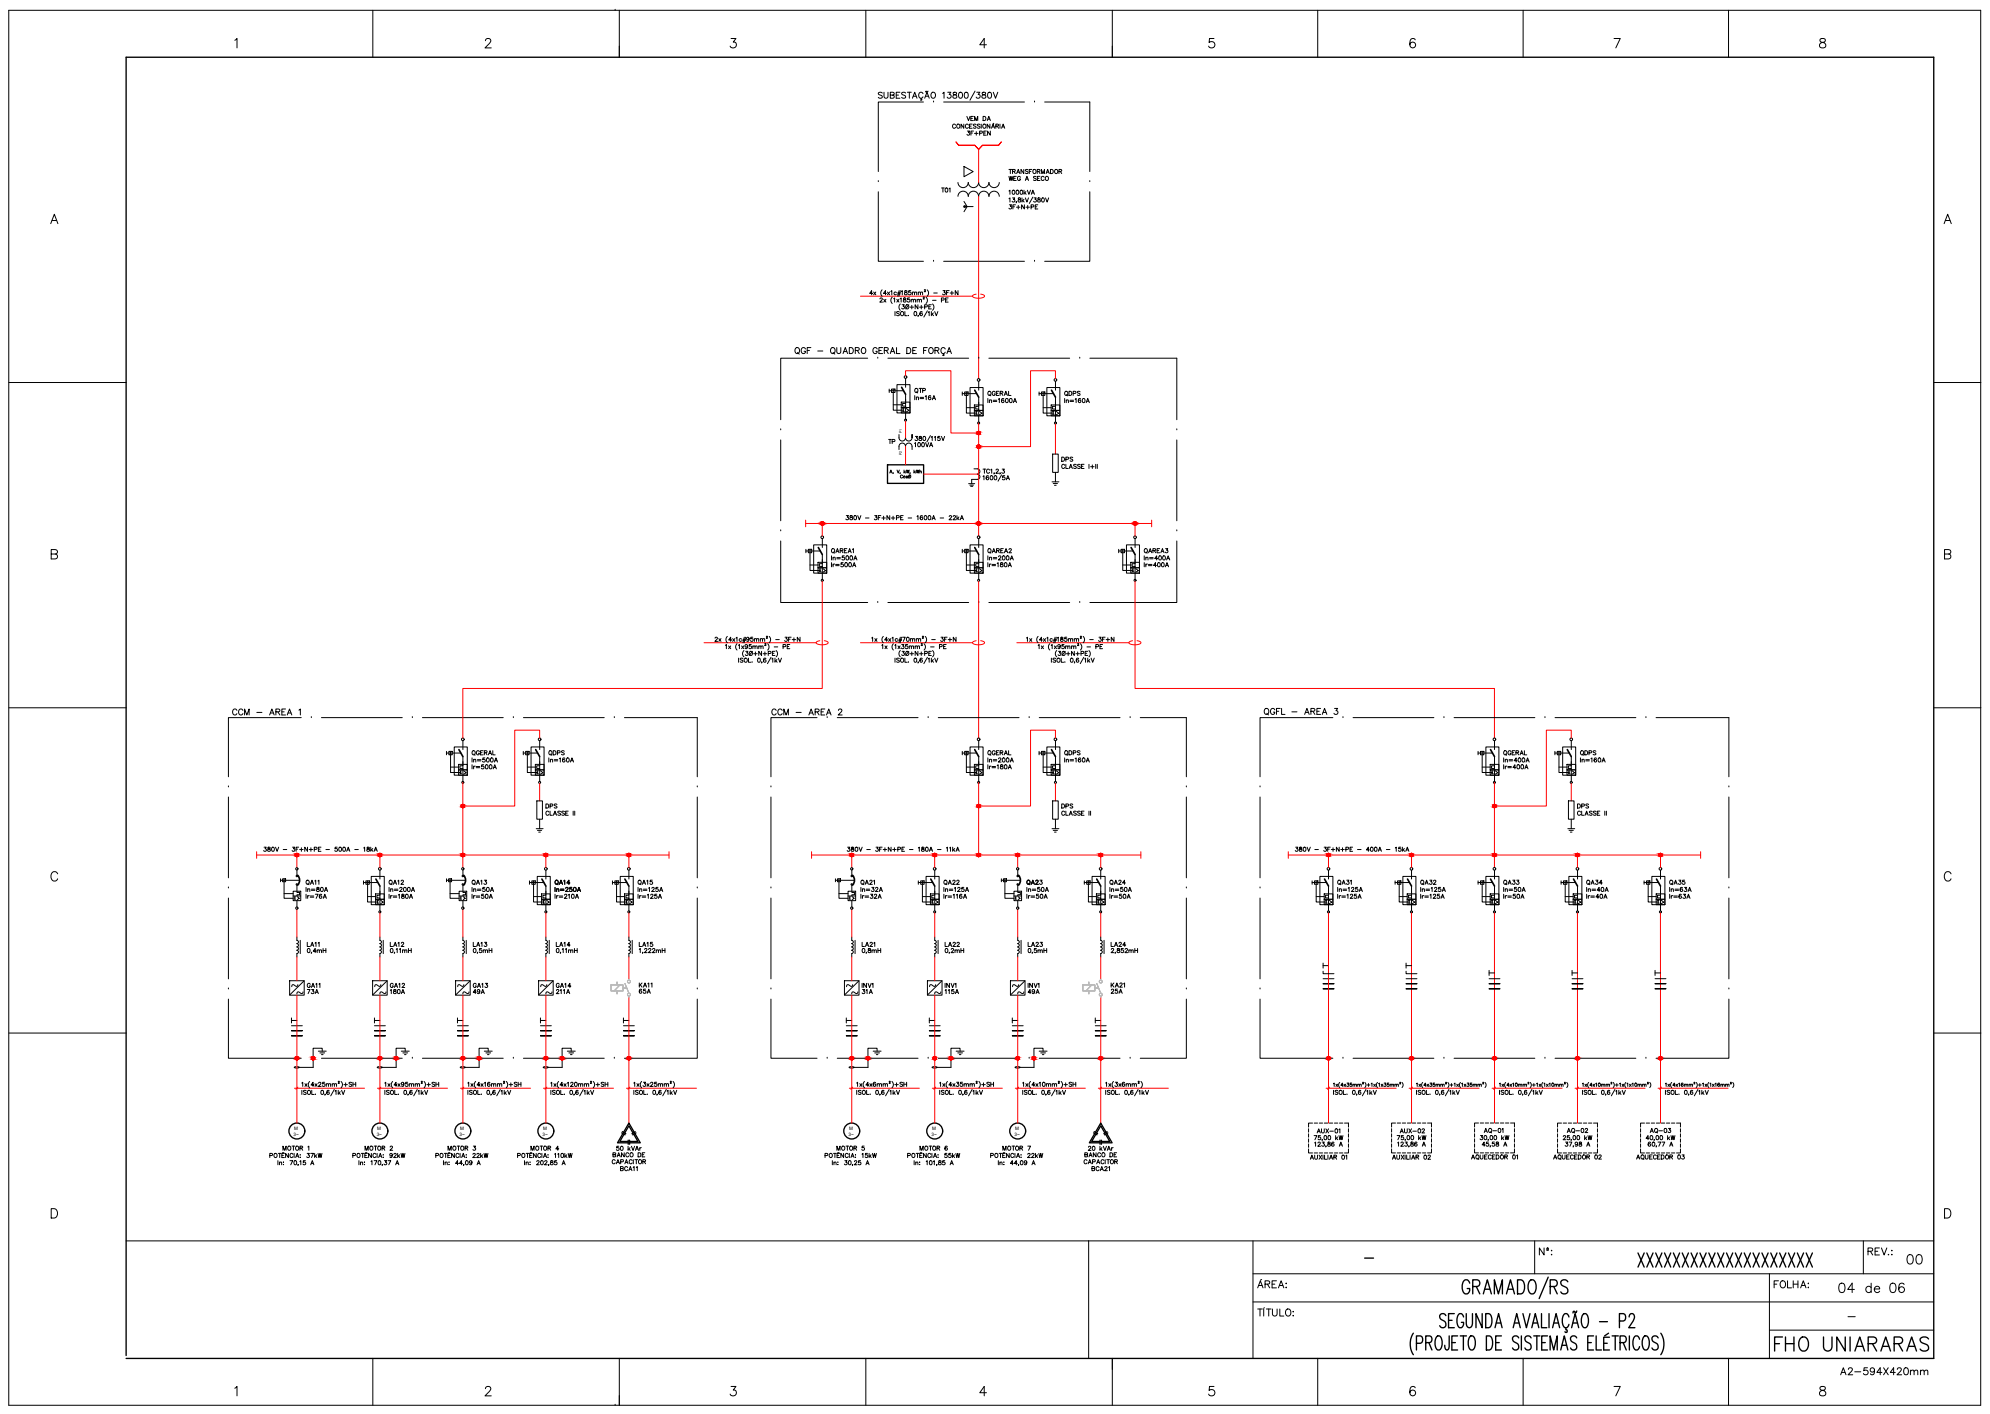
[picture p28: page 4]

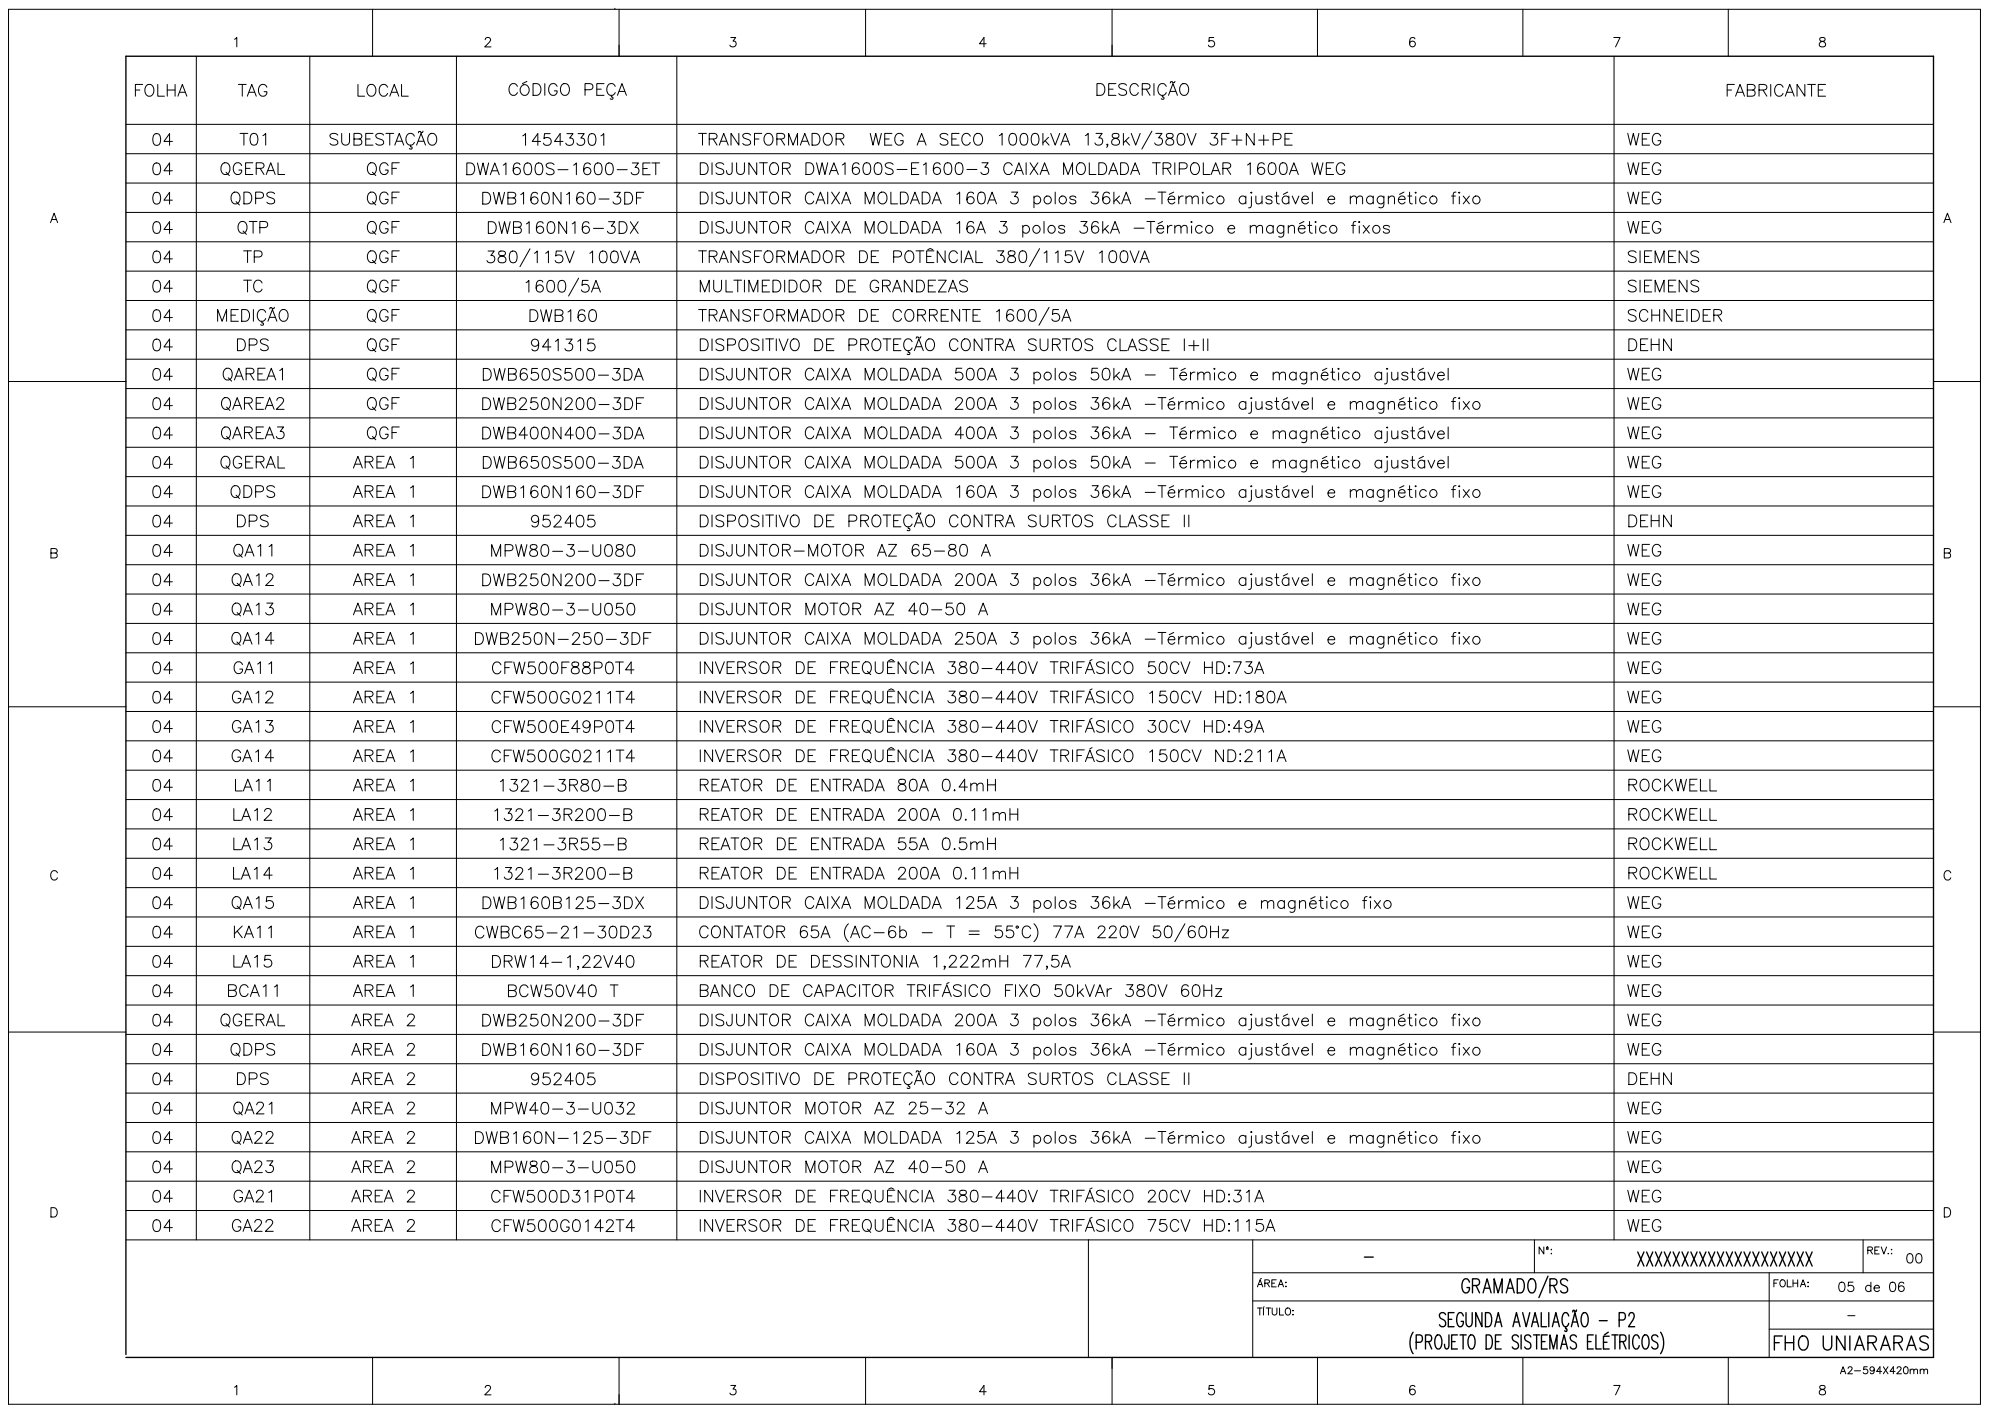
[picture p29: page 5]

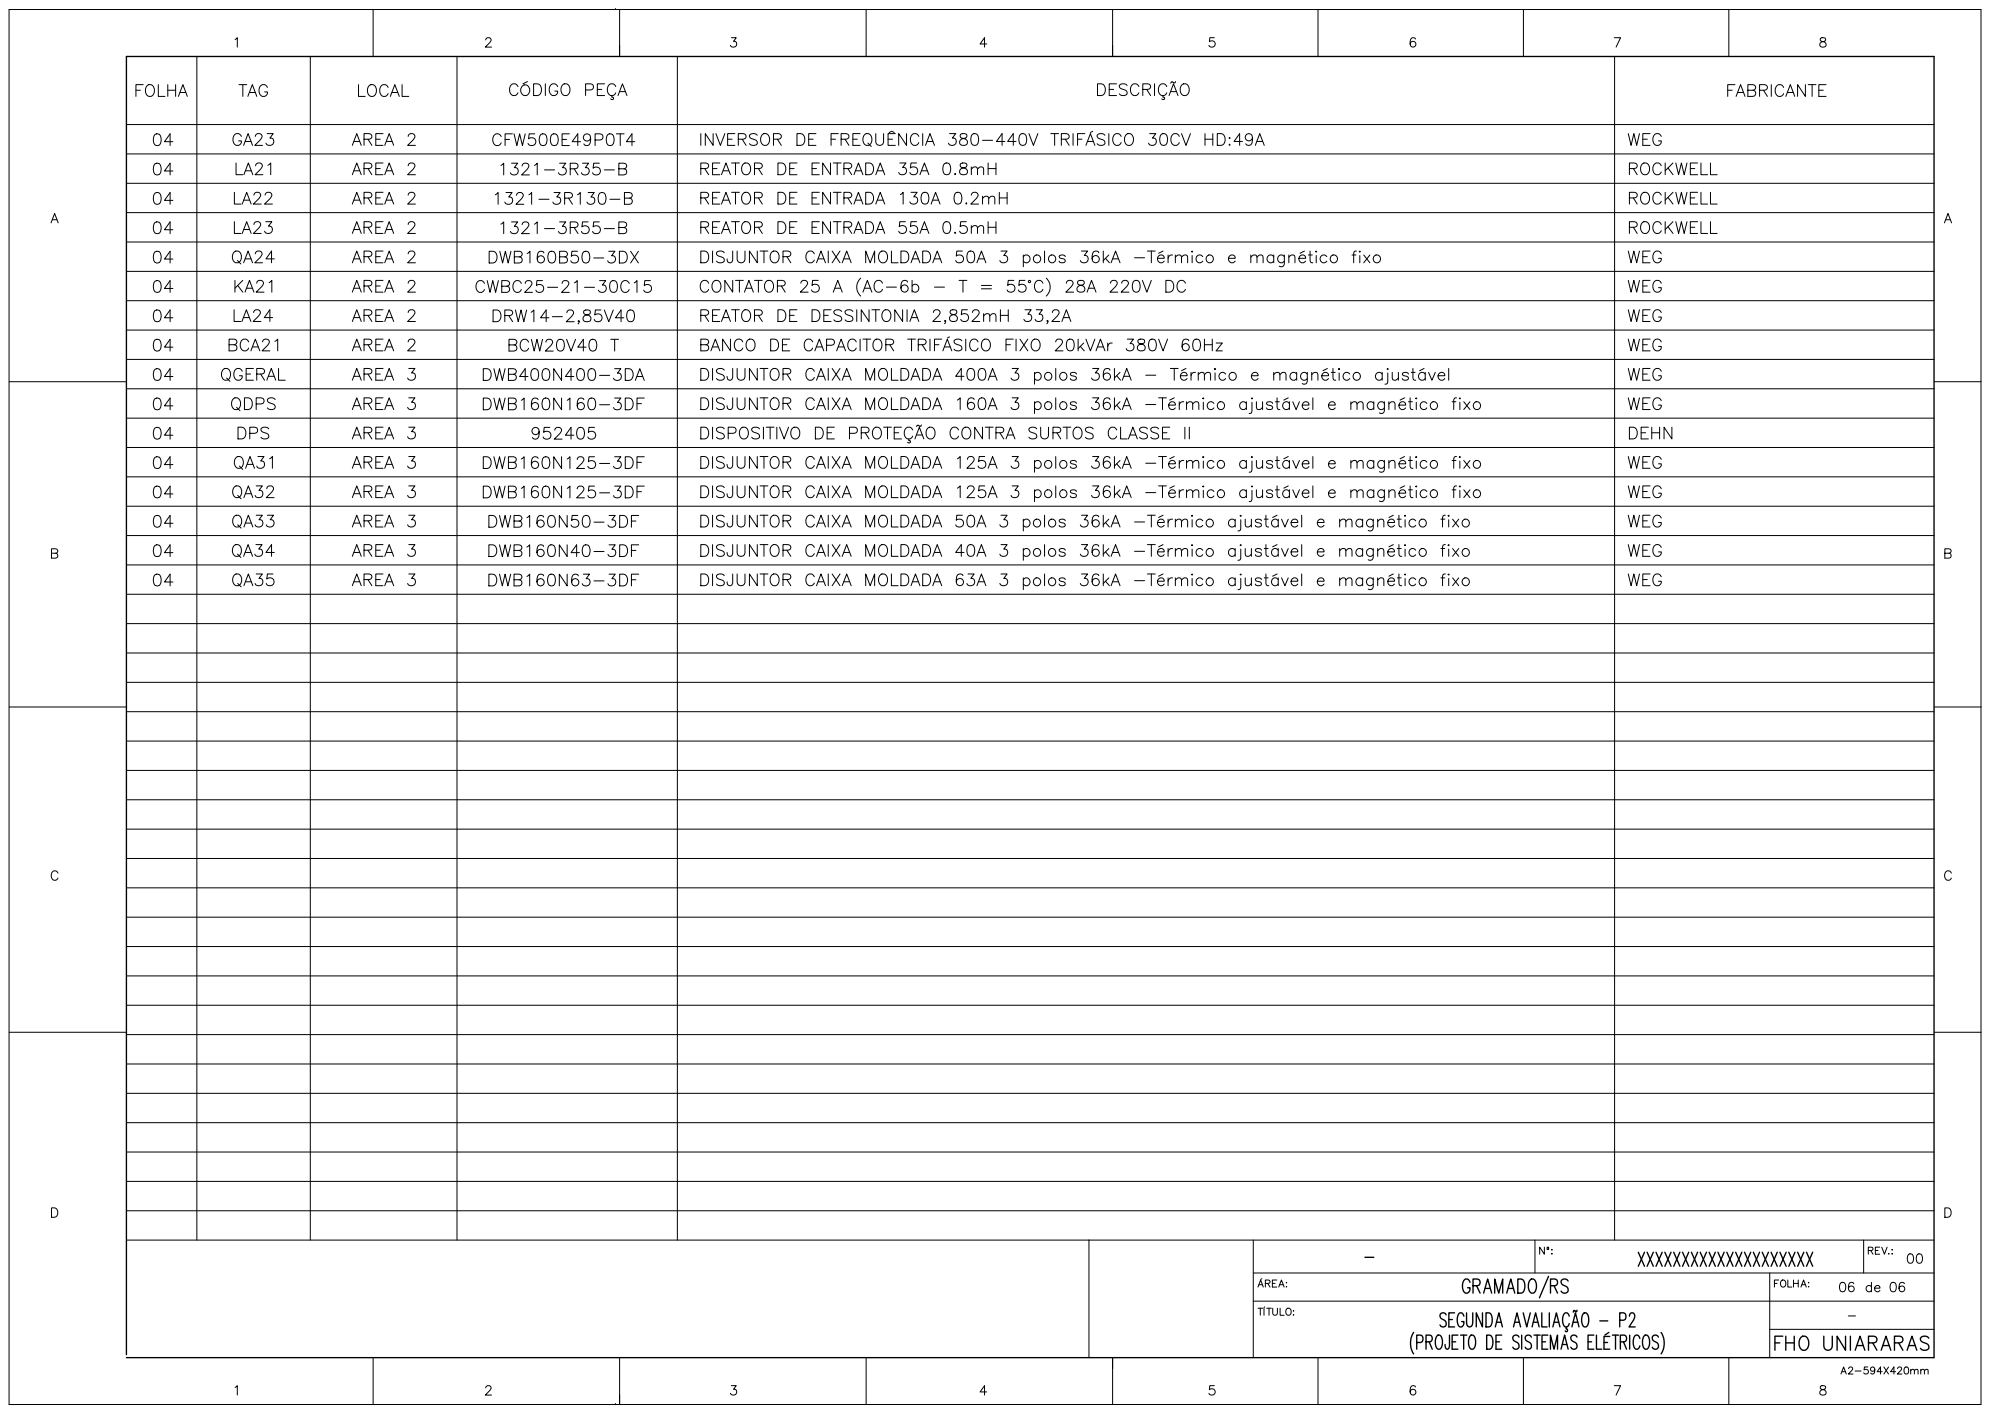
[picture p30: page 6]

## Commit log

2025-06-13 Rename DIAGRAMA UNIFILAR_R0.dwg to DIAGRAMA UNIFILAR/DIAGRAMA UNIFILAR_R0.dwg
    [DIAGRAMA UNIFILAR_R0.dwg]
2025-06-13 Rename CÁLCULO DE C.C - P2_R0.xlsx to CÁLCULO DE CURTO-CIRCUITO/CÁLCULO DE C.C - P2_R0.xlsx
    [CÁLCULO DE C.C - P2_R0.xlsx]
2025-06-13 Update and rename SIMULAÇÃO - PSP_R0.psp to CÁLCULO DE CURTO-CIRCUITO/SIMULAÇÃO - PSP_R0.psp
2025-06-13 Rename TABELA RESULTADOS_R0.xlsx to TABELA DE CÁLCULO/TABELA RESULTADOS_R0.xlsx
    [TABELA RESULTADOS_R0.xlsx]
